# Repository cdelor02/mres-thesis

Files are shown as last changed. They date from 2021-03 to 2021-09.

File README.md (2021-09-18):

Thesis for Masters in Research in [Medical Robotics and Image Guided Intervention](https://www.imperial.ac.uk/study/pg/medicine/medical-robotics/) at [Imperial College London](https://www.imperial.ac.uk), 2020-2021.

- Remember to run the setup for EIDORS in MATLAB if it isn't already on the path

Packages and modules used:
- [EIDORS](http://eidors3d.sourceforge.net)
- [gmsh](https://gmsh.info)
- [mesh2matlab](https://github.com/Jimbles/meshio2matlab)
- [OpenCV](https://opencv.org)
- [NumPy](https://numpy.org)
- [Scikit-learn](https://scikit-learn.org/stable/)
- [Tensorflow](https://www.tensorflow.org)
- [Keras](https://keras.io)
- [ffmpeg](https://www.ffmpeg.org)

Resources:
- [Soft robotics toolkit](https://softroboticstoolkit.com/home)

Software used:
- [ParaView](https://www.paraview.org)
- [SolidWorks](https://www.solidworks.com)
- [AutoCAD Inventor (v2021)](https://www.autodesk.co.uk/products/inventor/overview)
- [MATLAB](https://www.mathworks.com/products/matlab.html)
- [LabVIEW](https://www.ni.com/en-gb/shop/labview.html)
- [Arduino](https://www.arduino.cc)

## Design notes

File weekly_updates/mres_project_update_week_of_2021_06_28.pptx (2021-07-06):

## EIT x Soft Robots: project update

Week of Monday 28/06/2021

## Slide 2

Things to do/I’m doing

- Do multiple iterations of actuator tests to gather more data
- Refine actuator design (new moulds, iterate on actuator until a satisfactory design)
- Work on OpenCV point tracking to get ground truth data
- Investigate ML solutions for control problem (possibly just with voltages, may need full EIT images)

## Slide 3

SDM actuator with cable setup

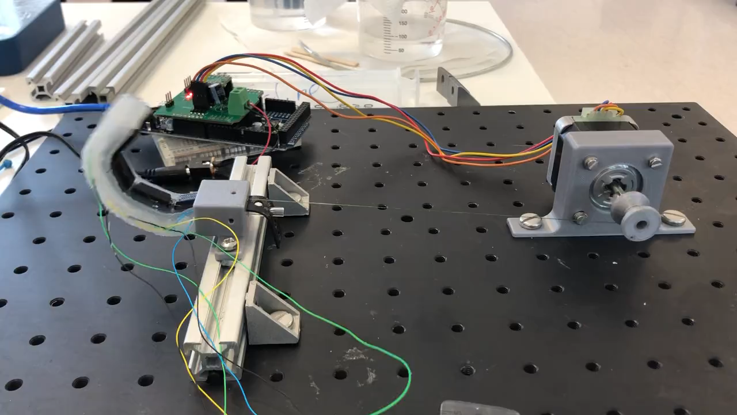
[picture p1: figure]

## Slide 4

EIT data of SDM actuator in stepper rig

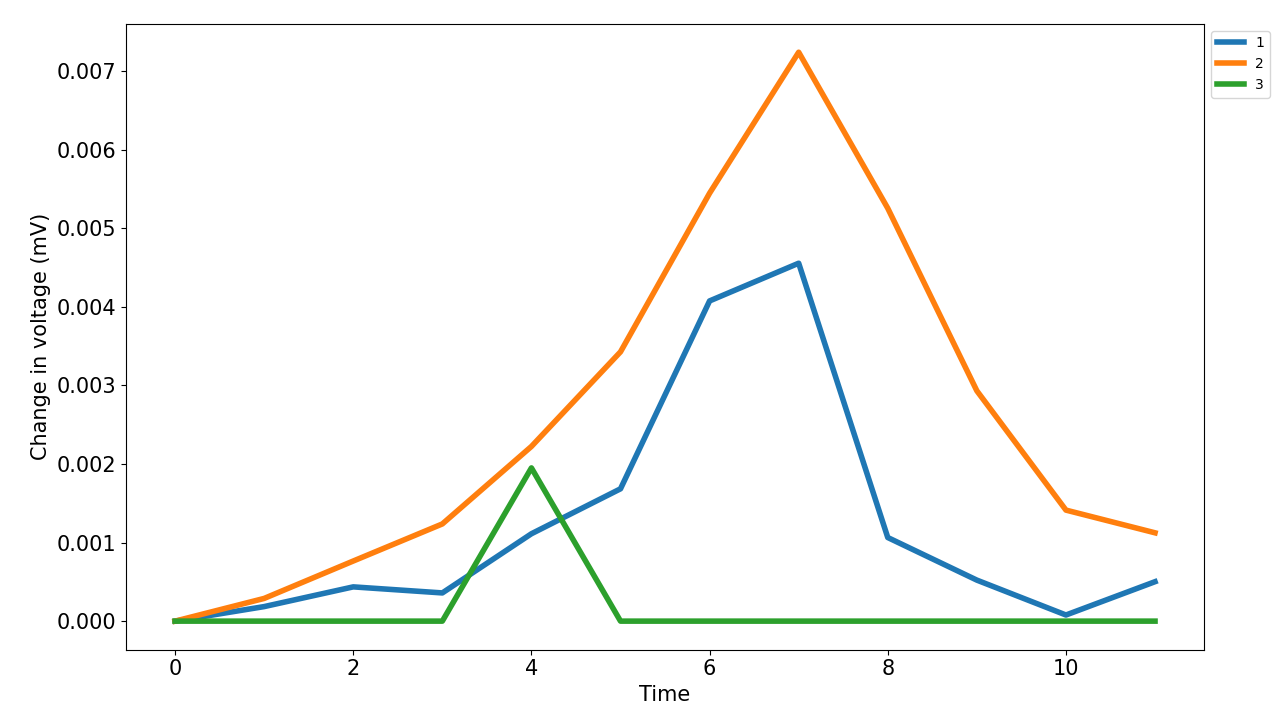
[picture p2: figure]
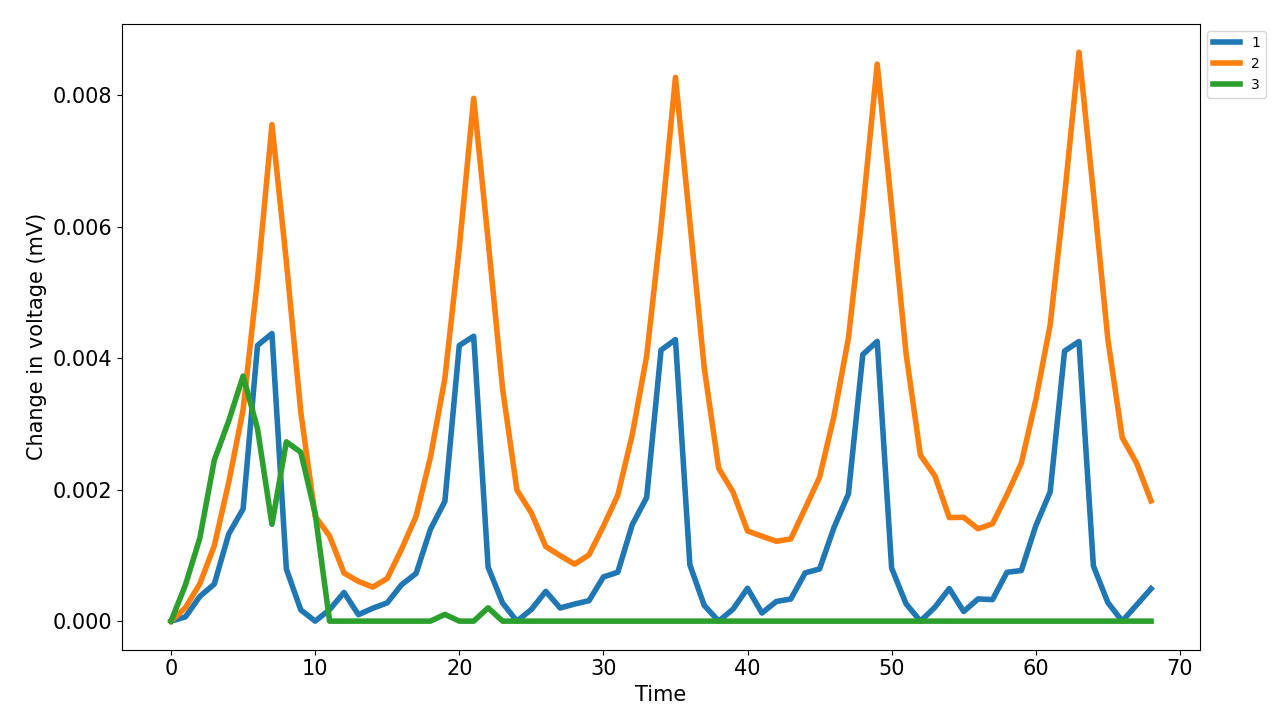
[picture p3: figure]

1 iteration

5 iterations

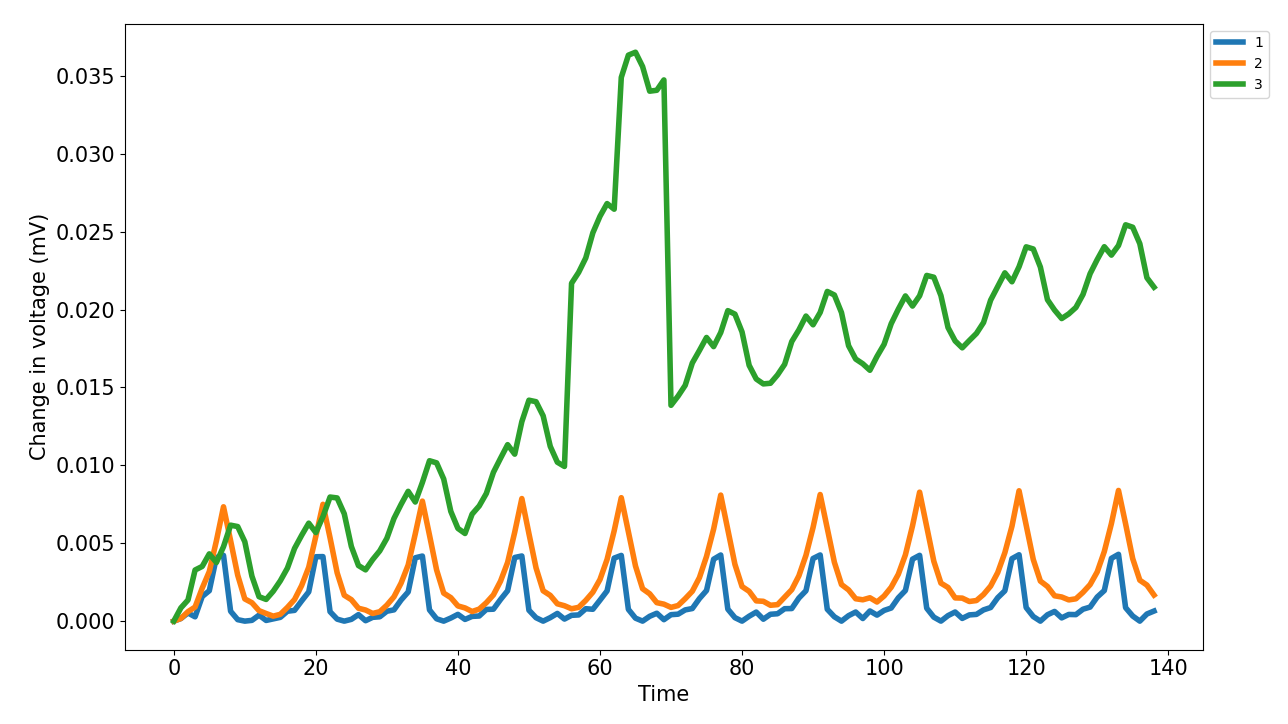
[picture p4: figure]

10 iterations

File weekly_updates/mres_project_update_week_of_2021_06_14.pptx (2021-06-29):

## EIT x Soft Robots: project update

Week of Monday 14/06/2021

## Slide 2

Project poster

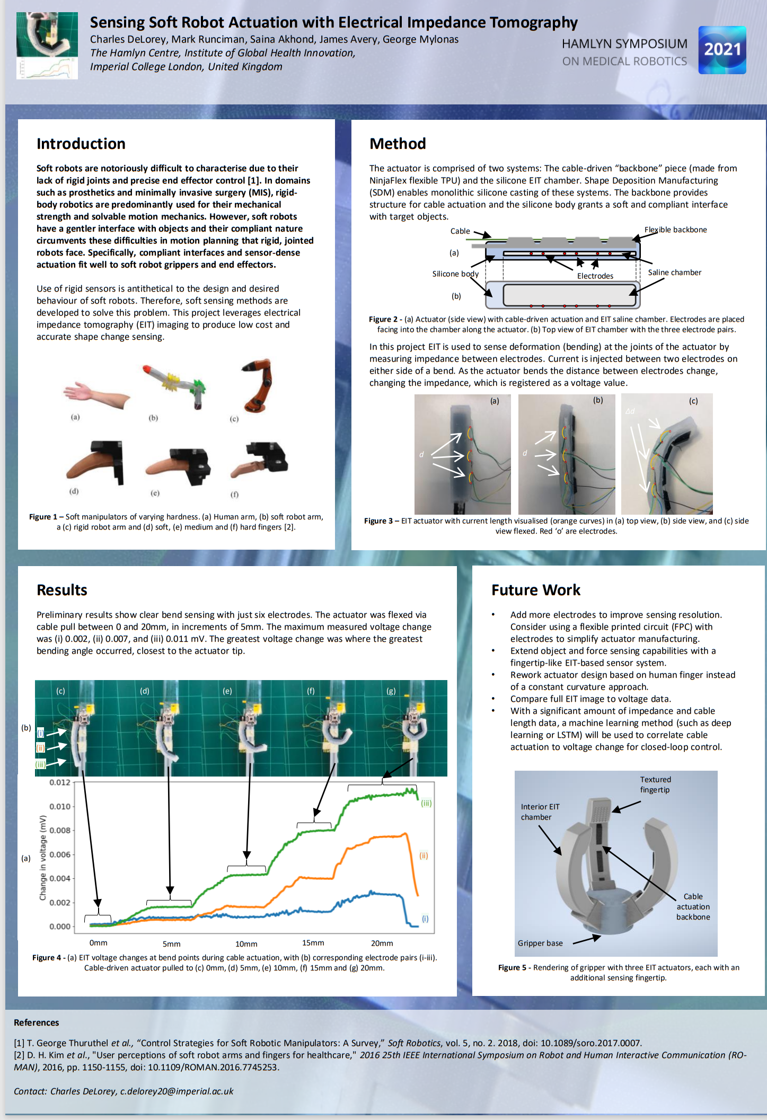
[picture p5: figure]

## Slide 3

TODO

- Add stepper motor to get set/predictable actuation
- Do multiple iterations of actuator tests to gather more data
- Investigate ML solutions for control problem (possibly just with voltages, may need full EIT images)
- Refine actuator design (new moulds, iterate on actuator until a satisfactory design)

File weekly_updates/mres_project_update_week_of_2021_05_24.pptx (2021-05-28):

## EIT x Soft Robots: project update

Week of Monday 24/05/2021

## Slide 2

Actuator with anterior EIT chamber

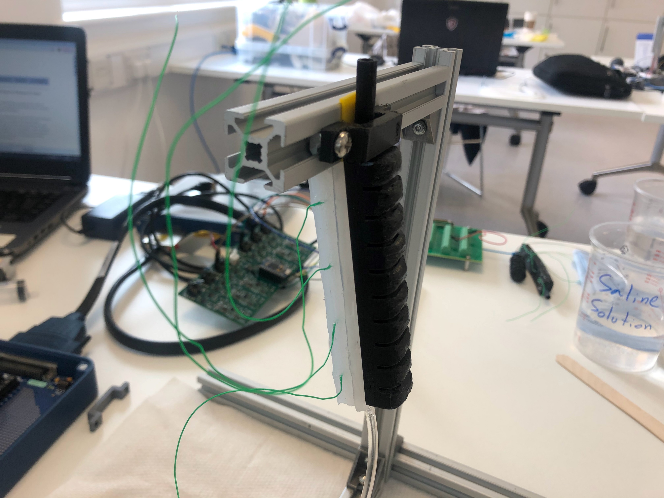
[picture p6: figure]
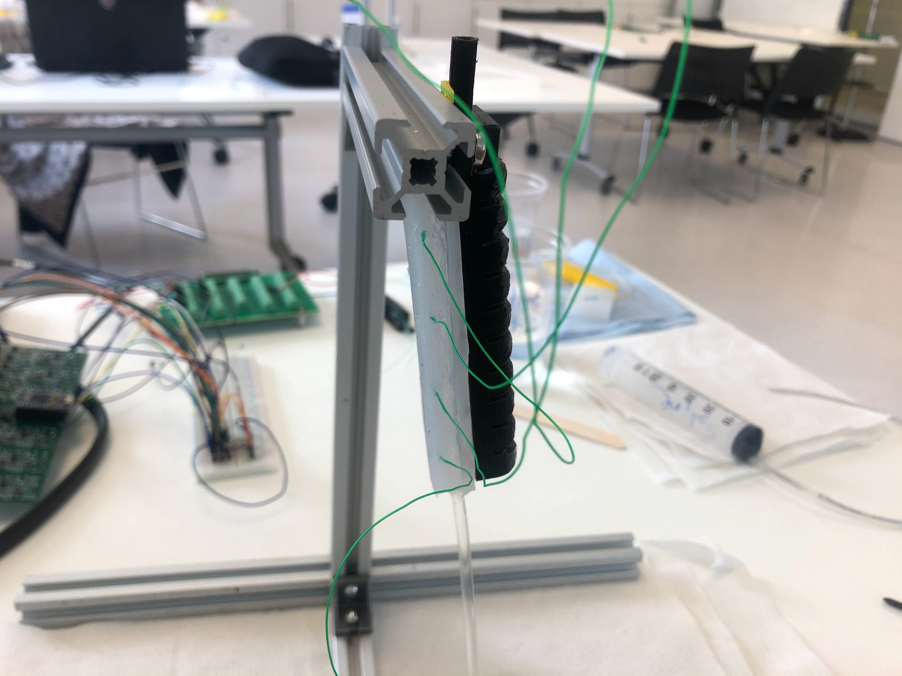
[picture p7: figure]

Silicone layer to affix EIT chamber to actuator surface

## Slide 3

Actuator with anterior EIT chamber

Noise?

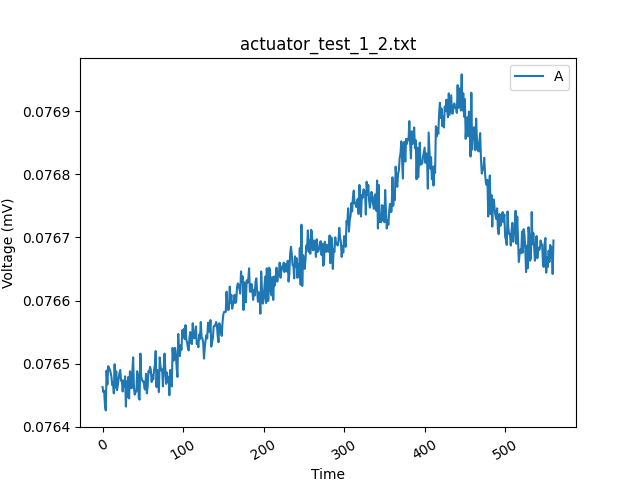
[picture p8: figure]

Voltage reading over a 60ml pneumatic actuation (10ml at a time, ~1-2s per 10ml)

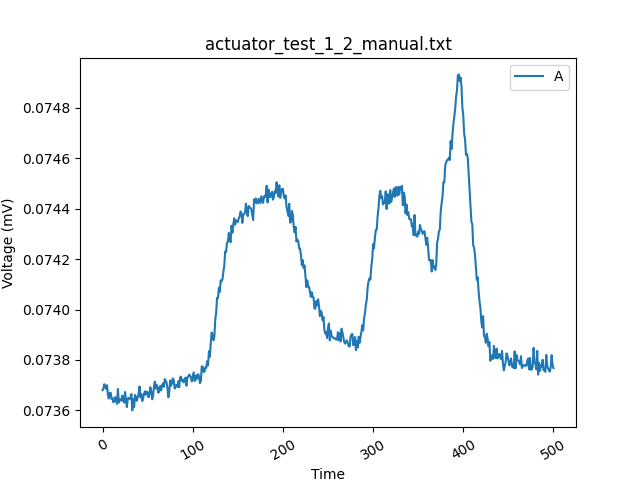
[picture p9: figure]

Actuated, but not enough change to see difference

Actuated to 22.5°

Actuated to 22.5°

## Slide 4

New idea: SDM actuator with EIT chamber

Noise?

Voltage reading over a 60ml pneumatic actuation (10ml at a time, ~1-2s per 10ml)

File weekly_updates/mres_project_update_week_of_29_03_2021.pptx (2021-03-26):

## EIT x Soft Robots: project update

Week of Monday 29/03/2021

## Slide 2

Work accomplished this past week:

- Refined EIDORS simulation
- Begin fabricating a simple actuator

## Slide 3

Pneunet mesh with electrode locations

6 electrodes
Lengths are in meters

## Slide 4

EIDORS simulations of simple 2-joint actuator

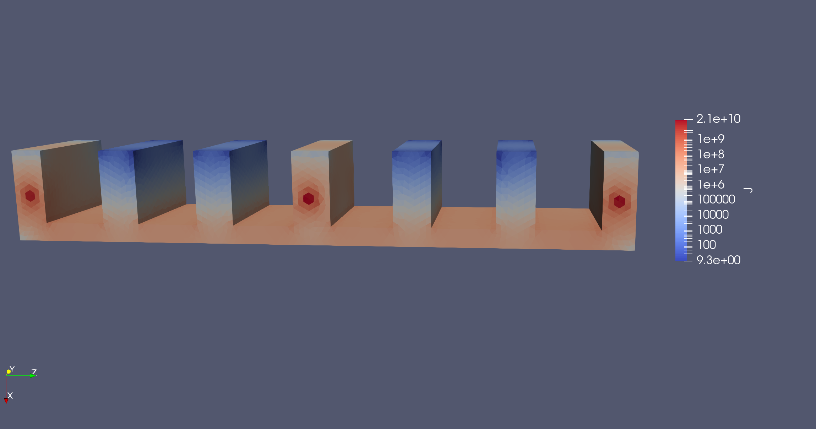
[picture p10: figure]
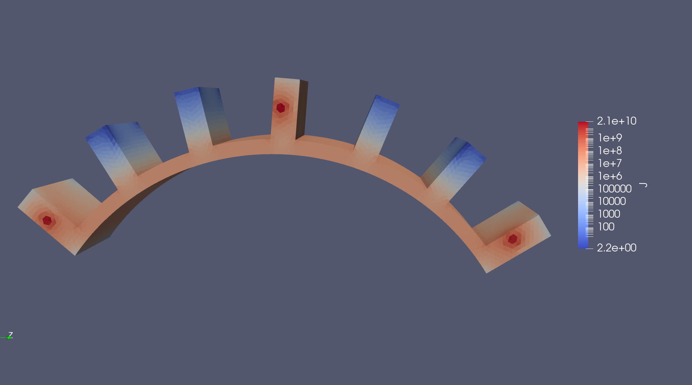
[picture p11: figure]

No bend

First bend

- Visualized with ParaView
- Log scale

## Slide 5

Voltages for each finger configuration:

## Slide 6

To do for this upcoming week:

- ~~Refine EIDORS simulation~~
- ~~Begin fabricating a simple actuator~~
- ~~Revise literature review~~

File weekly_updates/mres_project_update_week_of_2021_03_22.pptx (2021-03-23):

## EIT x Soft Robots: project update

Week of Monday 22/03/2021

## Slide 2

Work accomplished this past week:

- Completed online training courses
- Produced EIT images of simple finger model

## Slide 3

Finger mesh with electrode locations

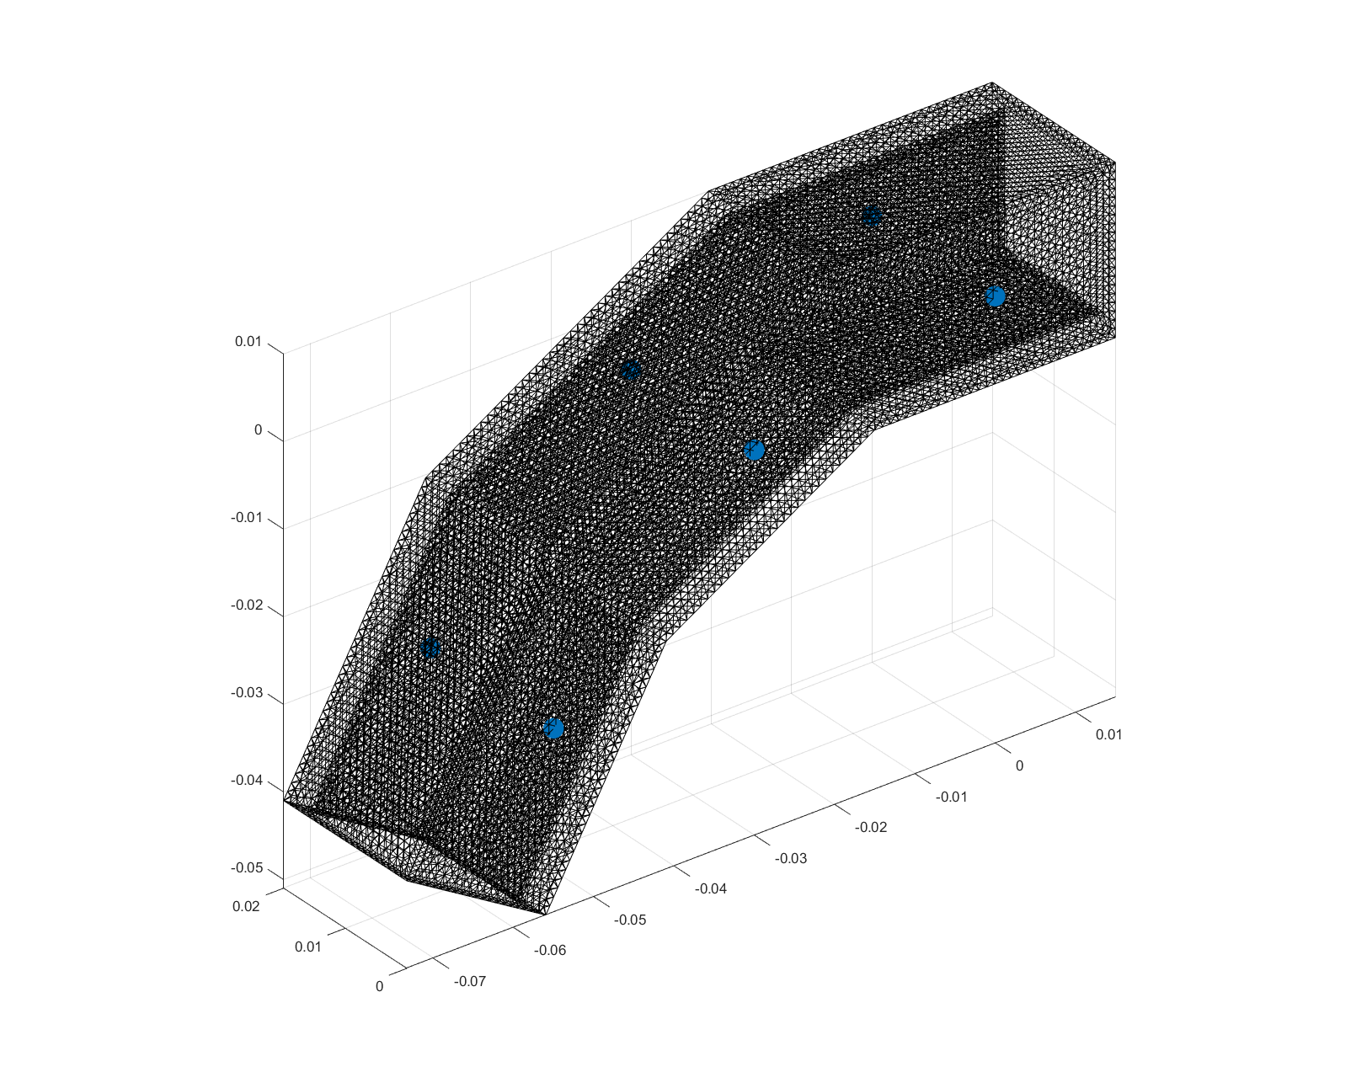
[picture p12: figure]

6 electrodes
Actuator wall is 2 mm thick
Lengths are in meters

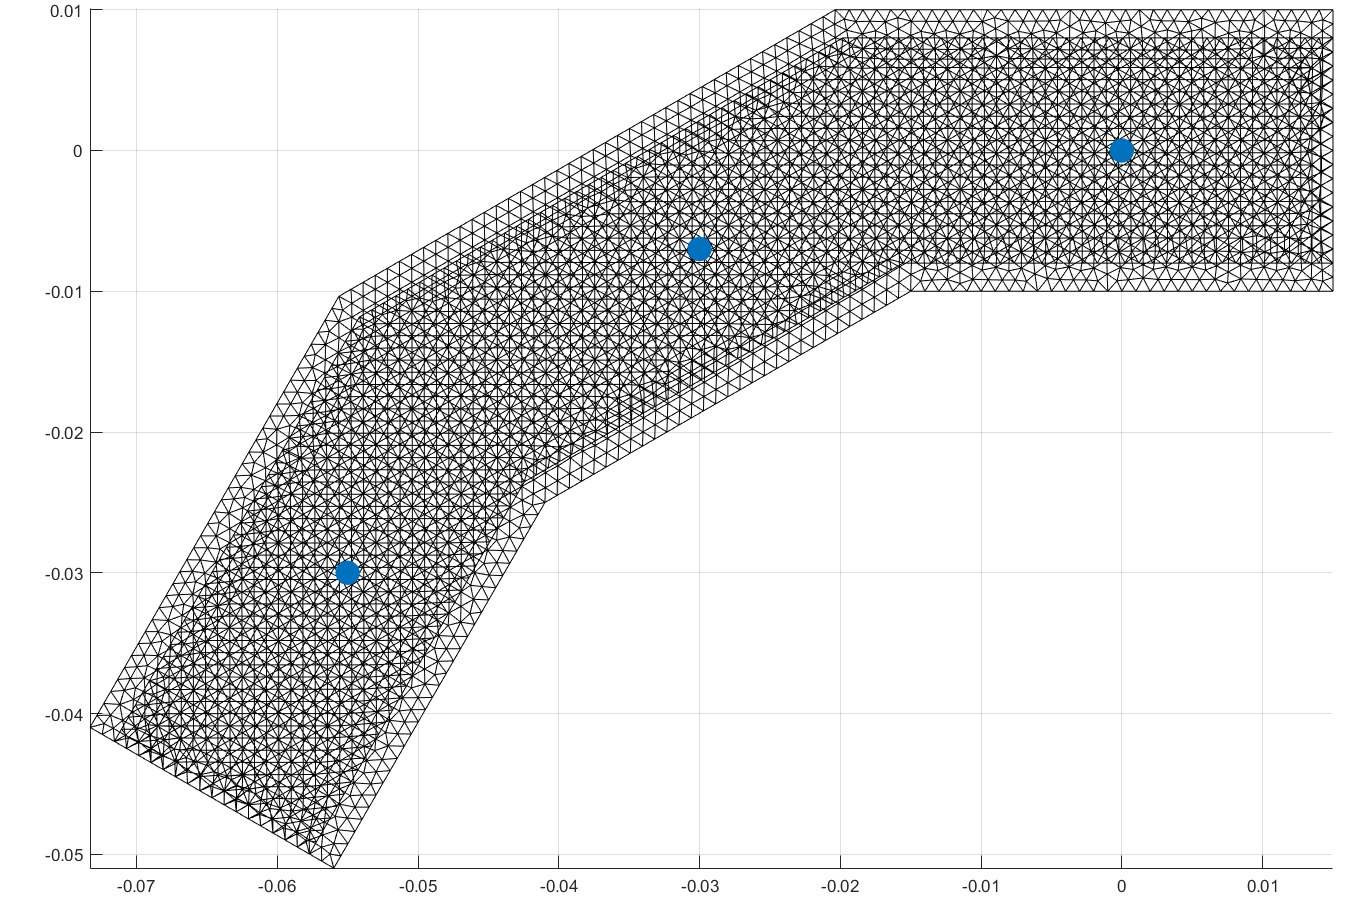
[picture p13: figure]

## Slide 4

EIDORS simulations of simple 2-joint actuator

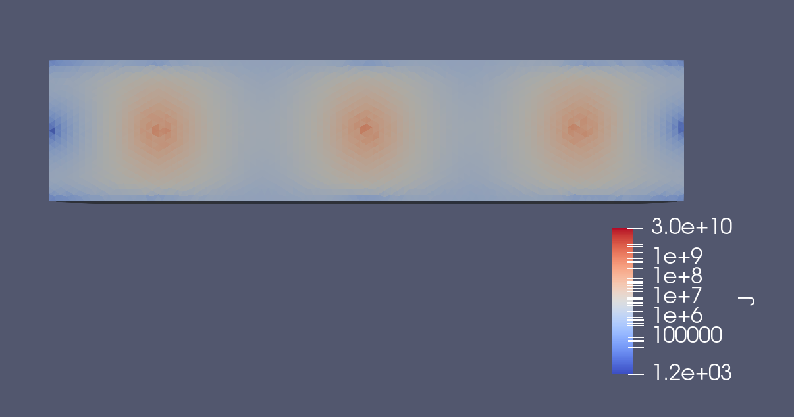
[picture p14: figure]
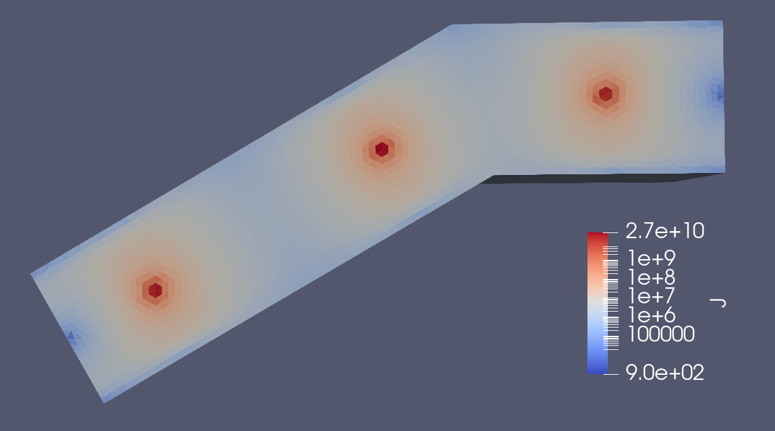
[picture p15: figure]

No bend

1 bend

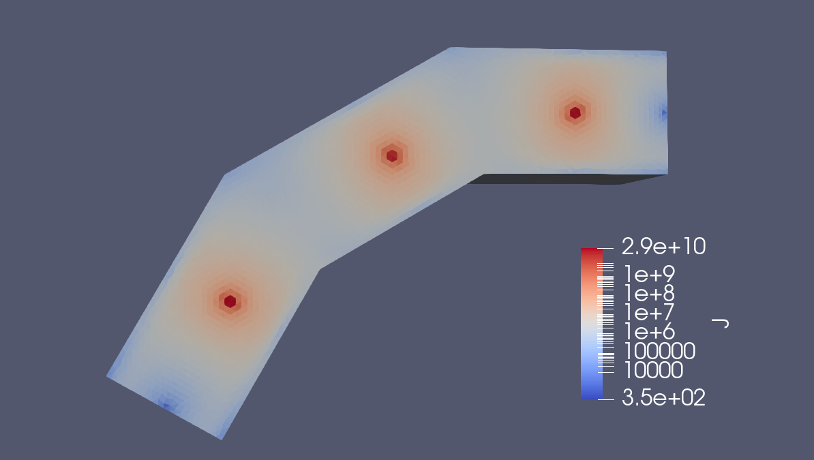
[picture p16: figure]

- Visualized with ParaView
- Log scale

2 bends

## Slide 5

Voltages for each finger configuration:

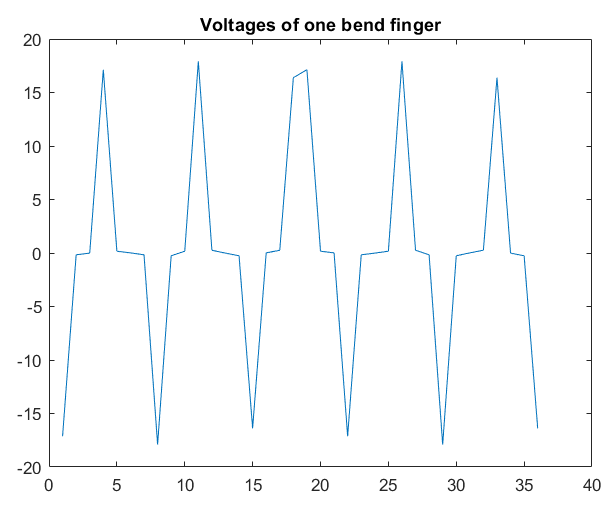
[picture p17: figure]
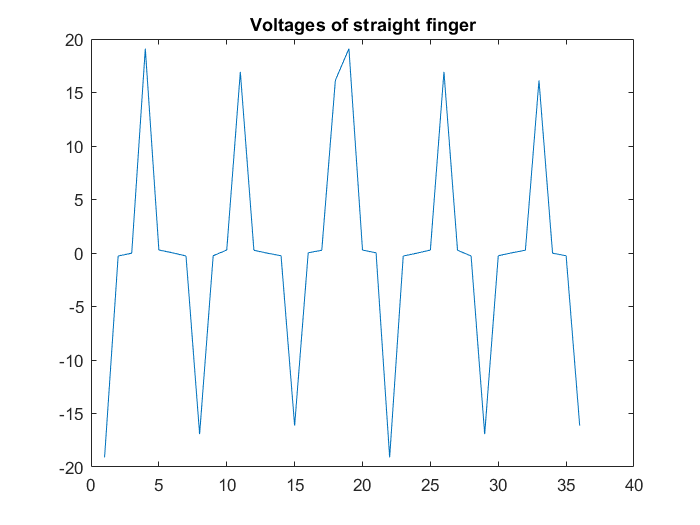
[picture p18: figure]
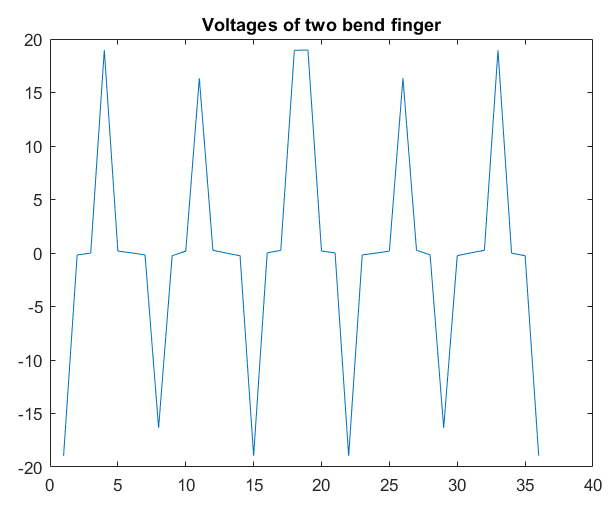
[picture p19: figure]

- Very slight changes

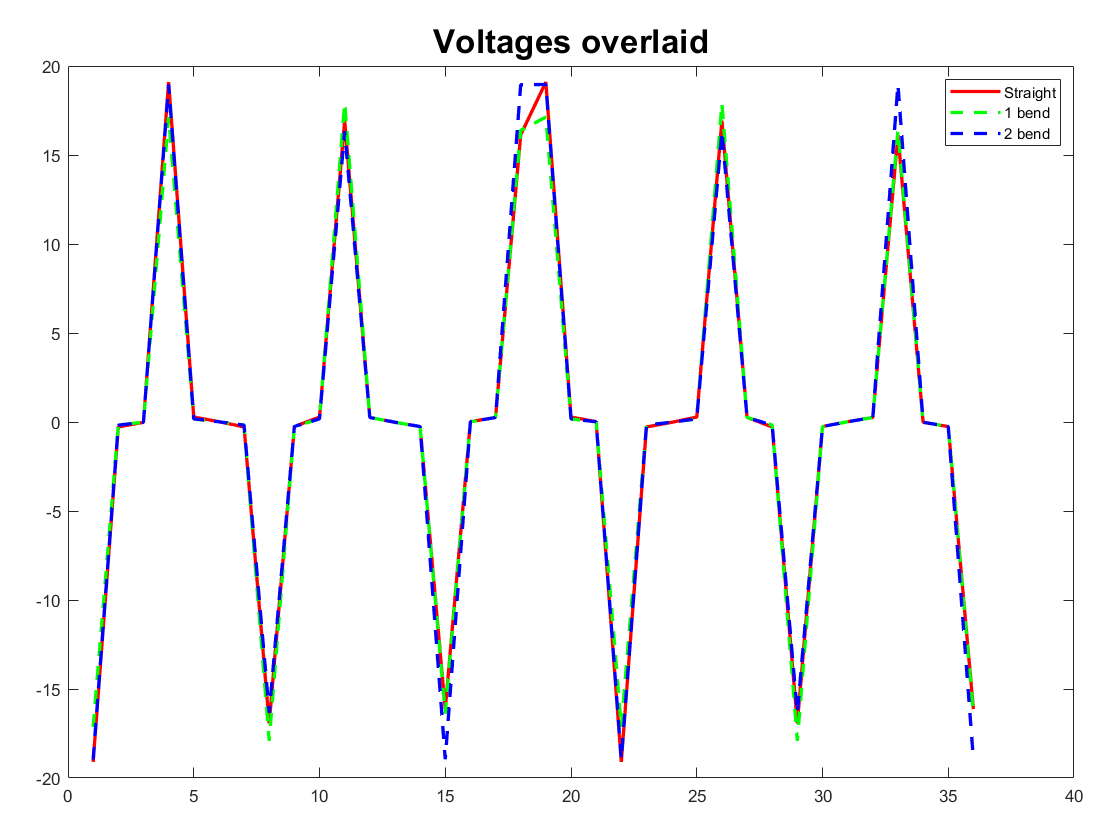
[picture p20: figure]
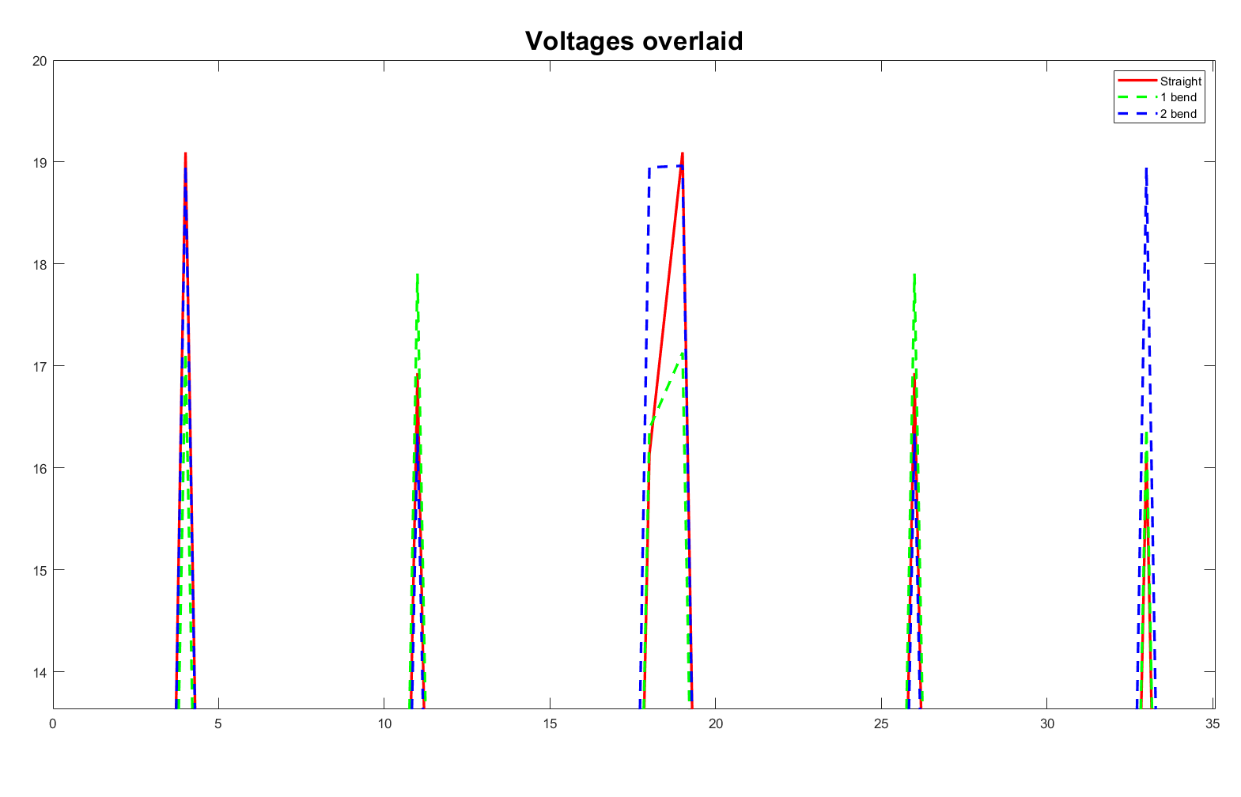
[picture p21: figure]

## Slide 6

To do for this upcoming week:

- Refine EIDORS simulation
- Begin fabricating a simple actuator
- Revise literature review

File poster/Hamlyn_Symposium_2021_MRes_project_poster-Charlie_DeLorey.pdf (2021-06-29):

# Introduction

Soft robots are notoriously difficult to characterise due to their lack of rigid joints and precise end effector control [1]. In domains such as prosthetics and minimally invasive surgery (MIS), rigidbody robotics are predominantly used for their mechanical strength and solvable motion mechanics. However, soft robots have a gentler interface with objects and their compliant nature circumvents these difficulties in motion planning that rigid, jointed robots face. Specifically, compliant interfaces and sensor-dense actuation fit well to soft robot grippers and end effectors.

Use of rigid sensors is antithetical to the design and desired behaviour of soft robots. Therefore, soft sensing methods are developed to solve this problem. This project leverages electrical impedance tomography (EIT) imaging to produce low cost and accurate shape change sensing.

# Method

The actuator is comprised of two systems: The cable-driven “backbone” piece (made from NinjaFlex flexible TPU) and the silicone EIT chamber. Shape Deposition Manufacturing (SDM) enables monolithic silicone casting of these systems. The backbone provides structure for cable actuation and the silicone body grants a soft and compliant interface with target objects.

# Future Work

- Add more electrodes to improve sensing resolution. Consider using a flexible printed circuit (FPC) with electrodes to simplify actuator manufacturing.
- Extend object and force sensing capabilities with a fingertip-like EIT-based sensor system.
- Rework actuator design based on human finger instead of a constant curvature approach.
- Compare full EIT image to voltage data.
- With a significant amount of impedance and cable length data, a machine learning method (such as deep learning or LSTM) will be used to correlate cable actuation to voltage change for closed-loop control.

# Results

Preliminary results show clear bend sensing with just six electrodes. The actuator was flexed via cable pull between 0 and 20mm, in increments of 5mm. The maximum measured voltage change was (i) 0.002, (ii) 0.007, and (iii) 0.011 mV. The greatest voltage change was where the greatest bending angle occurred, closest to the actuator tip.

# Sensing Soft Robot Actuation with Electrical Impedance Tomography

Charles DeLorey, Mark Runciman, Saina Akhond, James Avery, George Mylonas
The Hamlyn Centre, Institute of Global Health Innovation,
Imperial College London, United Kingdom

References

[1] T. George Thuruthel et al., “Control Strategies for Soft Robotic Manipulators: A Survey,” Soft Robotics, vol. 5, no. 2. 2018, doi: 10.1089/soro.2017.0007.
[2] D. H. Kim et al., "User perceptions of soft robot arms and fingers for healthcare," 2016 25th IEEE International Symposium on Robot and Human Interactive Communication (RO-MAN), 2016, pp. 1150-1155, doi: 10.1109/ROMAN.2016.7745253.

Contact: Charles DeLorey, c.delorey20@imperial.ac.uk

Figure 2 - (a) Actuator (side view) with cable-driven actuation and EIT saline chamber. Electrodes are placed facing into the chamber along the actuator. (b) Top view of EIT chamber with the three electrode pairs.

Figure 5 - Rendering of gripper with three EIT actuators, each with an additional sensing fingertip.

Figure 1 – Soft manipulators of varying hardness. (a) Human arm, (b) soft robot arm, a (c) rigid robot arm and (d) soft, (e) medium and (f) hard fingers [2].

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
Figure 3 – EIT actuator with current length visualised (orange curves) in (a) top view, (b) side view, and (c) side view flexed. Red ‘o’ are electrodes.

In this project EIT is used to sense deformation (bending) at the joints of the actuator by measuring impedance between electrodes. Current is injected between two electrodes on either side of a bend. As the actuator bends the distance between electrodes change, changing the impedance, which is registered as a voltage value.

Figure 4 - (a) EIT voltage changes at bend points during cable actuation, with (b) corresponding electrode pairs (i-iii). Cable-driven actuator pulled to (c) 0mm, (d) 5mm, (e) 10mm, (f) 15mm and (g) 20mm.

Cable | Flexible backbone
Silicone body | Saline chamber Electrodes

(a)

(b)

Textured
fingertip

Gripper base

Interior EIT
chamber

Cable
actuation
backbone

(a)

(b) | (c) | (d) | (e) | (f) (c) | (d) | (e) | (f) | (g)
(b) (i)

(ii)

(iii)

0mm | 5mm | 10mm | 15mm | 20mm

(iii)

(ii)

(i)

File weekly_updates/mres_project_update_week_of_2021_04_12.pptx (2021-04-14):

## EIT x Soft Robots: project update

Week of Monday 12/04/2021

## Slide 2

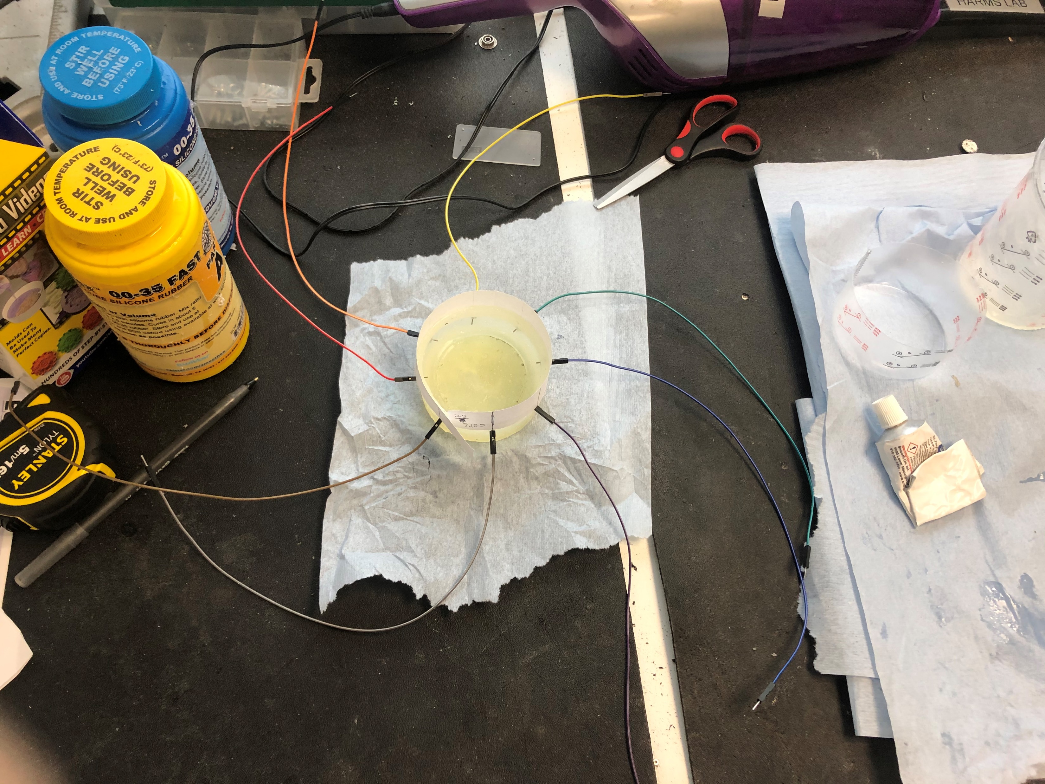
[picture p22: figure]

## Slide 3

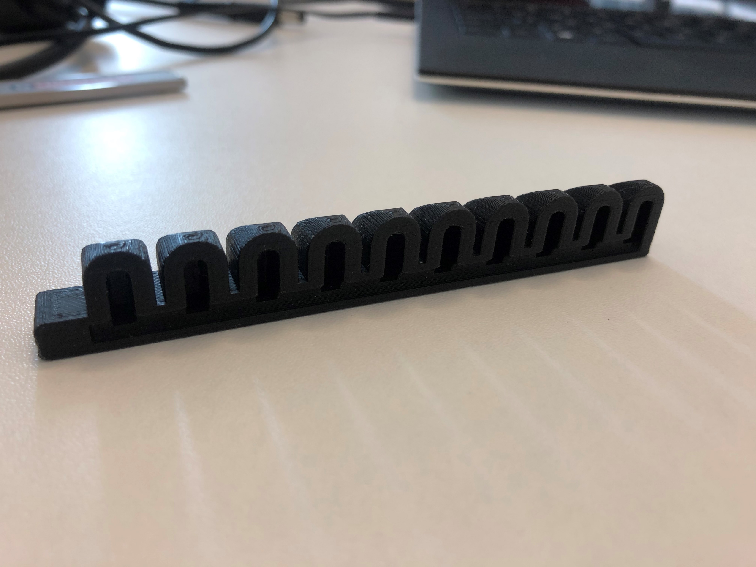
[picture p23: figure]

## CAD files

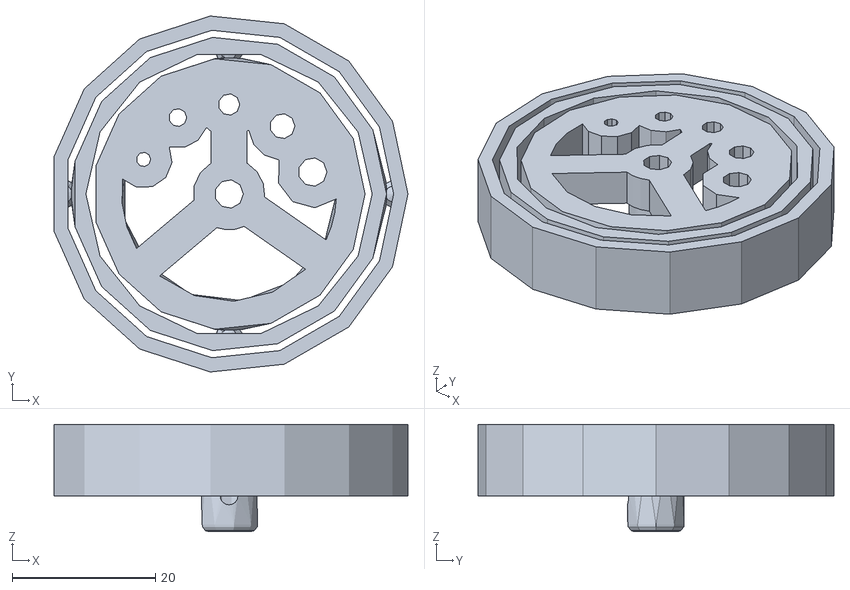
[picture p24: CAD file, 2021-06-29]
SDM_actuator/probe_gimbal/gimbal_assembly.stl
49.5 x 49.7 x 15.0

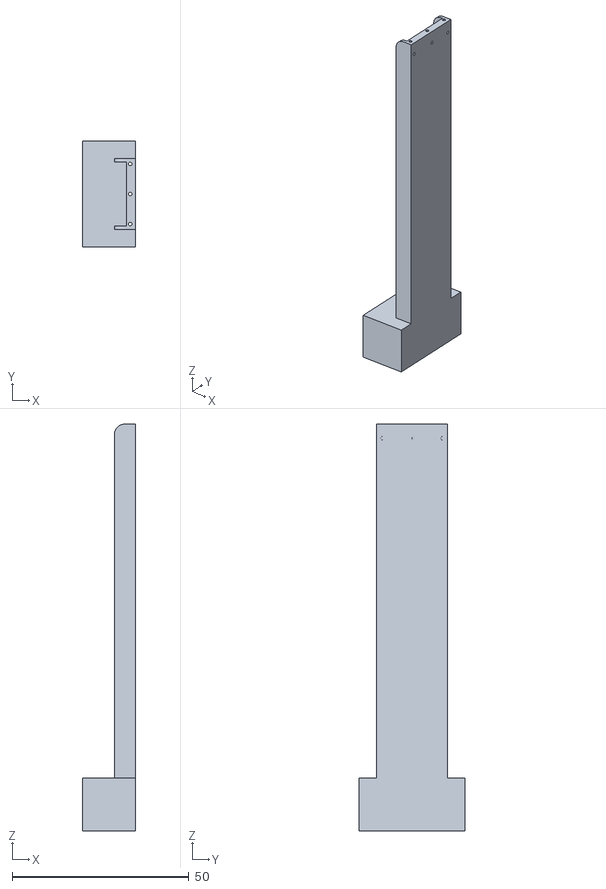
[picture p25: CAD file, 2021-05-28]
3d_printed_actuator/3D_print_actuator_cable_driven.stl
15.0 x 30.0 x 115.0

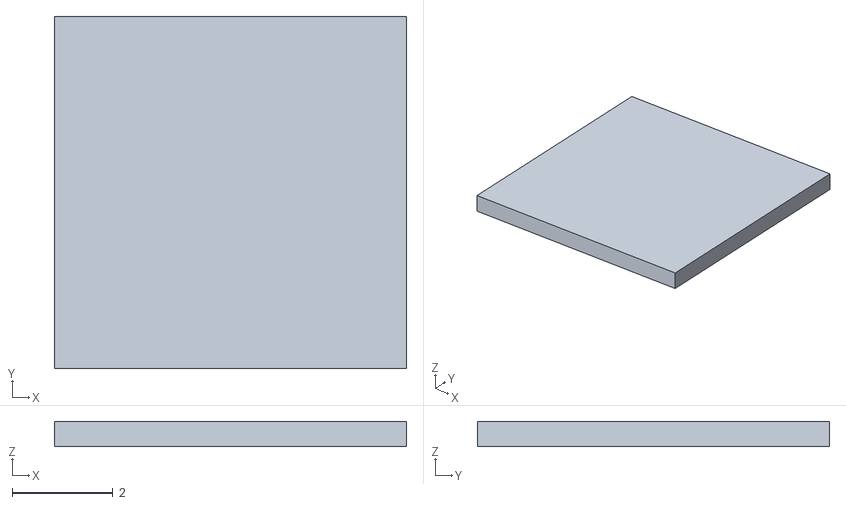
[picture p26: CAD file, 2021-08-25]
computer_vision/7mm_square.stl
7.00 x 7.00 x 0.5

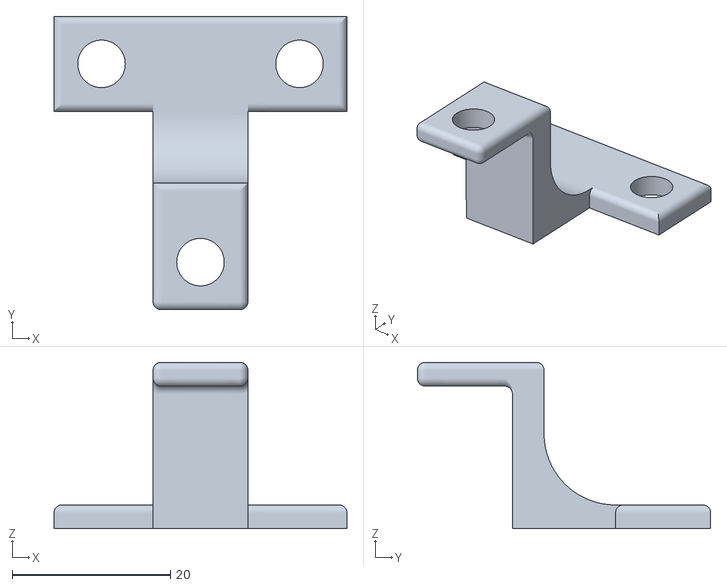
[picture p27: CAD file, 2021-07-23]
computer_vision/camera_3D_parts/new_camera_mount.stl
37.0 x 37.0 x 21.0

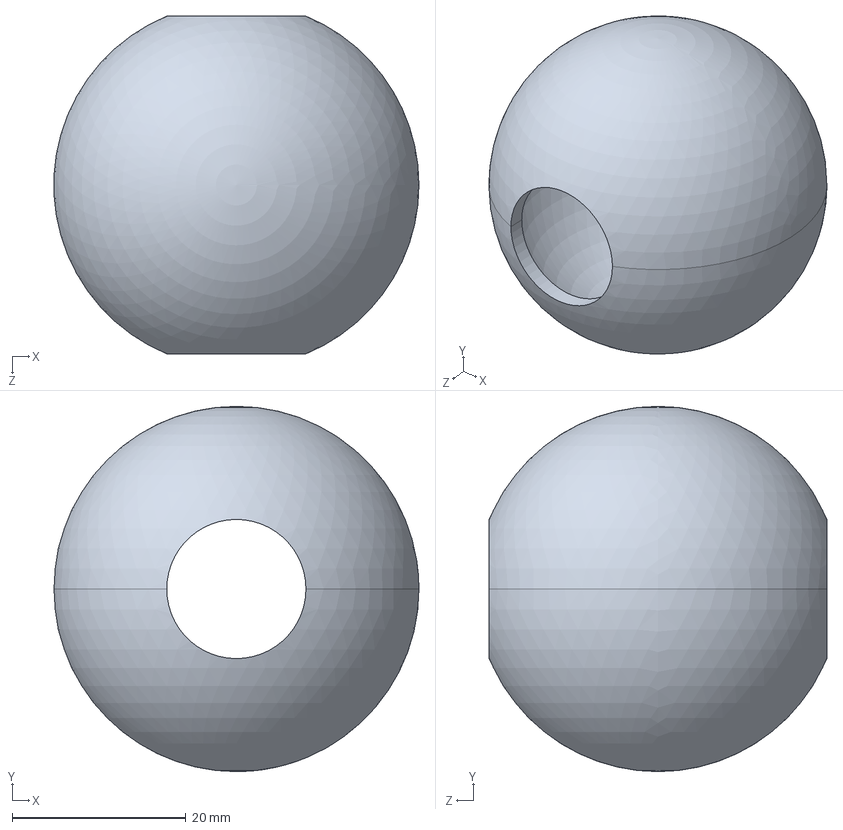
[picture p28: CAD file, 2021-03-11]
EIT_Software-master/step2eidorsexample/SensorChamber.STEP
42.0 x 42.0 x 38.8 mm

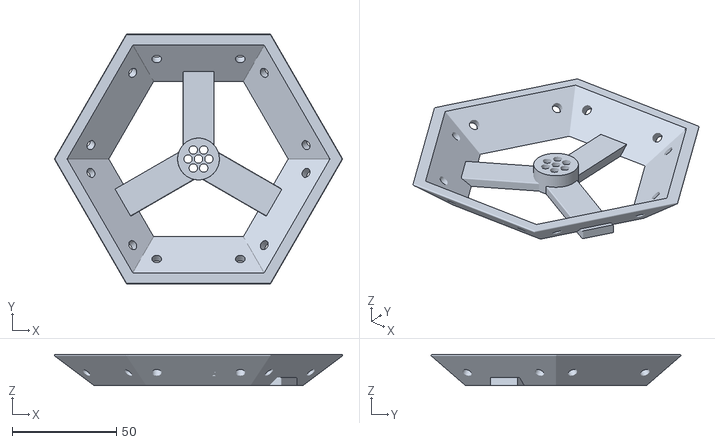
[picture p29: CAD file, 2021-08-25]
gripper_mounting.stl
137.9 x 119.6 x 15.0

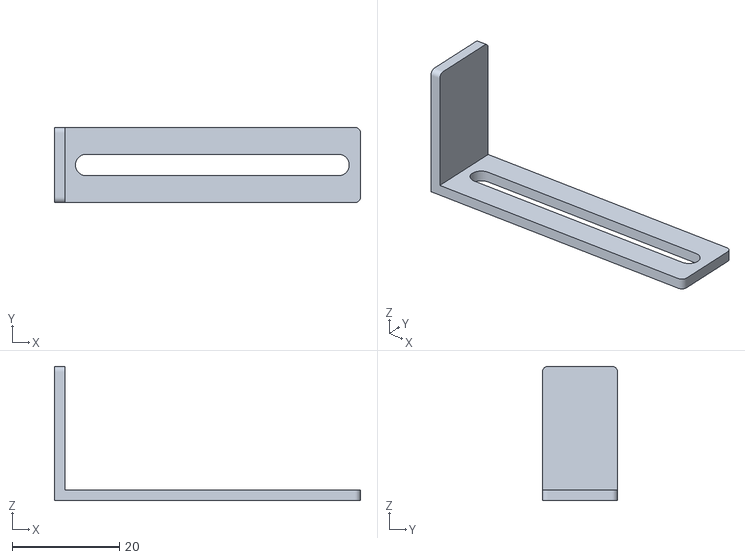
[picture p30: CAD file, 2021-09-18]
SDM_actuator/LONG-actuator_backbone_fixings_for_measurements.stl
57.0 x 14.0 x 25.0

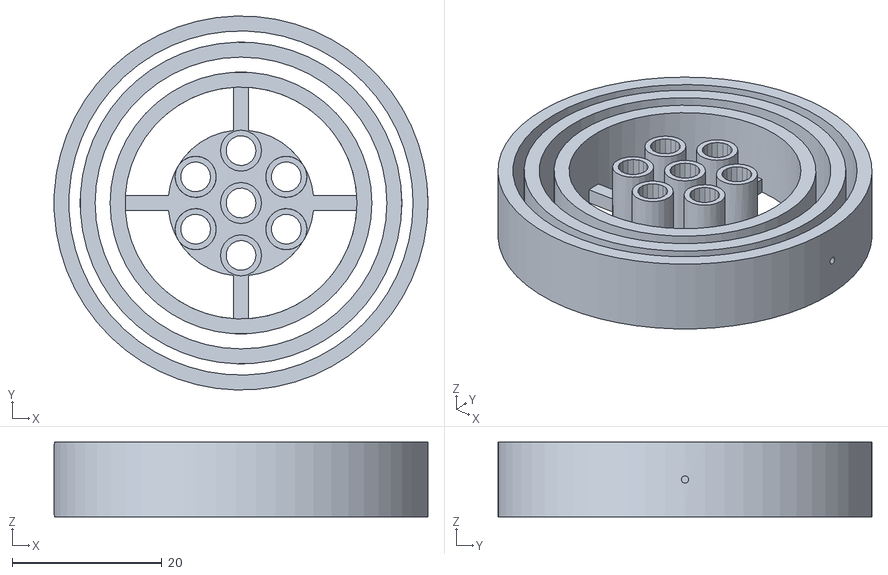
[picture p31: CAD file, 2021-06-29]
SDM_actuator/probe_gimbal/inner_only_improved_gimbal.stl
50.0 x 50.0 x 10.0

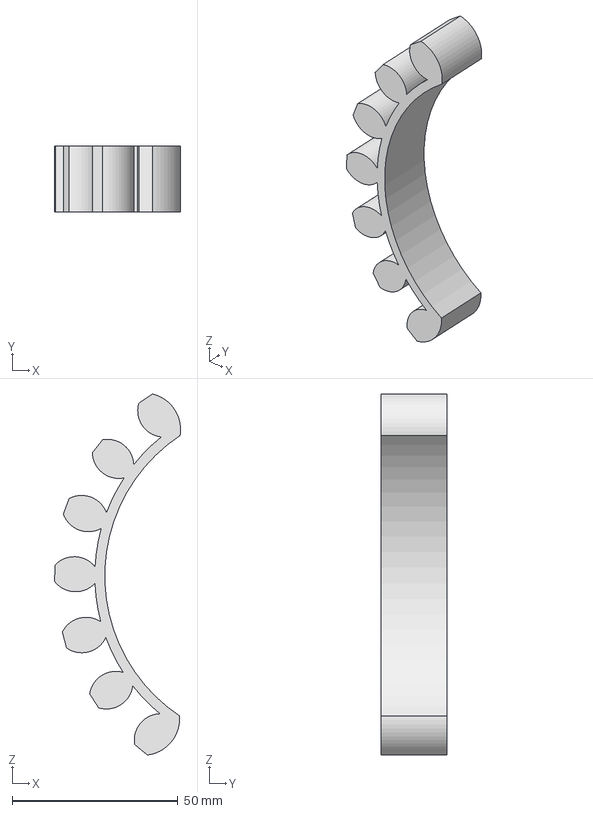
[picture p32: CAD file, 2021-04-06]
simulation/pneunet_approximate_test_first_bend_INFLATE.STEP
38.0 x 20.0 x 108.8 mm

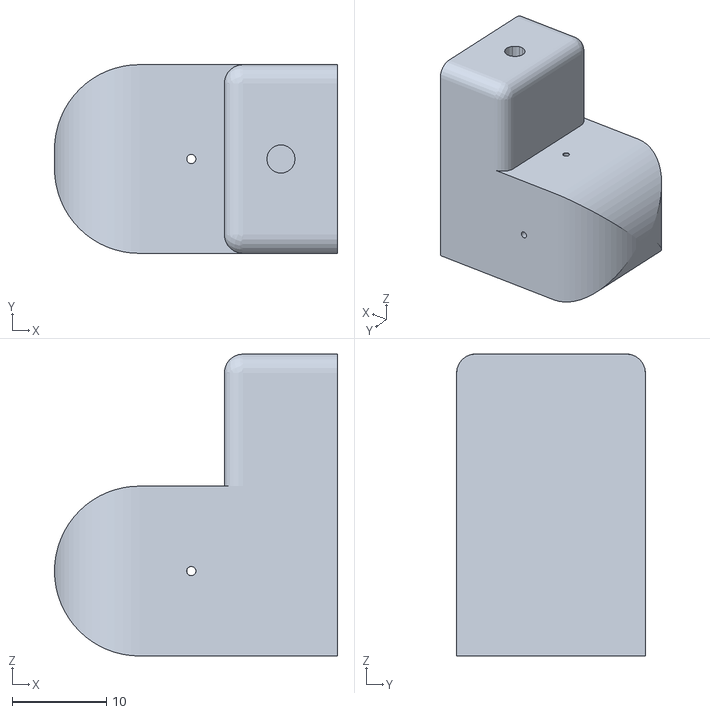
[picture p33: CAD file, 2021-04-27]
single_chamber_test/3D_print_single_chamber_electrode_holes.stl
30.0 x 20.0 x 32.0

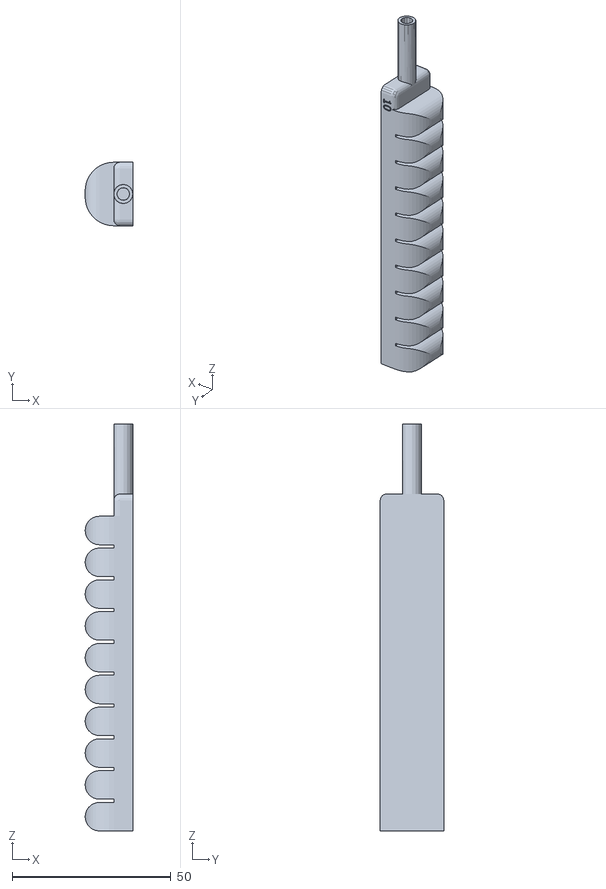
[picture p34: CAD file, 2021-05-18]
3d_printed_actuator/3D_print_actuator_no_electrode_holes.stl
15.0 x 20.0 x 128.0

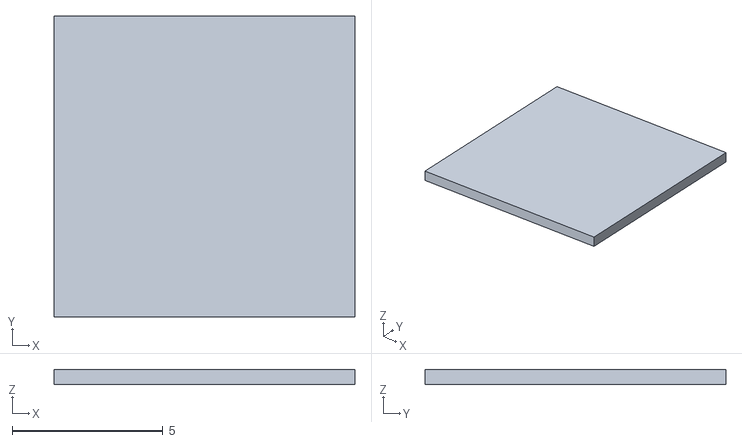
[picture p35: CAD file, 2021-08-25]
computer_vision/10mm_square.stl
10.0 x 10.0 x 0.5

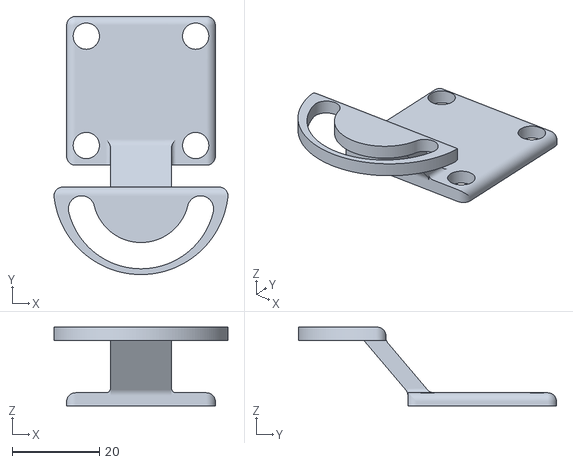
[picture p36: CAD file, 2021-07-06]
computer_vision/camera_3D_parts/camera_mount.stl
39.8 x 59.0 x 18.0

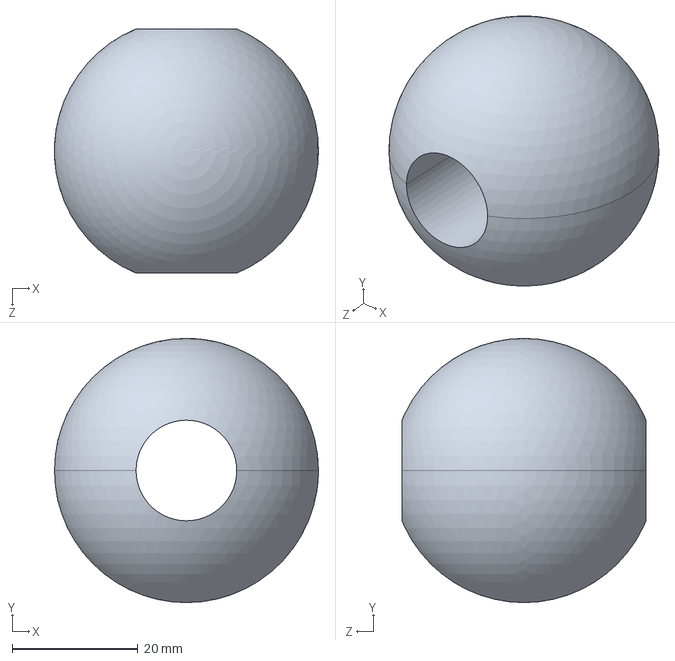
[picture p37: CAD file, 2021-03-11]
EIT_Software-master/step2eidorsexample/SensorChamberSingle.STEP
42.0 x 42.0 x 38.8 mm

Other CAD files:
SDM_actuator/actuator_backbone_fixings_for_measurements.stl
SDM_actuator/probe_gimbal/improved_gimbal_ringed_rings_just_inner.stl
simulation/pneunet_approximate_test_second_bend.STEP
single_chamber_test/3D_print_single_chamber.stl
3d_printed_actuator/3D_print_actuator.ipt
3d_printed_actuator/3D_print_actuator.stl
3d_printed_actuator/3D_print_actuator_anterior_electrodes.ipt
3d_printed_actuator/3D_print_actuator_anterior_electrodes.stl
3d_printed_actuator/3D_print_actuator_cable_driven.ipt
3d_printed_actuator/3D_print_actuator_circle_arches.stl
3d_printed_actuator/3D_print_actuator_cross-section.stl
3d_printed_actuator/3D_print_actuator_curved_arches.stl
3d_printed_actuator/3D_print_actuator_interior_arches.stl
3d_printed_actuator/3D_print_actuator_lengthwise_electrodes.ipt
3d_printed_actuator/3D_print_actuator_lengthwise_electrodes.stl
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

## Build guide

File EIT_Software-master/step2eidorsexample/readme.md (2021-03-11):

# Converting step to tetra mesh for EIDORS

Software used:

- Solidworks to make .step files
- [gmsh](https://gmsh.info/) to convert into tetraheadral FEM
- [Meshio](https://github.com/nschloe/meshio) to save as .vtu
- [meshio2matlab](https://github.com/Jimbles/meshio2matlab) to load .msh and .vtu into matlab
- [EIDORS](http://eidors3d.sourceforge.net/) for EIT calculations
- [Paraview](https://www.paraview.org/) to view .vtu files in 3D

## Simple single chamber

1. Run `MakeSensorMeshes.py` which converts `SensorChamber.STEP` to `SensorChamberSingle.STEP` and `SensorChamberSingle.VTU`
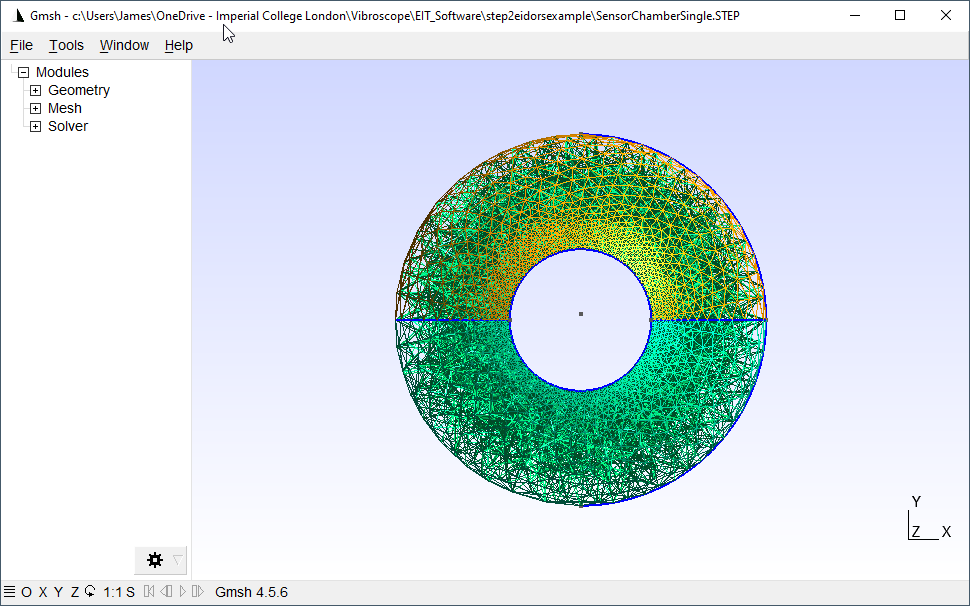
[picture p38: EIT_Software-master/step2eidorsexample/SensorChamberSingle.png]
Gmsh out


2. Run `Gmsh2Eidorsexample.m` which adds 8 electrodes in a ring in the centre and simulates a simple "adjacent" protocol. The current density is saved to a file `single_currentmag.vtu'` and the total sensitivity is saved to `single_J.vtu`.

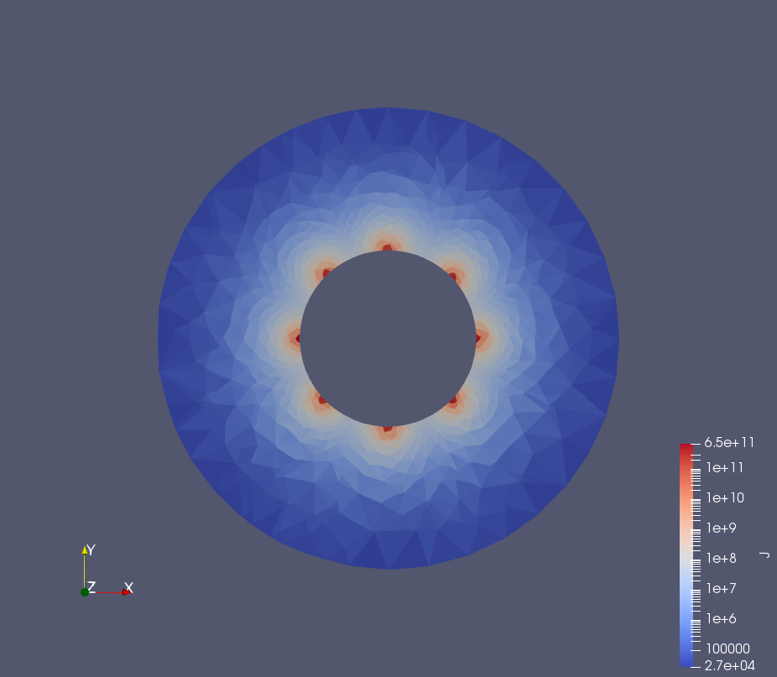
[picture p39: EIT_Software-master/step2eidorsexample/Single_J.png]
Single chamber J
3. view in paraview using the `.pvsm` 

## Thin walled chamber

As above using `MakeSensorMeshesThinWalled.py` and `Gmsh2EidorsexampleThinWalled.m`

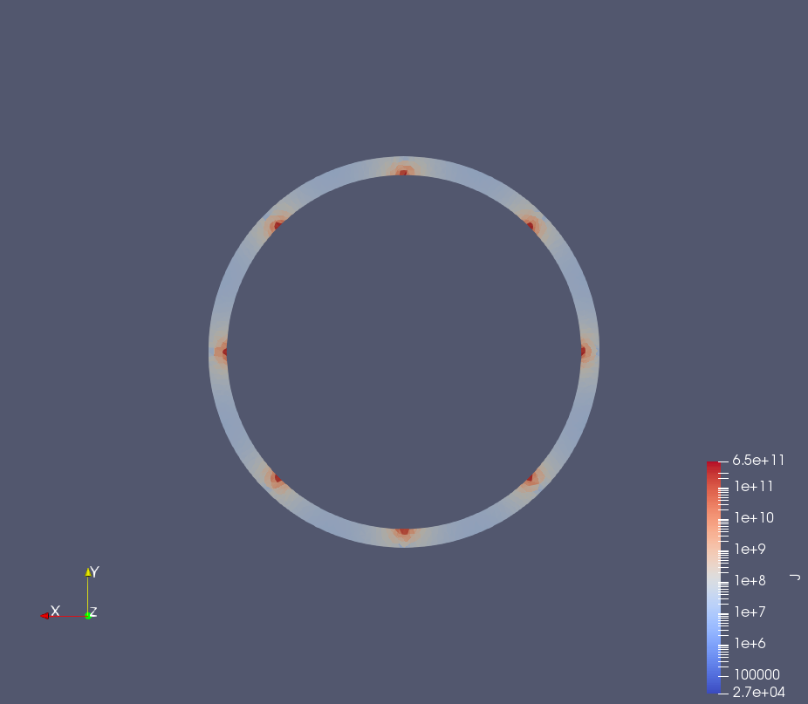
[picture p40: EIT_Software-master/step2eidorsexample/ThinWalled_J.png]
Thingwalled


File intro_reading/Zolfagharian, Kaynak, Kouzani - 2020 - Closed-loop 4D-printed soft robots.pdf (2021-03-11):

## Closed-loop 4D-printed soft robots

## Ali Zolfagharian ⁎, Akif Kaynak, Abbas Kouzani

School of Engineering, Deakin University, Geelong 3216, Australia

HIGHLIGHTS

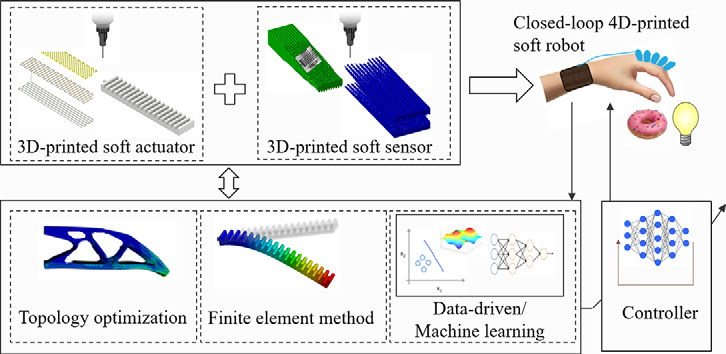
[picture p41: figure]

- Review of integrated 3D-printed soft sensors and actuators
- Discussions of closed loop 4D printing empowered by machine learning modelling
- Overview of applications of 4D-printed soft robots
- Analysis of control approaches in 3D-printed soft robots

GRAPHICAL ABSTRACT

article info | abstract
Article history: Received 4 July 2019 Received in revised form 18 November 2019 Accepted 6 December 2019 Available online 12 December 2019 | Soft robotics is a recent and rapidly growing field of research that encompasses emerging advances in functional materials, fabrication, modelling, and performance control with important applications in the manipulation of fragile objects. The incorporation of three-dimensional (3D) printing into the fabrication of soft robots facilitates the customisation of their functions by the strategic placement of functional materials into locations that may be inaccessible by conventional manufacturing methods. Most current 3D-printed soft robots, however, are fabri- cated without considering their autonomy. In four-dimensional (4D) printing, the functionality of a soft robot is introduced during the printing process. To control this functionality, specific functional materials are embed- ded in desired locations. Four-dimensional printing and machine learning techniques provide new possibilities for developing stand-alone closed-loop 4D-printed soft robots. This review paper presents the current ap- proaches employed to design and construct 4D-printed soft robots with customised geometrical, functional, and control properties. © 2019 The Author(s). Published by Elsevier Ltd. This is an open access article under the CC BY-NC-ND license

(http://creativecommons.org/licenses/by-nc-nd/4.0/).

Keywords:
Closed-loop
4D printing
Soft robot
Machine learning
Control

Contents

Materials and Design 188 (2020) 108411 (https://doi.org/10.1016/j.matdes.2019.108411)

⁎ Corresponding author.
E-mail address: a.zolfagharian@deakin.edu.au (A. Zolfagharian).

https://doi.org/10.1016/j.matdes.2019.108411
0264-1275/© 2019 The Author(s). Published by Elsevier Ltd. This is an open access article under the CC BY-NC-ND license (http://creativecommons.org/licenses/by-nc-nd/4.0/).

Contents lists available at ScienceDirect (http://www.sciencedirect.com/science/journal/)

# Materials and Design

journal homepage: www.elsevier.com/locate/matdes

1. Introduction

Three-dimensional (3D)-printed soft robots have considerably attracted the interest of research communities and industry [1–4]. The increasing scope of their applications demands autonomy in their operation so that they can independently function in dynamic environments. A closed-loop four-dimensional (4D)-printed soft robot should be capable of responding to environmental interactions and stimuli without the necessity of accepting any commands from external systems or users. Closed-loop 4D printing integrates 3D-printed sensors, 3D-printed actuators, and control policies not only to optimise the configuration of responsive materials but also to equip them with feedback information and accomplish the functional target over time while interacting with uncertain environments in real-time.
The complexities involved in the modelling and control of 3D-printed soft robots, however, have limited the utilisation of these robots in real-world applications [5]. Although most current soft robots have been 3D printed, modelled, and ultimately controlled, they would not qualify as autonomous. To yield the desired spatio-temporal transformation over time in response to environmental stimuli, four-dimensional printing [6–8] provides new directions and capabilities for the integration of stimului-responsive materials as both sensors and actuators during the manufacturing stage in a programmable and estimable approach. In this study, closed-loop 4D-printed soft robots are developed by integrating 3D-printed sensors, actuators, data-driven/machine learning (ML) model, and dynamic control to handle real-world uncertainties that have not been considered in previous 4D-printing research.
Closed-loop 4D-printed soft robots have potential applications in classification, grasping, and sorting tasks in the food and agricultural industries [9]. For example, these can be used as climbing or crawling agents for monitoring inaccessible environments, pipe inspections, search and rescue missions [10], and hydrogel-based drug delivery devices because of their water-soluble and ingestible properties [1]. Origami-like soft robots can provide variable stiffness with higher efficiency and dexterity required in specific tasks, which conventional robots cannot handle [11]. Closed-loop 4D-printed soft robots may be also used in autonomous surgeries, laparoscopy, and endoscopy [12,13]. To achieve robotic autonomy, sensory feedback control is essential. The addition of sensory feedback information to control a soft robot through the 3D printing of a combined sensor and actuator to provide feedback information is critical. This in itself, however, may not be adequate for the soft robot to make autonomous decisions on the next action to take in an uncertain environment. The high dexterity and flexibility of 4D-printed soft robots lead to extensive interactions with the environment, thus making the autonomous operation inefficient because of limited experimental training data. Finite element methods (FEMs) and dynamic control techniques are therefore necessary to realise closed-loop 4D-printed soft robots. To close the feedback loop and form the aforementioned soft robot, four key components are required

(Fig. 1): (1) 3D-printed soft sensors, (2) 3D-printed soft actuators,
(3) data-driven/ML model, and (4) controller.
Closed-loop 4D-printed soft robots capable of diverse manipulation tasks are an unexploited research domain. The majority of 4D-printed soft robots cannot be adequately described by linear models mainly because they involve many degrees of freedom, material nonlinearities, and time delays. It is therefore an exigent task to formulate a viable model for the robust control of such systems in real-world applications. Machine learning techniques that circumvent the complexities of advanced mathematical models can be employed to realise the feedback control of nonlinear dynamical systems [14–16].
Machine learning indeed contributes to closed-loop 4D printing in two aspects. First, the ML approach can be adopted to develop closed-loop 4D-printed soft robots during manufacturing, where the faster optimisation of 3D printing parameters in the fabrication of 3D-printed soft sensors and actuators are desirable. To achieve maximum printing fidelity, ML algorithms can be utilised to accelerate the optimisation of relevant material properties, such as extrudate viscosity and build orientation for 4D-printed soft robot components. Through the integration of physical models, the ML uses sparse datasets in a statistical learning framework to predict materials and 3D printing processing parameters to increase 3D printing speed and fidelity [17].
Second, the ML is used in conjunction with the FEM to predict a precise actuation signal for the nonlinear dynamics model of 4D-printed soft robots. Certain elements, such as targeted anisotropy, variable stiffness, and spatially heterogeneous mechanical strengths, can therefore be introduced during 3D printing to cope with environmental uncertainties.
The design of a closed-loop soft robot to achieve a target shape appropriate for a practical application is an inverse nonlinear problem that requires ML algorithms and FEM to handle the variable physical responses of incorporated materials [18]. Although analytical models and static controllers are more reliable and accurate for conventional rigid robots in a known environment, data-driven/ML approaches can be more suitable for closed-loop 4D-printed soft robots because of their high dimensionality, dexterity, material anisotropy and nonlinearity, and uncertain dynamics [5,19–22].
Different control strategies can be employed to enable the soft robot to adapt to a dynamic environment [18,23–25]. Open-loop controllers have been commonly used in high-speed trajectory-tracking tasks with minimum control effort [16,26]. The controller's gain, however, is limited by the stiffness requirements of the system [27]. Closed-loop controllers and embedded soft sensors are therefore essential to handle uncertainties originating from dynamic surroundings and variations in the material properties of soft robots while preserving stiffness requirements and robustness. The mechanisms and materials used in the construction of soft robots are similar; hence, the control can be inspired by a learning strategy that deals with high nonlinearity and agility [16,19,28].
2 | A. Zolfagharian et al. / Materials and Design 188 (2020) 108411

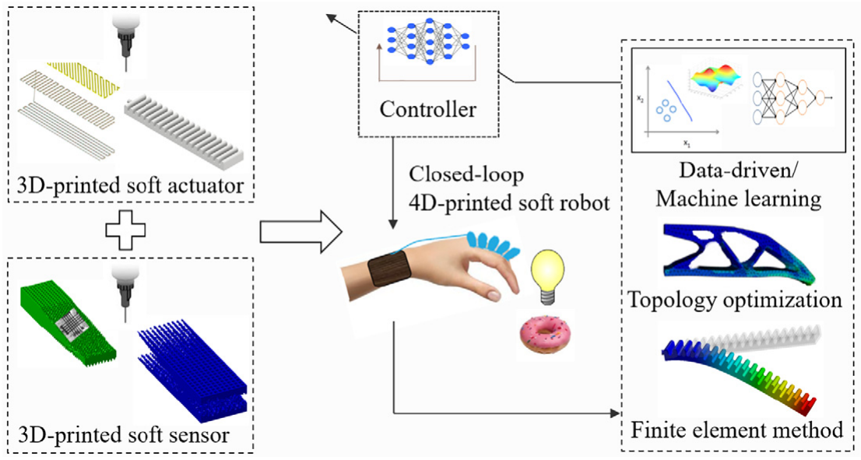
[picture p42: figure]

This review introduces the fabrication and integration of 3D-printed soft sensors and actuators by tailoring ML approaches for the modelling and control of 4D-printed soft robots. Other components, such as 3D-printed soft actuators, batteries, and flexible electronics as peripheral parts of closed-loop 4D-printed soft robots have already been reported in existing publications [4,29–33].
The rapid growth of 3D printing technology has enabled the capability of embedding multilayer electronic circuit boards within the structures of soft robots. Soft conductive materials that have both conductivity and stretchability could be used within insulated interface networks in developing flexible electronics parts of closed-loop 4D-printed soft robots [34]. The 3D printing of stretchable networks made from conductive fillers or ionic electrolytes has allowed the 3D printing of silicon-based electronic circuit components (resistors, capacitors, and antennas) to incorporate embedded systems inside 4D-printed soft robot systems [29]. Moreover, passive filters, including low and highpass filters with varying cut-off frequencies, have been developed by constructing twistable wires and circuit components, such as stretchable and flexible 3D-printed capacitors and resistors [35]. To process sensor outputs and control the actuator, integrated miniature microcontroller units (MCUs) are the other imperative parts of closed-loop 4D-printed soft robots. These MCUs are fabricated in sophisticated chip foundries because they cannot be fabricated by current 3D printers. Three-dimensional printing, however, enables the spatial embedding of MCUs in different layers and orientations with mechanical and electrical design flexibilities as parts of 4D-printed soft robots [35]. In order to closed-loop 4D-printed soft robots exhibit an autonomous behaviour, they require power sources with a high power density and flexible electrodes that could be built through the recent advancement in 3D-printed batteries [29–31,33]. The 3D printing of a stacked-array and self-supporting solid electrolyte [33] or lithium-ion [36] batteries in micrometre-scale using conformal ink makes the foregoing feasible. The rest of this paper is structured as follows. In Section 2, 3D-printed soft sensors are reviewed. In Section 3, the investigation of the integration of 3D-printed soft sensors and actuators is elaborated. In Section 4, the control strategies for closed-loop 4D-printed soft robots are discussed. Finally, in Section 5, the current limitations and future directions of this field of research are presented.
2. 3D-printed sensors

The first components that are required for closing the control loop of 4D-printed autonomous soft robots are 3D-printed embedded sensors. The current advancements in 3D printing technology and functional materials provide an opportunity for the development of 3D-printed soft sensors with customised geometry and functionality to be embedded in soft robots for specific applications. The typical conductive inks used for the fabrication of 3D-printed soft sensors are based on conductive polymers, nanofillers, and liquid metals [37–39]. In this section, the investigation of 3D-printed sensors based on various sensing principles for potential applications in 4D-printed soft robots is elaborated. Thus far, most 3D-printed sensors are developed based on resistive and/or capacitive principles with applications in tactile, mechanical loading, temperature, and humidity measurements.
Each of the several approaches used for the 3D printing of embedded sensors have pros and cons. The 3D-printed sensors in soft robotic applications can be characterised based on the material properties of printing ink and geometrical dimensions to produce a detectable response signal. One of the early techniques is a semi-3D printing approach where conductive parts are embedded into the 3D-printed substrate [40]. Despite its early success because of the abundance of highly conductive materials, this method is disputed because it is not recognised as a full 3D printing method for free-form deposition/extrusion of wiring conductors. As a result, the infusion method in which conductive and nonconductive materials are infused together as printing filaments or dissolved as printing inks is subsequently proposed [41]. Although this method enables the full 3D printing of sensors, difficulties are encountered in achieving the uniform dispersion of conductive particles and voids in the structure, thus leading to the formation of cracks in 3D-printed tracks. Through commercialisation combined with the progress in printable conductive materials, the availability of fused deposition modelling (FDM) and co-extrusion 3D printers has increased. As a result, multi-material 3D printing has become the most preferred printing method although it has low spatial conductivity (Fig. 2(a)) [42,43]. Different 3D printing technologies that are employed for developing sensors as well as their advantages and drawbacks are extensively discussed in earlier papers [2,44]. It has been reported that both geometry and material specifications perform a function in defining the characteristics of 3D-printed embedded sensors with various sensing principles and applications in soft robotics. Here, 3D-printed sensors with specific applications in 3D-printed soft robots (Table 1) are classified; a more detailed information on general sensors in 3D printing can be found in related review papers [2,44–46].

Fig. 1. Diagram of closed-loop 4D-printed soft robot.

A. Zolfagharian et al. / Materials and Design 188 (2020) 108411 | 3

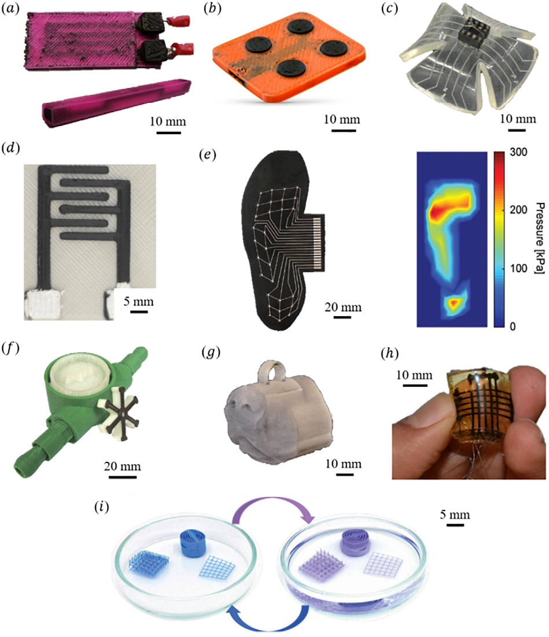
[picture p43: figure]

2.1. 3D-printed strain sensors

Strain sensors can be used in 3D-printed soft robots to measure mechanical deformation. Most 3D-printed strain gauge sensors can be developed based on the piezo-resistive property and geometry changes of printed constructs under mechanical deformations. Three-dimensional printing could be readily used for these sensors by strategically placing printed strands on appropriate locations based on the expected mechanical loadings. A planar series of stretchable strain sensors is successfully 3D-printed into an elastomeric material. This array of 3D-printed soft sensors exhibits a resistance variation in response to cyclic loadings, and the technique is shown to be promising for the 3D printing of planar and 3D geometries of strain gauge sensors in soft programmable structures [47]. Reference [48] reports the fabrication of a 3D-printed tactile piezo-resistive sensor by using FDM and thermoplastic polyurethane (TPU)-based filament (as the flexible non-conductive matrix) and carbon black (CB) (as the conductive filler). In another study, a polylactic acid (PLA)-based filament with a CB filler as a conductive agent is employed to 3D print a strain gauge sensor [49]. An acceptable gauge factor for using the aforementioned sensor as a 3D-printed strain gauge in soft robotic applications is revealed through a tensile test that is performed in combination with four-probe measurements. Carbon fibre-filled silicone rubber is also printed by extrusion 3D printing and tested for resistive sensing to different deformation modes, such as bending, extension, compression, and twisting. The results show that the resistivity hysteresis is reduced by cyclic folding, bending, and twisting loading and unloading [50].
Capacitive-based strain gauge sensors have also been 3D-printed to measure the extensional strain [51,52]. It is shown that the sensitivity of these sensors could be customised by monitoring the 3D printing parameters, such as nozzle size, ink flow rate, layer thickness, and printing speed [52]. Printing inks that contain nanoparticles, graphene, and nanotubes have recently been investigated to enhance the electrical conductivity while maintaining the conformity of 3D-printed sensors in soft robotic applications [53–55]. With the introduction of graphene into the 3D printing of soft sensors, a multi-dimensional flexible sensor with a porous nanostructure is developed. This sensor uses a highly conductive graphene aerogel with gesture manipulation applications [52]. Three-dimensional-printed fibre optic sensors that operate based on changes in the intensity of reflected light caused by the deformation of

Fig. 2. 3D-printed sensors with applications in 4D-printed soft robots. (a) 3D-printed integrated strain sensor (reproduced with permission from Copernicus Publications on behalf of AMA [42]); (b) 3D-printed sEMG electrodes (reproduced with permission from Copernicus Publications on behalf of AMA [42]); (c) 3D-printed piezoelectric sensor in jellyfish soft robot (reproduced with permission from SPIE [67]); (d) 3D-printed e-tongue sensor (reproduced with permission from Frontiers [110]); (e) 3D-printed pressure sensors (reproduced with permission from John Willey and Sons [71]); (f) 3D-printed fluid flow rate sensor (reproduced with permission from IOP Publishing [98]). (g) 3D-printed dog nose for gas detection (reproduced with permission from Nature Publishing Group [109]); (h) 3D-printed flexible tactile sensor (reproduced with permission from Springer [58]); (i) 3D-printed thermochromic and solvatochromic sensors (reproduced with permission from John Wiley and Sons [100]).

4 | A. Zolfagharian et al. / Materials and Design 188 (2020) 108411

the soft robotic arm have been reported. In terms of hysteresis, these sensors eliminate many of the deficiencies of conductive materials that are employed in resistive and capacitive 3D-printed sensors. These fibre optic sensors can be directly 3D-printed for soft robotic applications [56]. Moreover, an entirely 3D-printed mechanoluminescent device is developed from polydimethylsiloxane (PDMS) and metal ion-doped ZnS particles, which emit light upon the compression or stretching of the assembly. This 3D-printed soft sensor can be used as a directional strain sensor [57].

2.2. 3D-printed tactile sensors

Tactile sensors could be integrated into 4D-printed soft robots as artificial skin to sense the texture of materials in the surroundings. Most of the recent 3D-printed tactile sensors are developed by embedding conductive meshes in 3D-printed thermoplastic polymer substrates (Fig. 2 (h)) [58]. The 3D printing of capacitive-based tactile sensors is reported to be more problematic mainly because of the constraints in depositing conducting materials in the form of thin layers. There have been some successful studies, however, on the fabrication of capacitive touch sensors by embedding conductive wires in FDM-printed layers [59,60]. A fully encapsulated capacitive sensor is designed and fabricated by using polyphenyl sulphone as substrate and FDM-printed polycarbonate [61]. Carbon nanotube (CNT)-Ecoflex is also 3D-printed as highly stretchable capacitive sensors with sensing applications, such as tactile recognition [62]. The printed CNT-Ecoflex exhibits promising results that are not possible with traditional counterparts. This is attributed to the enhanced controllability and tenability of stretchable structures by 3D printing. A piezo-resistive tactile sensor is 3D-printed using a composite filament of TPU and polylactic acid–graphene (PLA–G). The repeatability of a sensing function within a broad range of bendinginduced strains is promising [63]. A graphite/PDMS sensor for small soft structures to measure small forces in the range 3.5–7.5 mN is also developed by 3D printing [64]. Stretchable tactile sensors are 3D-printed on a free-form surface using multi-materials [65]. These soft sensors that are capable of measuring various types of tactile forces are printed in series. In another study, hair-like structures with a strand size of 100 μm are 3D-printed on complex geometries for a tactile sensor in soft robotic applications, such as touch location and intensity sensing, to identify different gestures (Fig. 2(j)) [66].

Table 1
Overview of 3D-printed sensors in 4D-printed soft robot applications.
3D-printed sensors | Mechanisms | 3D
printers
Materials | Pros (+) and cons (−) | 4D-printed soft robots
Strain | Capacitive [52] Optical waveguide [56] Resistive [48]

Extrusion
Extrusion
FDM

Silicone
OrmoClear
TPU

+High elongation +Hysteresis free -Coaxial
+Low optical loss
-Fugitive ink
+Force and contact point
-Hysteresis

Grasping
Trajectory tracking
Tactile | Capacitive [66] Piezo-resistive [63]

FDM
SLA

TPU
Cilia

+High sensitivity
-Simple geometries
+High resolution
-Nonlinearity

Gesture differentiations
Holding different shapes
Pressure and stress | Capacitive [68] Optical FBG [78] Piezoelectric [67]

Extrusion
FDM
Inkjet

Ionic gel
ABS
Tango Black

+High sensitivity
-Environmental effects
+Linear response
-High Deviation
+Pressure and shear
–High-stress deviation

Safe manipulation

Displacement | Eddy current [84,85,123] Hall effect [82] Optical waveguide [79]

FDM
FDM
Inkjet

Copper/ABS
Magnetite/ABS
InkOrmo/InkEpo

+Non-contact
+High temperature range
-Low sensitivity
-Environmental effect
+Mass production
-Coupling loss

Path planning

Accelerometer | Capacitive [86] | Inkjet | Polyethylene terephthalate (PET)

+Biodegradability
-Post-assembly

Maneuvering

Magnetic field | Inductance [93] Ultrasonic [91] | Inkjet Inkjet | VisiJet/silver Plaster (zp150)
+Wireless
-Dissolving sacrificial
+Large size
-Limited range

Direction and orientation
Contraction in length and
force
Flow | Inductance [98] Vortex [96] | FDM FDM | Magnetite/polycaprolactone Polyurethane/graphene

+Linear response
-Delamination
+Multi-axis
-Post-assembly

Stiffness adaptation

Temperature and
humidity

Capacitive [102]
Solvato/Thermochromic
[100]

DLW
Extrusion

Nanocrystals
1D coordination polymer (CP1)

+High Spatial resolution
-Coupling loss
+Multi-stimuli
-limited cycles

Stiffness adaptation
Multi-stability
Chemical | Electrochemical [110] Optical waveguide [113]
FDM
SLA

Graphene/PLA
Accura®60

+High precision
-Post-treatment
+Disposable
-Low resolution

Detection/classification

Bio | Bioluminescent [115] Electrochemical [122] Vibratory [121]

FDM
SLA
DLP

Bio agents/PLA/ABS
PEGDA
Bisphenol A ethoxylate
diacrylate

+Smartphone based
-low robustness
+Bio-functionality
-millimetre scale
+Self-standing
+Single step fabrication

Detection/classification

A. Zolfagharian et al. / Materials and Design 188 (2020) 108411 | 5

2.3. 3D-printed pressure and stress sensors

Closed-loop 4D-printed soft robots require feedback information, including pressure and deformation, because of their interactions with the environment. To achieve this goal, several different sensor principles have been developed. In one approach, a gel piezoelectric sensor is 3D-printed and embedded into a jellyfish-like soft robot that utilises certain composite gel materials, including ion gel, ionic liquid, and shape-memory gel. The study demonstrates that ion gel could be used as a suitable material for pressure sensing because of its variable impedance properties at different payloads (Fig. 2(c)) [67]. A capacitive sensor that can measure the shear and normal stresses in an amputee's leg is also 3D-printed [68]. The test results demonstrate that this sensor has a highly linear performance, thus making it suitable for soft robotic applications. A capacitive force sensor is made of a combination of fibre encapsulation and 3D printing of thermoplastic elastomer as a dielectric spacer [69]. The sensor, however, exhibits a certain deficiency in terms of signal delay upon unloading. A similar methodology is utilised for developing a shear capacitive force sensor that provides sensing capabilities for autonomous space mission soft robotic applications [70]. Furthermore, an array of capacitive pressure sensors is fabricated using a CB-doped TPU that is designed in the shape of a foot. This 3D-printed sensor is tested to measure pressure in the absence and presence of loads on the foot. A plantar sensor array that could be integrated into 3D-printed soft wearable robots is also developed (Fig. 2(e)) [71]. Three-dimensional printing can be employed in the fabrication of piezoelectric sensors, but with certain problems. When crystal deformation is introduced during bonding, temperature-induced charges may cause pre-strain to a preceding layer made of a material with a different thermal expansion coefficient, thus leading to inaccurate electrical outputs [72].
Polyvinylidene fluoride (PVDF), which is both processible and piezo-resistive, is investigated as a 3D-printed sensor [73–75]. A simple method for the fabrication of a 3D-printed pressure sensor is demonstrated by utilising commercial PVDF powder and multi-walled carbon nanotubes (MWCNT) [76]. Furthermore, another study on 3D-printed capacitive sensors with a pressure sensing function in soft organs using the PVDF is conducted. The 3D-printed PVDF sensor is successfully used in a prosthetic ear to measure both pressure and temperature [77]. Fibre Bragg grating (FBG) is also used as a pressure sensor by embedding it in a 3D-printed acrylonitrile butadiene styrene substrate [78]. The mechanism is based on the wavelength variations of FBG in response to pressure changes.
2.4. 3D-printed displacement sensors

Three-dimensional-printed displacement sensors are either fibre optic or magnetic field-based. The 3D-printed fibre optic sensor measures the displacement of a moving object based on changes in the intensity of reflected light beams. In these sensors, an inert fibre is usually inserted into the 3D-printed structure [79]. As one of the choices for displacement and vibration measurements in 3D-printed soft robots, fibre optic displacement sensors are lightweight, transparent, and inexpensive [80]. The other applications for these types of sensors include tactile sensors and accelerometers [81]. Three-dimensional-printed magnetic displacement sensors have also been developed to detect the motion of a magnet upon flexure as inspired by the Hall effect principle [82,83]. The 3D-printed displacement sensor based on the Eddycurrent principle has recently attracted interest mainly because of being a non-contact method and having the potential of measuring a wide range of temperatures in harsh uncertain environments [84,85].

2.5. 3D-printed accelerometers

The 3D printing of accelerometers with high conformity and sensitivity is crucial in the implementation of 4D-printed soft robots.

Knowing the acceleration of different segments of soft robots will contribute to the predictability of their dynamics and control when interacting in uncertain environments. In one of the earliest studies on the development of 3D-printed accelerometers, a capacitive accelerometer is fabricated and tested in a suspended structure using a sacrificial printing material and silver paste [86]. An accelerometer is subsequently fabricated by 3D printing and wet metallisation based on the capacitive differential of perpendicular axis accelerations [87]. The highperformance output of this 3D-printed accelerometer makes it an excellent choice for application in 4D-printed soft robots.

2.6. 3D-printed magnetic field sensors

Embedded miniature magnets can be used for the contact-free detection of soft body deformation in 4D-printed soft robots. The hysteresis observed in the stress–strain curves of 3D-printed conductive composite strain sensors is avoided. Custom shape and size magnetic curvature sensors could provide soft robots with proprioceptive feedback for sensing motion and external forces [88,89]. Ferromagnetic photopolymers have been used as appropriate materials for the 3D printing of magnetic field sensors by stereolithography (SLA) [90]. Moreover, the aerosol jet technique is used for the 3D printing of coil winding by nanosilver and copper inks [38]. Frequency-selective electromagnetic soft structures have also been 3D-printed for the electromagnetic control of ultrasonic wave propagation [91].
The use of inductive sensors has attracted interest because of their high reliability function under extreme environmental conditions, such as high temperature and pressure, and underwater operations. These sensors also have other technological features (e.g., higher switching rate) and they offer more flexibility in design with access to a wider range of materials compared with resistive and capacitive 3D-printed sensors [92]. The detection performance of 3D-printed inductance sensors can be characterised based on the geometric parameters and number of turns of a spiral pipe regardless of conductivity changes in the liquid metal [93]. The 3D-printed inductance sensor could incorporate magnetic and ferrofluidic materials into 3D soft robots at room temperature to measure axial, lateral, bending, and dilatational strains [94,95].
2.7. 3D-printed flow sensors

Three-dimensional-printed flow sensors contribute to the development of 4D-printed soft robots, especially pneumatic soft actuators and robots that work in aqueous environments. An entirely 3D-printed whisker sensor is fabricated using TPU and graphene for underwater soft robotic applications to measure vortices [96]. A 3D-printed micro-hair structure is developed for flow sensing [97] and exhibits a reasonable performance in low-velocity air sensing. A flow sensor is also fabricated by a magnetite nanoparticle-loaded thermoplastic composite for measuring water flow rates (Fig. 2(f)) [98]. A 3D-printed microdroplet liquid detector that could be used in self-driven microfluidic applications is developed by employing polyethylene diacrylate and multi-walled carbon nanotube (MWCNT) [99].

2.8. 3D-printed temperature and humidity sensors

Three-dimensional-printed temperature and humidity sensors are essential components for enhancing the environmental awareness of soft robots under various conditions. Functional polymers are the most widely used materials in the 3D printing of soft robots. The physical behaviours of these polymers are highly dependent on the temperature and humidity of the surrounding environment. Using 3D printing, the temperature and humidity data can be acquired in spatial layers of the soft structure using embedded and integrated sensors. A 3D-printed composite copper–thymine sensor with a high level of sensitivity is developed for measuring environmental temperature and

6 | A. Zolfagharian et al. / Materials and Design 188 (2020) 108411

humidity in organic solvents. The sensor mechanism is based on changes in the structure and colour with water loss and temperature variations (Fig. 2(i)) [100]. Conductive inks, including nanosilver particles and graphene [101], have been broadly used via direct laser writing (DLW) for implementing 3D-printed capacitive-based temperature and humidity sensors [102]. A 3D-printed wireless humidity sensor is also developed to detect moisture levels in soil. The mechanism of this sensor is based on resonant frequency shifts in response to the soil moisture level [103]. A PLA resistive-based temperature sensor that could be used in soft robots in food industries is also 3D-printed [104].

2.9. 3D-printed chemical sensors

Three-dimensional-printed chemical sensors can be used in diverse 4D-printed soft robot applications, such as microfluidics and chemical leak detection [105,106]. In soft robots associated with microfluidics working in electrolyte and polyelectrolyte mediums, 3D-printed electrochemical sensors performs a significant function [107]. These sensors are developed based on the double-layer formations on electrodes and subsequent disturbance of space charges with fluid movement. Another advantage of 3D printing in the fabrication of these sensors is its specific calibration customisation based on electrolyte ions and concentrations. There have been some promising reports on 3D-printed graphene-based PLA electrodes using an FDM printer for electrochemical sensing purposes [108]. A 3D-printed artificial dog nose, which could be embedded in an autonomous surveillance soft robot, is developed for gas detection purposes (Fig. 2(g)) [109]. An e-tongue is developed using an FDM 3D printer and transparent graphene-based PLA filaments to detect different materials, such as N, P, K, S, Mg, and Ca (Fig. 2(d)) [110]. A biological tissue-compatible pH sensor made of hydrogel has also been 3D-printed. A 3D-printed soft sensor made from pHsensitive poly(3,4-ethylene dioxythiophene) and hydrophilic polyurethane provides soft robotic applications in wet environments with extreme cyclic deformations, including twisting and bending [111]. A wireless sensor made of a mixture of silver nanowires and cellulose nanofibres is 3D-printed for selectively detecting quantitative ion concentrations [112]. Furthermore, optical fibres are integrated into a microfluidic particle counter by 3D printing. The size of particles is identified based on the light intensity variations through the fibre [113].

2.10. 3D-printed biosensors

Three-dimensional-printed biosensors can perform a significant function in the realisation of miniaturised 4D-printed soft robots to detect and measure biological changes in bio-related applications [1,114]. There have been several successful studies of 3D-printed hydrogel sensors with proven biocompatibility to measure enzymes, toxicity, and drug release as well as to detect cancer [115–118]. Non-invasive 3D-printed electroencephalography (EEG) sensors have been developed to record brain activity and could soon be used in 4D-printed surgical

Table 2
Overview of materials used in 3D-printed actuators with applications in 4D-printed soft robots.
Materials | Stimuli | Pros (+) and cons (−) | References
PDMS/silicones | Pneumatic Fluidic | +Light weight and Inflatable +Biocompatible +High force transmission -Needs external pump/compressor -Difficult controlling of force | [140,154]
TPUs | Pneumatics | +Light weight and Inflatable +Biocompatible -Needs external compressor -Difficult controlling of force
[155,156]
SMPs | Electrical Heat Magnetic Chemical-Reaction Light

+Biodegradable
+Low cost
-Slow response
-Low-medium power density
-Too sensitive to thermal noise

[157–164]

Hydrogels | Moisture Heat pH Magnetic Electrical

+Low operating voltage
+Biocompatible
+Biodegradable
-Slow response
-Low mechanical strength

[1,107,165,166]

Paper/celluloses | Moisture Electrical | +Biodegradable -Slow response

[167,168]

IPMCs | Electrical | +Fast response +High strain +Low operating voltage +Lightweight -Medium power density -Requires electrolyte layer

[129,169]

Dielectric elastomers | Electrical | +High elastic energy density +High longevity -High operating voltage -Low power density -Requires pre-strain in fabrication

[170][171]

Piezoelectrics | Electrical | +Fast response +High longevity -High operating voltage -Not biocompatible -Low strain -Low power density -Large hysteresis

[172,173]

Magnetics | Magnetic | +Remotely control +low energy loss/friction -Brittle and hard to print -Locking mechanism required

[174–176]

A. Zolfagharian et al. / Materials and Design 188 (2020) 108411 | 7

soft robots [58]. Three-dimensional printing can contribute to the development of easy to fabricate and inexpensive dry and waterproofed electrodes that are suitable for EEG sensors [119]. The use of a 3D-printed glucose sensor that could be attached to miniaturised soft robots for biomedical applications in diabetes has been recently demonstrated [120]. A mass-sensitive biosensor based on the vibratory measurement of a microcantilever is developed in one-step 3D printing. A mixture of a photocurable resin and acrylic acid is prepared to 3D print a functionality tunable sensor in a standard immunoassay protocol [121]. A flexible 3D-printed sensor with a surface electromyography capability for soft robot and medical applications is also developed by the FDM of dielectric and conductive TPU (Fig. 2(b)) [43]. Compared with regular AgCl electrodes, the signals of 3D-printed sensors, especially in the lower frequencies, exhibit a significant sensitivity to muscle activity [122].

3. Integrated 3D-printed soft sensors and actuators

The integration of 3D-printed soft sensors and actuators is a key feature in developing 4D-printed soft robots. Further details regarding different 3D printing methods and materials for developing 3D-printed soft actuators and soft robots can be found in previous articles (Table 2)[44,45]. Three-dimensional-printed soft sensors for measuring strain, stress/pressure, touch, and displacement are embedded into soft robot bodies to send sensory feedbacks without compromising the conformity and flexibility of the system when the robots interact with the surrounding environment. Thus far, in the literature, reports of integrated 3D-printed sensors and actuators that create a significant scope and potential for future development and innovative research are limited. The further contemplation of possibilities invokes concepts of 4D-printed soft structures.

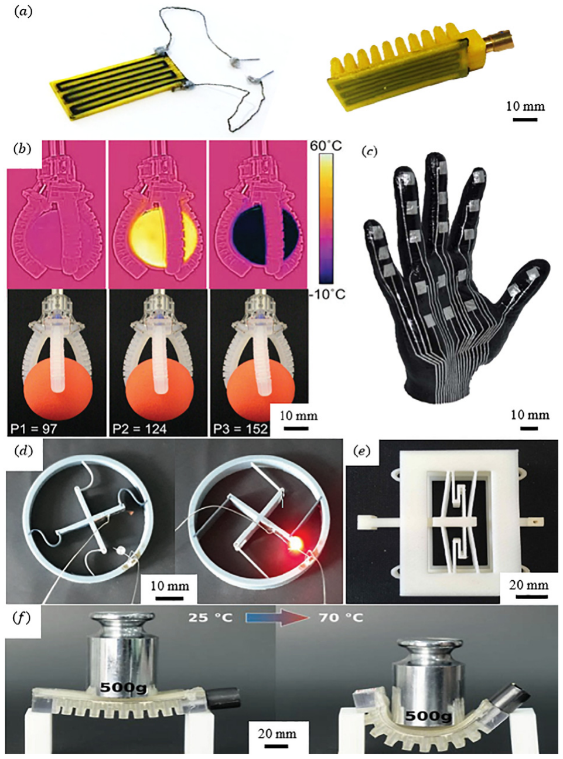
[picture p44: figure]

Fig. 3. Integrated 3D-printed soft sensors and actuators: (a) 3D-printed embedded sensor in pneumatic soft actuator (reproduced with permission from SPIE [126]); (b) 3D-printed soft gripper with printed embedded sensors (reproduced with permission from John Wiley and Sons [9]); (c) 3D-printed tactile sensor on 3D-printed prosthetic hand (reproduced with permission from the American Chemical Society [34]); (d) 4D-printed multistable thermal actuator (reproduced with permission from JohnWiley and Sons [150]); (e) Bistable 3D-printed soft actuator (reproduced with permission from MDPI [148]); (f) 3D-printed variable stiffness soft actuator with an integrated joule heating circuit (reproduced with permission from John Wiley and Sons [151]).

8 | A. Zolfagharian et al. / Materials and Design 188 (2020) 108411

One of the earliest practices in the integration of 3D-printed sensors and actuators in a soft robot is achieved by the 3D printing of a synthetic sensory-motor onto a soft fluidic elastomeric actuator (Fig. 3(b)) [9]. Pneumatic actuation is the response to tactile sensing and kinaesthetic feedback measured by the 3D-printed sensor made of silicone and conductive hydrogel inks. This mechanism can simultaneously measure the external load on the surface of the soft robot and the internal pressure of the soft actuator in 3D-printed prosthetic soft robots [124]. There have been some previous investigations on embedding 3D-printed soft sensors in separately 3D-printed soft robots and actuators for acquiring feedback information. The bending angle of common 3D-printed pneumatic actuators has been predicted and controlled by using sensory feedback data provided by resistive-based flexible sensors [125]. A data-driven regression-based approach is developed to model and control the soft actuator's complex behaviour. The result of this study demonstrates the application of ML in calculating the bending angle of 3D-printed soft robots under different operating conditions by simply using the embedded soft sensor and without any prior knowledge of the soft robot's material properties or geometric configuration (Fig. 3 (a)) [126,127]. An ionic polymer–metal composite (IPMC) sensor, which could be embedded into 3D-printed pneumatic soft actuators, is also a feasible choice [128]. The IPMCs are soft transducers that can be fabricated through 3D printing [129,130] and utilised as either sensors or actuators. A 3D-printed soft robot that has sensing and actuation capabilities is fabricated using a commercial silicone-based elastomer. An IPMC is used as a sensor embedded within the strain-limiting layer, which is a thick layer of material on the pneumatic actuator; the sensor embedded layer resists deformation leading to anisotropic bending. The developed soft robot is suggested for underwater vehicles and requires laminated coating for a long-standing dry application For [131].
More recently, there have been a few reports on the integration of entirely 3D-printed soft sensors and actuators. A sensory paper robot is 3D-printed by a commercial FDM PLA–graphene composite filament as a resistive heating element and actuator. An electric potential is used to locate a finger that moves on the surface of the 3D-printed paper actuator [132]. A double-network thermo-responsive hydrogel is employed to 3D-print a multifunctional artificial skin. The use of 3D printing enables the magnification of the capacitive sensory response via the customisation of the fibre diameter that allows the system to measure body temperature and motion. The strategies employed in the study yield an example of a thermo-responsive, highly sensitive, and mechanically compliant ionic skin that could contribute to the development of closed-loop 4D-printed soft robotic ionic devices based on hydrogels [133].
A smart stent combined with a wireless pressure sensor by using biocompatible and biodegradable polycaprolactone (PCL) and poly (Dlactide) (PDLA) is 3D-printed. Coating the stent with a drug enables real-time blood pressure measurements in the vessel via resonance frequency changes [134].
A proximity measurement skin is 3D-printed using eutectic gallium −indium (EGaIn) liquid metal alloy on a 3D-printed prosthetic hand surface. The hydro-printed circuit over the hand shell utilises electromyography (EMG) and tactile inputs from reciprocal human−machine interactions to control the hand [34](Fig. 3(c)). An autonomous soft inflatable robotic module with embedded microfluidic sensor channels is developed using 3D-printing [135]. When filled with a liquid conductor, the channels function as tactile sensors to determine the locations and measure the magnitudes of external forces. The soft robots situated within the elastomeric skin actively inflates and deflates in response to measured forces.
To improve the autonomous task handling of the robot, deep learning is proposed for accurately localising the contacts [136]. More than one sensor could be 3D-printed to provide more sensory feedback information to 3D-printed soft robots. In another study, a piezo-resistive composite of carbon black-filled thermoplastic polyurethane is 3D-printed by FDM as a pressure and position sensor. The integrated sensors exhibit adequate flexibility to provide the inherent compliance of a 3D-printed pneumatic soft actuator. One advantage gained from this work is the co-printing of all soft sensors and actuators in a single process. The 3D printing of all pressure and position sensors and soft robotic closed-loop control enables the grasping of delicate objects [137]. There have been other recent approaches to endow 3D-printed soft actuators and robots with sensing capabilities using 4D printing instead of integrating sensors [6,138–140]. This paradigm has offered an efficient 3D printing of soft robots with stimuli-responsive materials, such as shape memory polymers, liquid crystalline elastomers, ionic polymers, gels, and hydrogels [1,4,107,141,142]. To utilise such 4D-printed soft robots in practical applications, they are designed in bistable and multi-stable mechanisms that are driven based on passive sensing [143–147]. For example, the transition of a gripper from an open to a closed stable state occurs by applying a minimum excitation force to the system in the right direction (Fig. 3(f)) [125,148]. The strain energy in such soft bistable mechanisms is released upon the contact with the excitation force. The total sensing and actuation time of the sensorless mechanism for grasping an unknown object is reported to be reasonably acceptable compared to sensory feedback. The sensitivity and snap-through energy of the soft gripper could be tuned by controlling the bistable properties for sensor-less dynamic grasping [125]. A shape-reconfigurable structure is also developed by the 3D printing of a bistable mechanism with shape memory strips. This 3D-printed soft mechanism exhibits expansion and contraction in response to surrounding temperature changes. Assembling these mechanisms in series and parallel configurations results in multi-state structures with variable triggers [149]. Rotational multi-stable structures are also 4D-printed by integrating multi-shape memory polymers (SMPs) with a thermal actuation control on the bending angle. By tuning the geometry of SMP beams within the structure, the mechanism could exhibit controlled actuation in response to thermal stimulus without complicated sensor and control systems (Fig. 3(d)) [150].
Another approach that recently attracted attention for sensor-less 4D-printed soft robots is the capacity to be stiffness-tunable, also known as variable stiffness soft actuators via hybrid multi-material 3D printing. Soft robots that are printed by heterogeneous SMPs allow for passive sensing, which adjusts the stiffness of the body in terms of different environmental changes, e.g., temperature. There are several methods that are employed to autonomously adjust material stiffness, including glass transition monitoring, which can be termed as thermal stiffness control, viscosity-based electrical and magnetic field controls, jamming-based pneumatic and fluidic controls, and acoustic-based acoustic field control (Fig. 3(e)) [151–153].
4. Control of 4D-printed soft robots

Closed-loop 4D-printed soft robots can be realised with the integration of 3D-printed sensors and actuators as well as a controller that can be either embedded into the structure or externally employed. The controller incorporates offline learnt control policies based on a data-driven/ML model of a soft robot. It accomplishes the task of the robot through feedback information supplied by 3D-printed soft sensors through interactions with uncertain environments.
Despite substantial progress in the development of 4D-printed soft robots in terms of material aspects, the accurate control of these robots in different scenarios remains a problematic task because conventional static control methods are not viable solutions. Soft robots are typically characterised by non-linear dynamics because of viscoelastic properties, high number of degrees of freedom, and time-varying physical and chemical properties of actuation bodies, and heterogeneous stiffness of materials and their surroundings, thus making their modelling and control difficult [177]. These have motivated researchers to consider data-driven modelling and control, which can be adopted to realise 4D-printed autonomous soft robots [178,179].
A. Zolfagharian et al. / Materials and Design 188 (2020) 108411 | 9

The control methods employed for soft robots thus far can be divided into two major categories: static and dynamic controllers [19]. Static controllers are mainly designed based on constant curvature model [180], beam theory [181], and Cosserat rod theory [182] methods. The progress of these controllers in real-world applications of soft robots, however, is limited because of their high computational cost, and steady-state assumptions [183]. Hybrid compliance/force controllers without force sensors are also developed under the static controller category to handle the coupling effects between the kinematic and static force models of soft robots [184,185]. There have been some unresolved inaccuracies and model deviations that originate from friction, hysteresis, and nonlinear material properties of soft robots. The results do not show significant improvement even with the incorporation of model-free intelligent static controllers, such as Elman neural network [186] and fuzzy logic [187], because of the lack of dynamic coupling effects of soft robots in such controllers. Dynamic controllers, on the other hand, are developed to deal with the multi-dimensional and nonlinear dynamics of soft robots in unstructured and uncertain environments [19]. These controllers require an accurate formulation of the dynamics of soft robots as well as proprioceptive feedback information. In early studies on the implementation of dynamic controllers in soft robots, a conventional hybrid proportional derivative (PD)-computed torque controller [188,189] is developed. Its robustness is low because of model uncertainties compared to later developed sliding mode
[190] and model predictive controllers (MPCs) [23]. Sliding mode controllers, however, are mainly implemented for the bending control of soft robots based on the Euler–Lagrangian lumped dynamic parameters only on a planar actuation [24,191,192]. The MPCs are also reported to be incapable of running at a high control cycle in complex dynamic models [23,26]. Directly learning the closed-loop control policies from real-world platforms is also suggested to solve model uncertainties; however, the approach is time-intensive and highly probable to be trapped in the local optima [5,27]. Simply put, this method is unable to fully account for fast morphological changes in soft robot dynamics [193].
Data-driven/ML model-based control strategies can be effective in terms of time and energy-efficient trajectory tracking of soft robots. A dynamic closed-loop control strategy, however, is more preferable for enabling the accurate and robust response of 4D-printed soft robots to changing environments or external disturbances. Moreover, the integration of 3D-printed sensors into soft robots requires the implementation of a feedback mechanism. The combination of a data-driven/ML model and a dynamic policy learning controller is therefore necessary to exploit the previous knowledge of the system and track the desired trajectory, respectively (Fig. 4)[19,194].
A typical problem with data-driven/ML algorithms, however, is that they are highly domain-specific, that is, with small changes in the domain, the learnt model could become ineffective [193]. To gain control of such systems, large data are necessary for training the control algorithm. Acquiring training samples from real-world soft robots can be difficult, especially for soft robots with multi-dimensional control states and time-variable properties, and exposed to uncertain environmental disturbances [22,195]. To minimise the repetitious exploratory actions for constructing a data-driven/ML model, the FEM can be used in the offline loop of the control learning algorithms to explore various possible scenarios [196,197], such as variable material properties and environments. It should be noted that the reliability of simulations based on FEM results in the learning control of 4D-printed soft robots could be enhanced by the integration of 3D-printed embedded sensors and proprioceptive feedback information [22,195,198,199]. Additive manufacturing-based topology optimisation (TO) is another tool that is undergoing developments and can be employed to assist in the efficient modelling of 4D-printed soft robots in combination with the FEM [200]. Studies on the multi-material TO of 3D-printed soft grippers

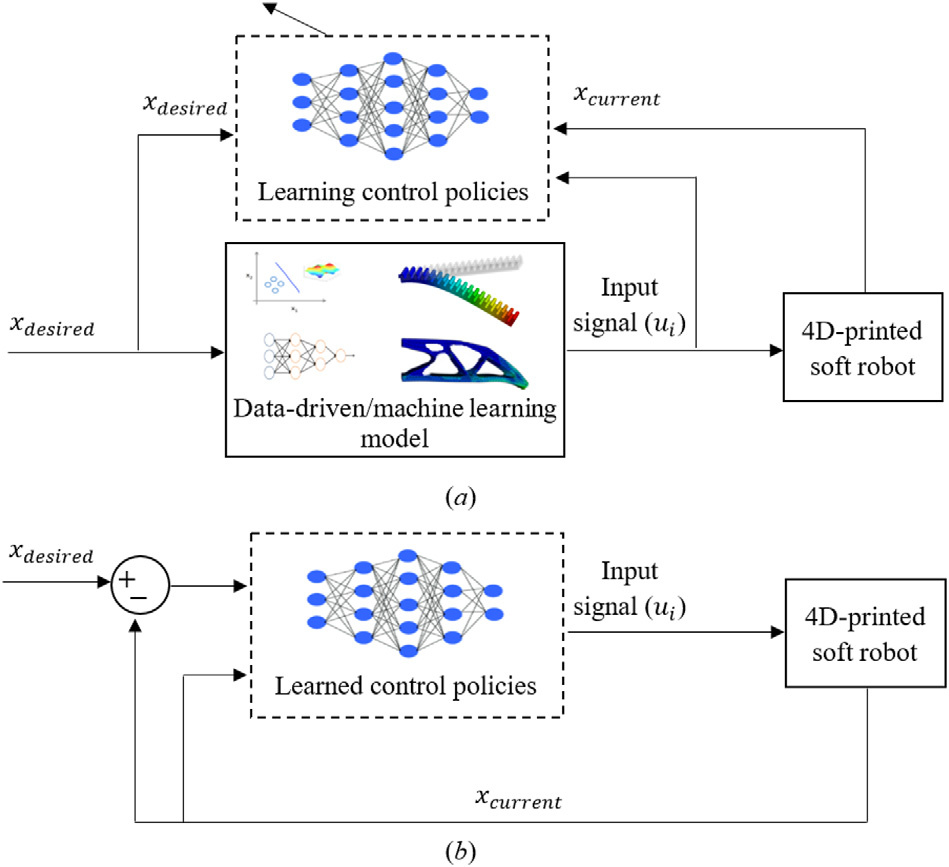
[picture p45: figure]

Fig. 4. Closed-loop control diagrams in 4D-printed soft robots: (a) training of closed-loop control policies based on data-driven/ML model; (b) decision-making and calculation of online commands based on learnt control policy.

10 | A. Zolfagharian et al. / Materials and Design 188 (2020) 108411

have demonstrated performance improvements in terms of maximum bending deflection [201–203]. Topology optimisation can be used for modifying the performance of 4D-printed soft robots in two aspects. The TO can be employed to aid in 3D printing aspects, such as material anisotropy [204], self-support design [205,206], and porous infill design [207]. It can also aid in determining the appropriate configuration of sensors and actuators for optimal sensing and control perspectives [208]. The use of TO method in conjunction with the extended FEM that is employed in 4D-printed soft structures to target the preferred displacement upon stimulus change has shown promising results [209,210][211].
Reinforcement learning is a self-learning control algorithm based on existing data. The algorithm is also capable predicting new possible data by adapting the earlier patterns through various layers of neural network algorithms [213,214]. To achieve closed-loop 4D-printed soft robots, a reinforcement learning control algorithm can be employed to extract the desired information of environment properties from embedded printed sensors and optimise the control algorithm through the interaction with environment [215–219]. Reinforcement learning control in 4D-printed soft robots can be implemented as a model-based learning controller [220,221] in which supervised learning algorithms are used to calculate optimal feedback command based on minimising a cost function [222,223]. On the other hand, there is a model-free approach that does not require learning a model to predict the optimal actions [224]. The control rules of soft robots can also be optimized through model-free approaches, such as Q learning, where a predefined model is not required [5,195,225–227]. Although the latter method has the advantage of predicting the behaviour of soft robots in different environmental scenarios without requiring modelling, the former method can be implemented with the aid of experimental data and FEM. A model-based closed-loop controller for a 4D-printed soft robot can be implemented in three steps:

1- Forward dynamics can be obtained through data-driven/ML methods, recurrent neural network, or convolutional neural network [228].
2- The learnt forward dynamics model is utilised in conjunction with optimisation algorithms to generate the trajectories of soft robots [27,229]. To ensure a satisfactory exploration of the soft robot's end-effector in state space, multiple trajectories can be formulated to achieve the same task. The trajectories provide required samples for attaining optimal control policy and action to drive the soft robot's body to the desired state. The real environment or simulation models aids in the exploration of multiple solutions to the trajectory optimisation problem. This results in the generation of sufficient samples for the unbiased training of the controller.
3- Having obtained all new trajectories, optimal dynamic closed-loop control policies can be directly learnt by the states of the robot through a supervised learning model without an exhaustive search in the state space [27].

The suggested approach for closed-loop 4D-printed soft robots has been found to require approximately 2 h of real-world data to develop a data-driven model-based closed-loop controller [27]. Recently, there have been relatively few studies that utilise variously supervised and unsupervised ML methods to improve the learning procedure of reinforcement learning algorithms and optimally control soft robots to adapt to uncertain environments [230–238]. Further exploration, however, is necessary to implement both methods in diverse environments and determine the most appropriate approach with the least computational burden for closed-loop 4D-printed soft robots.

5. Discussions and future perspectives

The rapid advancements in control learning algorithms and the accessibility of 3D-printed sensors and actuators have provided a platform to develop customised soft structures with high self-driven capabilities in terms of managing delicate tasks in fragile environments. The possibilities and processes to realise closed-loop 4D-printed soft robots, including integrated 3D-printed soft sensors and actuators controlled by feedback control algorithms, are discussed in this paper. It is observed that 3D-printed sensors have evolved to an extent that they could be printed in spatial layers of soft robots for measuring a variety of physical and chemical proprioceptive feedback information. Different types of 3D-printed sensors and their specific applications to closed-loop 4D-printed soft robots are categorised and introduced.
The integration of 3D-printed sensors and actuators reveal that unlike their metallic counterparts, most of the current 3D-printed soft materials that utilise embedded sensors are susceptible to viscoelasticity as well as hysteresis and consequently exhibit nonlinear characteristics. Through the incorporation of ML techniques in the control loop, however, the foregoing deficiencies can be compensated.
To evaluate the novelty and possibility of developing closed-loop 4D-printed soft robots, some recent studies on soft robots that include at least two of the four mainly required components are presented herein, as listed in Table 3. Interestingly, there has not been a closed-loop 4D-printed soft robot that contains all of the four components thus far. There have been some initial studies, however, that incorporate the ML into the closed-loop control strategy of these soft robots without considering the FEM and TO in the design stage [126,127]. There are also certain works related to the application of data-driven/ML closed-loop control of 3D-printed soft actuators that do not consider 3D-printed sensor and FEM analysis [125]. Furthermore, a considerable cohort of sensorless 4D-printed soft robots designed and developed as bistable or multi-stable mechanisms that could benefit from closed-loop controller algorithms for autonomous tasks are identified. Although the FEM and TO have been reported in a few cases [125,148,151–153], these have not been applied to closed-loop 4D-printed soft robots for autonomous operation in a broader dynamic environment. Some investigations related to the integration of 3D-printed sensors and actuators to achieve the closed-loop control of 3D-printed soft robots have been performed [9,34,67,128,132–134]. The use of FEM and closed-loop control, however, has not been considered in any of these studies. A large group of current 3D-printed fluidic and pneumatic soft robots is

Table 3
4D-printed soft robots and compositions.
Type | 3D-printed sensor

3D-printed
actuator

Closed-loop
control

FEM
&
TO

Refs.

Closed-loop 4D-printed
soft robots
✓ | ✓ | ✓ | [126]
✓ | ✓ | ✓ | [127]
4D-printed soft robots | ✓ | ✓ | ✓ | [148]
| ✓ | ✓ | ✓ | [125]
| ✓ | ✓ | ✓ | [151]
| ✓ | ✓ | ✓ | [152]
| ✓ | ✓ | ✓ | [153]
| ✓ | ✓ | ✓ | [150]
Data-driven/machine
learning control of
3D-printed soft
actuators
✓ | ✓ | [125]

Integrated 3D-printed
soft sensors and
actuators
✓ | ✓ | [34]
✓ | ✓ | [128]
✓ | ✓ | [9]
✓ | ✓ | [133]
✓ | ✓ | [134]
✓ | ✓ | [67]
✓ | ✓ | [132]
FEM and topology
optimized 3D-printed
soft actuators
✓ | ✓ | [239]
✓ | ✓ | [155]
✓ | ✓ | [240]
✓ | ✓ | [241]
✓ | ✓ | [156]
✓ | ✓ | [212]
✓ | ✓ | [208]
A. Zolfagharian et al. / Materials and Design 188 (2020) 108411 | 11

analysed and developed using FEM and TO tools (Fig. 5) [155,156,212,239–241]. These robots, however, still lack 3D-printed sensors for developing accurate and closed-loop control to deal with a variety of tasks in unstructured environments.
Generative design capabilities, including the most advanced simulation options, such as stress, heat, vibrations, and computational fluid dynamics which have recently been included in FEM platforms, have made the collection process of training data based on diverse environmental interactions in simulation more prevalent [242]. Several advanced methods have been reported to create a virtual environment in simulations to reflect variable environmental factors [243,244]. More software contributions to the simulation and control of soft robots with various sizes, shapes, and materials should be made to accelerate the real-world application of 4D-printed soft robots [245–247].
Imitating the biomimetic motions of bio-inspired soft actuators can be further investigated, and the incorporation of ML and imitation learning [248] techniques to develop the autonomous control policies of 4D-printed soft robots with less computational and experimental expense can be explored. The development of 4D-printed amphibian soft robots that can work autonomously in different mediums is an interesting future area of research. Such mechanisms require specific materials for the 3D printing of sensors and actuators that can function in diverse mediums, such as liquid and air. Moreover, such 4D-printed amphibian soft robots could be modelled with multiple operating conditions and data-driven/ML models with optimal controllers that can be switched based on different operating scenarios, including temperature or stiffness in different mediums [193]. The 4D-printed paper-based soft robots that include sensing and actuation components [132] is another area that can employ closed-loop control and FEM for more autonomous behaviour.
The incorporation of 3D-printed variable stiffness and multi-stable mechanisms to constrain the soft robot's motion can be further investigated to develop sensorless closed-loop 4D-printed soft robots [249]. Although the use of the reinforcement learning algorithm can overcome difficulties in the closed-loop control of 4D-printed robots in uncertain environments, problems related to practical applications in the high-frequency control bandwidth remain. The incorporation of the intrinsic controller of 4D-printed soft robots using the morphological properties of voxels acting as zero-lag feedback controller during printing can broaden the control bandwidth for faster and more robust manipulations. The integration of 3D-printed sensors and actuators can add further flexibility to the application of sparse sensing and uncertainty quantification by optimising the locations of sensors and actuators that significantly impact controller performance. The incorporation of the morphological computation of materials into the controller account with the optimal placement of sensors and actuators is crucial to closed-loop 4D printing.
The miniaturisation of closed-loop 4D-printed soft robots is highly preferred. Scaling down soft robots from centimetre to millimetre with micrometre-sized features and functionalities for practical applications in the manipulation of microscale delicate objects (e.g., cells) in confined and sensitive areas is in high demand. The fabrication process of closed-loop 4D-printed soft robots is scalable in all the key components of soft robots, such as sensors, actuators, flexible electronics, and controllers. In scaling down these soft robots, however, the strategy relies more on the morphological aspects of stimuli-responsive soft materials to incorporate sensing and actuation in material units rather than conventional components [123,166,250]. In this sense, the miniaturisation of printed sensors and actuators is merely constrained by the resolution of 3D printers and 3D printing techniques (including inkjet, extrusion, or digital light processing (DLP) printers) and solidification ((through melt-processing, solvent-processing, or photopolymerisation). It remains problematic, however, to fabricate soft robots at a millimetre-scale because of the difficulty in making microscale voids and channels [251].
6. Conclusion

In recent years, soft sensors and actuators have increasingly impacted soft robotics and human–machine interfaces. Equipped with the incorporation of machine learning, now is indeed the appropriate time for planning the strategic integration of the foregoing technologies through 3D printing to realise closed-loop 4D-printed soft robots. This review article explores the development of closed-loop 4D-printed soft robots considering the advancements in the 3D printing of soft sensors and actuators and the incorporation of a data-driven/machine learning model and closed-loop controller. Four key components are accordingly selected to define closed-loop 4D-printed soft robots: 3D-

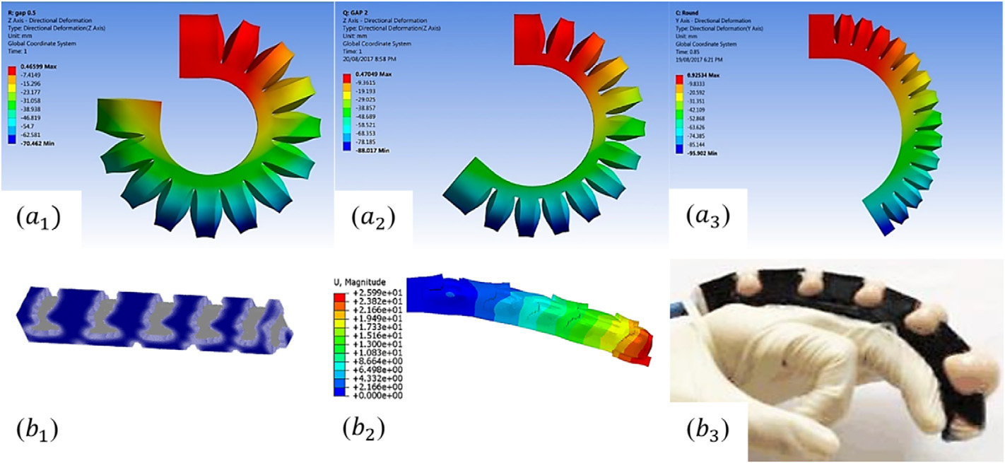
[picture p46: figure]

Fig. 5. FEM and TO applications in data-driven modelling of 4D-printed soft robots. (a1) − (a3) Different modelling results of soft robotic arm with different geometrical parameter changes (reproduced from [156] with permission from MDPI); (b1) − (b3) Topology optimisation of multi-material 3D-printed soft robot (reproduced from [212] National University of Singapore Libraries).

12 | A. Zolfagharian et al. / Materials and Design 188 (2020) 108411

printed sensors, 3D-printed actuators, data-driven models, and dynamic feedback controllers. Different types of 3D-printed sensors and their integration with 3D-printed soft actuators are presented. Various techniques for the modelling and control of 4D-printed soft robots are also reviewed. Moreover, simulation and FEM are suggested to aid in training models. Despite existing problems, 4D-printed soft robots are achievable through the integration of 3D-printed soft sensors and actuators with machine learning algorithms and FEM. Integrated 3D-printed actuators and sensors are feasible but limited by the nature of materials utilised. The future of enhancing closed-loop 4D-printed soft robots accordingly relies on integration of suitable materials, machine learning approaches and control algorithms.

Declaration of competing interest

The authors declare that they have no known competing financial interests or personal relationships that could have appeared to influence the work reported in this paper.

References

[1] A. Zolfagharian, et al., 3D printed hydrogel soft actuators, Region 10 Conference (TENCON), 2016 IEEE, IEEE, 2016. (http://refhub.elsevier.com/S0264-1275(19)30849-4/rf0005)
[2] J.Z. Gul, et al., 3D printing for soft robotics–a review, J Science Technology of advanced MaTerialS 19 (1) (2018) 243–262. (http://refhub.elsevier.com/S0264-1275(19)30849-4/rf0010)
[3] A. Miriyev, K. Stack, H. Lipson, Soft material for soft actuators, J Nature communications 8 (1) (2017) 596. (http://refhub.elsevier.com/S0264-1275(19)30849-4/rf0015)
[4] A. Zolfagharian, et al., Evolution of 3D printed soft actuators, J Sensors Actuators A: Physical 250 (2016) 258–272. (http://refhub.elsevier.com/S0264-1275(19)30849-4/rf0020)
[5] S. Bhagat, et al., Deep reinforcement learning for soft, flexible robots: brief review with impending challenges, J Robotics 8 (1) (2019) 4. (http://refhub.elsevier.com/S0264-1275(19)30849-4/rf0025)
[6] S. Tibbits, 4D printing: multi-material shape change, J Architectural Design 84 (1) (2014) 116–121. (http://refhub.elsevier.com/S0264-1275(19)30849-4/rf0030)
[7] F. Momeni, et al., Plant leaf-mimetic smart wind turbine blades by 4D printing, Renew. Energy 130 (2019) 329–351. (http://refhub.elsevier.com/S0264-1275(19)30849-4/rf0035)
[8] F. Momeni, X. Liu, J. Ni, A review of 4D printing, J Materials design 122 (2017) 42–79. (http://refhub.elsevier.com/S0264-1275(19)30849-4/rf0040)
[9] R.L. Truby, et al., Soft somatosensitive actuators via embedded 3D printing, J Advanced Materials 30 (15) (2018) 1706383. (http://refhub.elsevier.com/S0264-1275(19)30849-4/rf0045)
[10] J. Bishop-Moser, S. Kota, Design and modeling of generalized fiber-reinforced pneumatic soft actuators, J IEEE Transactions on Robotics 31 (3) (2015) 536–545. (http://refhub.elsevier.com/S0264-1275(19)30849-4/rf0050)
[11] H. Banerjee, N. Pusalkar, H. Ren, Single-motor controlled tendon-driven peristaltic soft origami robot, J Journal of Mechanisms Robotics 10 (6) (2018) 064501. (http://refhub.elsevier.com/S0264-1275(19)30849-4/rf0055)
[12] M. Cianchetti, et al., Soft robotics technologies to address shortcomings in today's minimally invasive surgery: the STIFF-FLOP approach, J Soft robotics 1 (2) (2014) 122–131. (http://refhub.elsevier.com/S0264-1275(19)30849-4/rf0060)
[13] O. Atalay, et al., A highly sensitive capacitive-based soft pressure sensor based on a conductive fabric and a microporous dielectric layer, J Advanced Materials Technologies 3 (1) (2018) 1700237. (http://refhub.elsevier.com/S0264-1275(19)30849-4/rf0065)
[14] M.T. Gillespie, et al., Learning nonlinear dynamic models of soft robots for model predictive control with neural networks, 2018 IEEE International Conference on Soft Robotics (RoboSoft), IEEE, 2018. (http://refhub.elsevier.com/S0264-1275(19)30849-4/rf0070)
[15] C.M. Hamel, et al., Machine-learning based design of active composite structures for 4D printing, J Smart Materials Structures 28 (6) (2019) 065005. (http://refhub.elsevier.com/S0264-1275(19)30849-4/rf0075)
[16] T.G. Thuruthel, et al., Stable open loop control of soft robotic manipulators, J IEEE Robotics Automation Letters 3 (2) (2018) 1292–1298. (http://refhub.elsevier.com/S0264-1275(19)30849-4/rf0080)
[17] A. Menon, et al., Optimization of silicone 3D printing with hierarchical machine learning, J 3D Printing Additive Manufacturing 6 (4) (2019), 0088. (http://refhub.elsevier.com/S0264-1275(19)30849-4/rf0085)
[18] A.D. Marchese, R. Tedrake, D. Rus, Dynamics and trajectory optimization for a soft spatial fluidic elastomer manipulator, J The International Journal of Robotics Research 35 (8) (2016) 1000–1019. (http://refhub.elsevier.com/S0264-1275(19)30849-4/rf0090)
[19] T. George Thuruthel, et al., Control strategies for soft robotic manipulators: a survey, J Soft Robotics 5 (2) (2018) 149–163. (http://refhub.elsevier.com/S0264-1275(19)30849-4/rf0095)
[20] S. Levine, et al., End-to-end training of deep visuomotor policies, J The Journal of Machine Learning Research 17 (1) (2016) 1334–1373. (http://refhub.elsevier.com/S0264-1275(19)30849-4/rf0100)
[21] E. Kolve, et al., AI2-THOR: An Interactive 3d Environment for Visual AI, J arXiv preprint arXiv:.05474 2017. (http://refhub.elsevier.com/S0264-1275(19)30849-4/rf0105)
[22] L. Tai, G. Paolo, M. Liu, Virtual-to-real deep reinforcement learning: continuous control of mobile robots for mapless navigation. In intelligent robots and systems (IROS), IEEE/RSJ International Conference On. 2017. IEEE, 2017. (http://refhub.elsevier.com/S0264-1275(19)30849-4/rf0110)
[23] C.M. Best, et al., A new soft robot control method: using model predictive control for a pneumatically actuated humanoid, J IEEE Robotics Automation Magazine 23
(3) (2016) 75–84. (http://refhub.elsevier.com/S0264-1275(19)30849-4/rf0115)
[24] A. Zolfagharian, et al., Bending control of a 3D printed polyelectrolyte soft actuator with uncertain model, J Sensors Actuators A: Physical 288 (2019) 134–143, https://doi.org/10.1016/j.sna.2019.01.027.
[25] A. Zolfagharian, et al., Control-oriented modelling of a 3D-printed soft actuator, J. Mater. 12 (1) (2019) 71. (http://refhub.elsevier.com/S0264-1275(19)30849-4/rf0125)
[26] T.G. Thuruthel, et al., Learning dynamic models for open loop predictive control of soft robotic manipulators, J Bioinspiration biomimetics 12 (6) (2017) 066003. (http://refhub.elsevier.com/S0264-1275(19)30849-4/rf0130)
[27] T.G. Thuruthel, et al., Model-based reinforcement learning for closed-loop dynamic control of soft robotic manipulators, J IEEE Transactions on Robotics 35 (1) (2018) 124–134. (http://refhub.elsevier.com/S0264-1275(19)30849-4/rf0135)
[28] C. Della Santina, et al., Controlling soft robots: balancing feedback and feedforward elements, J IEEE Robotics Automation Magazine 24 (3) (2017) 75–83. (http://refhub.elsevier.com/S0264-1275(19)30849-4/rf0140)
[29] A.H. Espera, et al., 3D-printing and advanced manufacturing for electronics, J Progress in Additive Manufacturing (2019) 1–23. (http://refhub.elsevier.com/S0264-1275(19)30849-4/rf0145)
[30] H. Yang, W.R. Leow, X. Chen, 3D printing of flexible electronic devices, J Small Methods 2 (1) (2018) 1700259. (http://refhub.elsevier.com/S0264-1275(19)30849-4/rf0150)
[31] X. Gao, et al., Toward a remarkable Li-S battery via 3D printing, J Nano energy 56 (2019) 595–603. (http://refhub.elsevier.com/S0264-1275(19)30849-4/rf0155)
[32] D.W. McOwen, et al., 3D-printing electrolytes for solid-state batteries, J Advanced Materials Technologies 30 (18) (2018) 1707132. (http://refhub.elsevier.com/S0264-1275(19)30849-4/rf0160)
[33] D.W. McOwen, et al., 3D-printing electrolytes for solid-state batteries, J Advanced Materials 30 (18) (2018) 1707132. (http://refhub.elsevier.com/S0264-1275(19)30849-4/rf0165)
[34] P.A. Lopes, et al., Hydroprinted electronics: ultrathin stretchable Ag–In–Ga E-skin for bioelectronics and human–machine interaction, J ACS Applied Materials Interfaces 10 (45) (2018) 38760–38768. (http://refhub.elsevier.com/S0264-1275(19)30849-4/rf0170)
[35] H. Ota, et al., Application of 3D printing for smart objects with embedded electronic sensors and systems, J Advanced Materials Technologies 1 (1) (2016) 1600013. (http://refhub.elsevier.com/S0264-1275(19)30849-4/rf0175)
[36] J. Li, et al., A hybrid three-dimensionally structured electrode for lithium-ion batteries via 3D printing, J Materials Design 119 (2017) 417–424. (http://refhub.elsevier.com/S0264-1275(19)30849-4/rf0180)
[37] K. Ahmed, et al., Soft, conductive nanocomposites based on ionic liquids/carbon nanotubes for 3D printing of flexible electronic devices, J Polymer Journal (2019) 1. (http://refhub.elsevier.com/S0264-1275(19)30849-4/rf0185)
[38] B. Polzinger, et al., Inkjet and aerosol jet® printed sensors on 2D and 3D substrates, Proceedings of the AMA Conferences, 2015. (http://refhub.elsevier.com/S0264-1275(19)30849-4/rf0190)
[39] Z. Zhu, et al., 3D printed functional and biological materials on moving freeform surfaces, J Advanced Materials 30 (23) (2018) 1707495. (http://refhub.elsevier.com/S0264-1275(19)30849-4/rf0195)
[40] E. Macdonald, et al., 3D printing for the rapid prototyping of structural electronics, J IEEE access 2 (2014) 234–242. (http://refhub.elsevier.com/S0264-1275(19)30849-4/rf0200)
[41] M. Borghetti, et al., Mechanical behavior of strain sensors based on PEDOT: PSS and silver nanoparticles inks deposited on polymer substrate by inkjet printing, J Sensors Actuators A: Physical 243 (2016) 71–80. (http://refhub.elsevier.com/S0264-1275(19)30849-4/rf0205)
[42] A. Dijkshoorn, et al., Embedded sensing: integrating sensors in 3-D printed structures, J Journal of Sensors Sensor Systems 7 (1) (2018) 169. (http://refhub.elsevier.com/S0264-1275(19)30849-4/rf0210)
[43] G. Wolterink, et al., 3D-printing soft sEMG sensing structures, SENSORS, 2017 IEEE, IEEE, 2017. (http://refhub.elsevier.com/S0264-1275(19)30849-4/rf0215)
[44] Y. Ni, et al., A review of 3D-printed sensors, J Applied Spectroscopy Reviews 52 (7) (2017) 623–652. (http://refhub.elsevier.com/S0264-1275(19)30849-4/rf0220)
[45] Y. Xu, et al., The boom in 3D-printed sensor technology, J Sensors 17 (5) (2017) 1166. (http://refhub.elsevier.com/S0264-1275(19)30849-4/rf0225)
[46] N. Lu, D.-H. Kim, Flexible and stretchable electronics paving the way for soft robotics, J Soft Robotics 1 (1) (2014) 53–62. (http://refhub.elsevier.com/S0264-1275(19)30849-4/rf0230)
[47] J.T. Muth, et al., Embedded 3D printing of strain sensors within highly stretchable elastomers, J Advanced Materials 26 (36) (2014) 6307–6312. (http://refhub.elsevier.com/S0264-1275(19)30849-4/rf0235)
[48] B. Eijking, R. Sanders, G. Krijnen, Development of whisker inspired 3D multimaterial printed flexible tactile sensors, SENSORS, 2017 IEEE, 2017 , (IEEE). (http://refhub.elsevier.com/S0264-1275(19)30849-4/rf0240)
[49] D. Fitz-Gerald, J. Boothe, Manufacturing and Characterization of Poly (Lactic Acid)/ Carbon Black Conductive Composites for FDM Feedstock: An Exploratory Study, 2016. (http://refhub.elsevier.com/S0264-1275(19)30849-4/rf0245)
[50] P. Huang, Z. Xia, S. Cui, 3D printing of carbon fiber-filled conductive silicon rubber, J Materials Design 142 (2018) 11–21. (http://refhub.elsevier.com/S0264-1275(19)30849-4/rf0250)
[51] J.O. Hardin, et al., All-printed multilayer high voltage capacitors with integrated processing feedback, J Additive Manufacturing 27 (2019) 327–333. (http://refhub.elsevier.com/S0264-1275(19)30849-4/rf0255)
[52] A. Frutiger, et al., Capacitive soft strain sensors via multicore–shell fiber printing, J Advanced Materials 27 (15) (2015) 2440–2446. (http://refhub.elsevier.com/S0264-1275(19)30849-4/rf0260)
[53] Y.J. Fan, et al., Stretchable porous carbon nanotube-elastomer hybrid nanocomposite for harvesting mechanical energy, J Advanced Materials 29 (2) (2017) 1603115. (http://refhub.elsevier.com/S0264-1275(19)30849-4/rf0265)
[54] Q. Chen, et al., 3D printing biocompatible polyurethane/poly (lactic acid)/graphene oxide nanocomposites: anisotropic properties, J ACS applied materials interfaces 9
(4) (2017) 4015–4023. (http://refhub.elsevier.com/S0264-1275(19)30849-4/rf0270)
[55] J.F. Christ, et al., 3D printed highly elastic strain sensors of multiwalled carbon nanotube/thermoplastic polyurethane nanocomposites, J Materials Design 131 (2017) 394–401. (http://refhub.elsevier.com/S0264-1275(19)30849-4/rf0275)
[56] D.J. Lorang, et al., Photocurable liquid core–fugitive shell printing of optical waveguides, J Advanced Materials 23 (43) (2011) 5055–5058. (http://refhub.elsevier.com/S0264-1275(19)30849-4/rf0280)
[57] D.K. Patel, et al., Fully 2D and 3D printed anisotropic mechanoluminescent objects and their application for energy harvesting in the dark, J Materials Horizons 5 (4) (2018) 708–714. (http://refhub.elsevier.com/S0264-1275(19)30849-4/rf0285)
[58] M. Vatani, et al., Combined 3D printing technologies and material for fabrication of tactile sensors, J International Journal of Precision Engineering Manufacturing Chemist 16 (7) (2015) 1375–1383. (http://refhub.elsevier.com/S0264-1275(19)30849-4/rf0290)
[59] C. Shemelya, et al., Encapsulated copper wire and copper mesh capacitive sensing for 3-D printing applications, J IEEE Sensors Journal 15 (2) (2015) 1280–1286. (http://refhub.elsevier.com/S0264-1275(19)30849-4/rf0295)
[60] J. Delamare, R. Sanders, G. Krijnen, 3D printed biomimetic whisker-based sensor with co-planar capacitive sensing, Sensors, 2016 IEEE, IEEE, 2016. (http://refhub.elsevier.com/S0264-1275(19)30849-4/rf0300)
[61] C. Shemelya, et al., 3D printed capacitive sensors, SENSORS, 2013 IEEE, IEEE, 2013. (http://refhub.elsevier.com/S0264-1275(19)30849-4/rf0305)
[62] K. Li, et al., 3D printed stretchable capacitive sensors for highly sensitive tactile and electrochemical sensing, J Nanotechnology 29 (18) (2018) 185501. (http://refhub.elsevier.com/S0264-1275(19)30849-4/rf0310)
[63] S. Mousavi, et al., An Ultrasensitive 3D Printed Tactile Sensor for Soft Robotics, J arXiv preprint arXiv:.09236 2018. (http://refhub.elsevier.com/S0264-1275(19)30849-4/rf0315)
[64] A. Nag, et al., 3D printed mould-based graphite/PDMS sensor for low-force applications, J Sensors Actuators A: Physical 280 (2018) 525–534. (http://refhub.elsevier.com/S0264-1275(19)30849-4/rf0320)
A. Zolfagharian et al. / Materials and Design 188 (2020) 108411 | 13

[65] S.Z. Guo, et al., 3D printed stretchable tactile sensors, J Advanced Materials 29 (27) (2017) 1701218. (http://refhub.elsevier.com/S0264-1275(19)30849-4/rf0325)
[66] J. Ou, et al., Cilllia: 3D printed micro-pillar structures for surface texture, actuation and sensing, Proceedings of the 2016 CHI Conference on Human Factors in Computing Systems, ACM, 2016. (http://refhub.elsevier.com/S0264-1275(19)30849-4/rf0330)
[67] K. Yoshida, et al., 3D printing for gel robotics, Nano-, Bio-, Info-Tech Sensors, and 3D Systems II, International Society for Optics and Photonics, 2018. (http://refhub.elsevier.com/S0264-1275(19)30849-4/rf0335)
[68] P. Laszczak, et al., Development and validation of a 3D-printed interfacial stress sensor for prosthetic applications, J Medical engineering physics 37 (1) (2015) 132–137. (http://refhub.elsevier.com/S0264-1275(19)30849-4/rf0340)
[69] M. Saari, et al., Fabrication and analysis of a composite 3D printed capacitive force sensor, J 3D Printing Additive Manufacturing 3 (3) (2016) 136–141. (http://refhub.elsevier.com/S0264-1275(19)30849-4/rf0345)
[70] C. Shemelya, et al., Multi-functional 3D printed and embedded sensors for satellite qualification structures, 2015 IEEE SENSORS, IEEE, 2015. (http://refhub.elsevier.com/S0264-1275(19)30849-4/rf0350)
[71] A.D. Valentine, et al., Hybrid 3D printing of soft electronics, J advanced Materials 29
(40) (2017) 1703817. (http://refhub.elsevier.com/S0264-1275(19)30849-4/rf0355)
[72] P.P. Regtien, E. Dertien, Sensors for Mechatronics, Elsevier, 2018. (http://refhub.elsevier.com/S0264-1275(19)30849-4/rf0360)
[73] S.N.K. Rajala, M. Mettänen, S. Tuukkanen, Structural and electrical characterization of solution-processed electrodes for piezoelectric polymer film sensors, J IEEE Sensors Journal 16 (6) (2015) 1692–1699. (http://refhub.elsevier.com/S0264-1275(19)30849-4/rf0365)
[74] M.B. Kirkpatrick, et al., Characterization of 3D printed piezoelectric sensors: determiniation of d 33 piezoelectric coefficient for 3D printed polyvinylidene fluoride sensors, SENSORS, 2016 IEEE, IEEE, 2016. (http://refhub.elsevier.com/S0264-1275(19)30849-4/rf0370)
[75] W. Liu, C. Yan, Direct printing of stretchable elastomers for highly sensitive capillary pressure sensors, J Sensors 18 (4) (2018) 1001. (http://refhub.elsevier.com/S0264-1275(19)30849-4/rf0375)
[76] T.-L.B. Tseng, A. Akundi, H. Kim, 4-D printing of pressure sensors and energy harvesting devices for engineering education, 2018 ASEE Annual Conference & Exposition, 2018. (http://refhub.elsevier.com/S0264-1275(19)30849-4/rf0380)
[77] E. Suaste-Gómez, et al., Developing an ear prosthesis fabricated in polyvinylidene fluoride by a 3D printer with sensory intrinsic properties of pressure and temperature, J Sensors 16 (3) (2016) 332. (http://refhub.elsevier.com/S0264-1275(19)30849-4/rf0385)
[78] Y.-K. Lin, et al., Using three-dimensional printing technology to produce a novel optical fiber bragg grating pressure sensor, J Sensors Materials and Corrosion 28
(5) (2016) 389–394. (http://refhub.elsevier.com/S0264-1275(19)30849-4/rf0390)
[79] T. Wolfer, et al., Printing and preparation of integrated optical waveguides for optronic sensor networks, J Mechatronics 34 (2016) 119–127. (http://refhub.elsevier.com/S0264-1275(19)30849-4/rf0395)
[80] B. Igrec, et al., Fiber optic vibration sensor for high-power electric machines realized using 3D printing technology, Photonic Instrumentation Engineering III, International Society for Optics and Photonics, 2016. (http://refhub.elsevier.com/S0264-1275(19)30849-4/rf0400)
[81] K. Willis, et al., Printed optics: 3D printing of embedded optical elements for interactive devices, Proceedings of the 25th Annual ACM Symposium on User Interface Software and Technology, ACM, 2012. (http://refhub.elsevier.com/S0264-1275(19)30849-4/rf0405)
[82] J. van Tiem, et al., 3D printed bio-inspired angular acceleration sensor, Sensors, 2015 IEEE, 2015 , (IEEE). (http://refhub.elsevier.com/S0264-1275(19)30849-4/rf0410)
[83] M. Bodnicki, J. Grzybowski, Miniature transducer of linear displacement based on miniature Hall Effect sensors, Progress in Automation, Robotics and Measuring Techniques, Springer 2015, pp. 21–26. (http://refhub.elsevier.com/S0264-1275(19)30849-4/rf0415)
[84] B. Li, et al., Rapid prototyping eddy current sensors using 3D printing, J Rapid Prototyping Journal 24 (1) (2018) 106–113. (http://refhub.elsevier.com/S0264-1275(19)30849-4/rf0420)
[85] N. Jeranče, N. Bednar, G. Stojanović, An ink-jet printed eddy current position sensor, J Sensors 13 (4) (2013) 5205–5219. (http://refhub.elsevier.com/S0264-1275(19)30849-4/rf0425)
[86] A. Rivadeneyra, et al., Improved manufacturing process for printed cantilevers by using water removable sacrificial substrate, J Sensors Actuators A: Physical 235 (2015) 171–181. (http://refhub.elsevier.com/S0264-1275(19)30849-4/rf0430)
[87] V. Zega, et al., The first 3-D-printed z-axis accelerometers with differential capacitive sensing, J IEEE Sensors Journal 18 (1) (2018) 53–60. (http://refhub.elsevier.com/S0264-1275(19)30849-4/rf0435)
[88] S. Ozel, et al., A composite soft bending actuation module with integrated curvature sensing, 2016 IEEE International Conference on Robotics and Automation (ICRA), IEEE, 2016. (http://refhub.elsevier.com/S0264-1275(19)30849-4/rf0440)
[89] P. Polygerinos, et al., Soft robotics: review of fluid-driven intrinsically soft devices; manufacturing, sensing, control, and applications in human-robot interaction, J Advanced Engineering Materials 19 (12) (2017) 1700016. (http://refhub.elsevier.com/S0264-1275(19)30849-4/rf0445)
[90] C. Credi, et al., 3D printing of cantilever-type microstructures by stereolithography of ferromagnetic photopolymers, J ACS applied materials interfaces 8 (39) (2016) 26332–26342. (http://refhub.elsevier.com/S0264-1275(19)30849-4/rf0450)
[91] B. Sanz-Izquierdo, E.A. Parker, 3-D printing of elements in frequency selective arrays, J IEEE Transactions on Antennas Propagation 62 (12) (2014) 6060–6066. (http://refhub.elsevier.com/S0264-1275(19)30849-4/rf0455)
[92] Y.R. Jeong, et al., A skin-attachable, stretchable integrated system based on liquid GaInSn for wireless human motion monitoring with multi-site sensing capabilities, J NPG Asia Materials 9 (10) (2017) e443. (http://refhub.elsevier.com/S0264-1275(19)30849-4/rf0460)
[93] S.-Y. Wu, et al., RF wireless LC tank sensors fabricated by 3D additive manufacturing, 2015 Transducers-2015 18th International Conference on Solid-State Sensors, Actuators and Microsystems (TRANSDUCERS), IEEE, 2015. (http://refhub.elsevier.com/S0264-1275(19)30849-4/rf0465)
[94] Y. He, et al., Three-dimensional coprinting of liquid metals for directly fabricating stretchable electronics, J 3D Printing Additive Manufacturing 5 (3) (2018) 195–203. (http://refhub.elsevier.com/S0264-1275(19)30849-4/rf0470)
[95] N. Lazarus, S.S. Bedair, G.L. Smith, Creating 3D printed magnetic devices with ferrofluids and liquid metals, J Additive Manufacturing 26 (2019) 15–21. (http://refhub.elsevier.com/S0264-1275(19)30849-4/rf0475)
[96] J.Z. Gul, K.Y. Su, K.H. Choi, Fully 3D printed multi-material soft bio-inspired whisker sensor for underwater-induced vortex detection, J Soft robotics 5 (2) (2018) 122–132. (http://refhub.elsevier.com/S0264-1275(19)30849-4/rf0480)
[97] H. Devaraj, et al., Low velocity digital air flow sensor from 3D printed PEDOT: PSS micro-hair structures, 2015 Transducers-2015 18th International Conference on Solid-State Sensors, Actuators and Microsystems (TRANSDUCERS), IEEE, 2015. (http://refhub.elsevier.com/S0264-1275(19)30849-4/rf0485)
[98] S. Leigh, et al., Using a magnetite/thermoplastic composite in 3D printing of direct replacements for commercially available flow sensors, J Smart Materials Structures 23 (9) (2014) 095039. (http://refhub.elsevier.com/S0264-1275(19)30849-4/rf0490)
[99] X. Li, et al., 3D printing of flexible liquid sensor based on swelling behavior of hydrogel with carbon nanotubes, J Advanced Materials Technologies (2018) 1800476. (http://refhub.elsevier.com/S0264-1275(19)30849-4/rf0495)
[100] N. Maldonado, et al., 3D printing of a thermo-and Solvatochromic composite material based on a cu (II)–thymine coordination polymer with moisture sensing capabilities, J Advanced Functional Materials (2019) 1808424. (http://refhub.elsevier.com/S0264-1275(19)30849-4/rf0500)
[101] S. Ali, et al., All-printed humidity sensor based on graphene/methyl-red composite with high sensitivity, J Carbon 105 (2016) 23–32. (http://refhub.elsevier.com/S0264-1275(19)30849-4/rf0505)
[102] A. Wickberg, et al., Three-dimensional micro-printing of temperature sensors based on up-conversion luminescence, J Applied Physics Letters 106 (13) (2015) 133103. (http://refhub.elsevier.com/S0264-1275(19)30849-4/rf0510)
[103] M.F. Farooqui, A.A. Kishk, Low-cost 3D-printed wireless soil moisture sensor, 2018 IEEE Sensors, IEEE, 2018. (http://refhub.elsevier.com/S0264-1275(19)30849-4/rf0515)
[104] S.L. Marasso, et al., PLA conductive filament for 3D printed smart sensing applications, J Rapid Prototyping Journal 24 (4) (2018) 739–743. (http://refhub.elsevier.com/S0264-1275(19)30849-4/rf0520)
[105] J.F. Rusling, Developing microfluidic sensing devices using 3D printing, J ACS Sensors 3 (3) (2018) 522–526. (http://refhub.elsevier.com/S0264-1275(19)30849-4/rf0525)
[106] Y. Hong, et al., 3D printed microfluidic device with microporous Mn2O3-modified screen printed electrode for real-time determination of heavy metal ions, J ACS applied materials interfaces 8 (48) (2016) 32940–32947. (http://refhub.elsevier.com/S0264-1275(19)30849-4/rf0530)
[107] A. Zolfagharian, et al., Polyelectrolyte soft actuators: 3D printed chitosan and cast gelatin, J 3D Printing Additive Manufacturing 5 (2) (2018) 138–150. (http://refhub.elsevier.com/S0264-1275(19)30849-4/rf0535)
[108] C.L. Manzanares Palenzuela, et al., 3D-printed graphene/polylactic acid electrodes promise high sensitivity in electroanalysis, J Analytical chemistry 90 (9) (2018) 5753–5757. (http://refhub.elsevier.com/S0264-1275(19)30849-4/rf0540)
[109] M.E. Staymates, et al., Biomimetic sniffing improves the detection performance of a 3D printed nose of a dog and a commercial trace vapor detector, J Scientific reports 6 (2016) 36876. (http://refhub.elsevier.com/S0264-1275(19)30849-4/rf0545)
[110] G. Gaál, et al., 3D printed e-tongue, J Frontiers in chemistry 6 (2018) 151. (http://refhub.elsevier.com/S0264-1275(19)30849-4/rf0550)
[111] S. Naficy, et al., Printed, flexible pH sensor hydrogels for wet environments, J Advanced Materials Technologies 3 (11) (2018) 1800137. (http://refhub.elsevier.com/S0264-1275(19)30849-4/rf0555)
[112] T. Kim, et al., 3D printed disposable wireless ion sensors with biocompatible cellulose composites, J Advanced Electronic Materials (2018) 1800778. (http://refhub.elsevier.com/S0264-1275(19)30849-4/rf0560)
[113] S. Hampson, et al., 3D printed microfluidic device with integrated optical sensing for particle analysis, J Sensors Actuators B: Chemical 256 (2018) 1030–1037. (http://refhub.elsevier.com/S0264-1275(19)30849-4/rf0565)
[114] F. Güder, et al., Paper-based electrical respiration sensor, J Angewandte Chemie International Edition 55 (19) (2016) 5727–5732. (http://refhub.elsevier.com/S0264-1275(19)30849-4/rf0570)
[115] E. Michelini, et al., Smartphone-based multicolor bioluminescent 3D spheroid biosensors for monitoring inflammatory activity, J Biosensors Bioelectronics 123 (2019) 269–277. (http://refhub.elsevier.com/S0264-1275(19)30849-4/rf0575)
[116] C.l.A. Mandon, L.J. Blum, C.A. Marquette, Adding biomolecular recognition capability to 3D printed objects, J Analytical chemistry 88 (21) (2016) 10767–10772. (http://refhub.elsevier.com/S0264-1275(19)30849-4/rf0580)
[117] J.U. Lind, et al., Instrumented cardiac microphysiological devices via multimaterial three-dimensional printing, J Nature materials 16 (3) (2017) 303. (http://refhub.elsevier.com/S0264-1275(19)30849-4/rf0585)
[118] G. Scordo, et al., A reagent-free paper-based sensor embedded in a 3D printing device for cholinesterase activity measurement in serum, J Sensors Actuators B: Chemical 258 (2018) 1015–1021. (http://refhub.elsevier.com/S0264-1275(19)30849-4/rf0590)
[119] S. Krachunov, A. Casson, 3D printed dry EEG electrodes, J Sensors 16 (10) (2016) 1635. (http://refhub.elsevier.com/S0264-1275(19)30849-4/rf0595)
[120] A. Adams, A. Malkoc, J.T. La Belle, The development of a glucose dehydrogenase 3D-printed glucose sensor: a proof-of-concept study, J Journal of Diabetes Science Technology and Culture 12 (1) (2018) 176–182. (http://refhub.elsevier.com/S0264-1275(19)30849-4/rf0600)
[121] S. Stassi, et al., Polymeric 3D printed functional microcantilevers for biosensing applications, J ACS applied materials interfaces 9 (22) (2017) 19193–19201. (http://refhub.elsevier.com/S0264-1275(19)30849-4/rf0605)
[122] R. Raman, C. Cvetkovic, R. Bashir, A modular approach to the design, fabrication, and characterization of muscle-powered biological machines, J nature protocols 12 (3) (2017) 519. (http://refhub.elsevier.com/S0264-1275(19)30849-4/rf0610)
[123] T. Wallin, J. Pikul, R. Shepherd, 3D printing of soft robotic systems, J Nature Reviews Materials 3 (6) (2018) 84. (http://refhub.elsevier.com/S0264-1275(19)30849-4/rf0615)
[124] S.S. Robinson, et al., Integrated soft sensors and elastomeric actuators for tactile machines with kinesthetic sense, J Extreme Mechanics Letters 5 (2015) 47–53. (http://refhub.elsevier.com/S0264-1275(19)30849-4/rf0620)
[125] T.G. Thuruthel, et al., A Bistable Soft Gripper With Mechanically Embedded Sensing and Actuation for Fast Closed-Loop Grasping, J arXiv preprint arXiv:.04896 2019. (http://refhub.elsevier.com/S0264-1275(19)30849-4/rf0625)
[126] K. Elgeneidy, et al., Directly printable flexible strain sensors for bending and contact feedback of soft actuators, J Frontiers in Robotics AI Communications 5 (2018) 2. (http://refhub.elsevier.com/S0264-1275(19)30849-4/rf0630)
[127] K. Elgeneidy, N. Lohse, M. Jackson, Bending angle prediction and control of soft pneumatic actuators with embedded flex sensors–a data-driven approach, J Mechatronics 50 (2018) 234–247. (http://refhub.elsevier.com/S0264-1275(19)30849-4/rf0635)
[128] J. Neubauer, T. Stalbaum, K.J. Kim, IPMC embedded in a pneumatic soft robotic actuator: Preliminary experiments in actuation and SensingBehaviors, 2018 15th International Conference on Ubiquitous Robots (UR), 2018 , (IEEE). (http://refhub.elsevier.com/S0264-1275(19)30849-4/rf0640)
[129] J.D. Carrico, K.K. Leang, Fused filament 3D printing of ionic polymer-metal composites for soft robotics, Electroactive Polymer Actuators and Devices (EAPAD) 2017, International Society for Optics and Photonics, , 2017. (http://refhub.elsevier.com/S0264-1275(19)30849-4/rf0645)
[130] J.D. Carrico, et al., Fused filament 3D printing of ionic polymer-metal composites (IPMCs), J Smart Materials Structures 24 (12) (2015) 125021. (http://refhub.elsevier.com/S0264-1275(19)30849-4/rf0650)
[131] A. Rost, S. Schädle, The sls-generated soft robotic hand-an integrated approach using additive manufacturing and reinforcement learning, 2013 12th International Conference on Machine Learning and Applications, IEEE, 2013. (http://refhub.elsevier.com/S0264-1275(19)30849-4/rf0655)
[132] G. Wang, et al., Printed paper actuator: A low-cost reversible actuation and sensing method for shape changing interfaces, Proceedings of the 2018 CHI Conference on Human Factors in Computing Systems, ACM, 2018. (http://refhub.elsevier.com/S0264-1275(19)30849-4/rf0660)
[133] Z. Lei, Q. Wang, P. Wu, A multifunctional skin-like sensor based on a 3D printed thermo-responsive hydrogel, J Materials Horizons 4 (4) (2017) 694–700. (http://refhub.elsevier.com/S0264-1275(19)30849-4/rf0665)
14 | A. Zolfagharian et al. / Materials and Design 188 (2020) 108411

[134] J. Park, et al., Biodegradable polymer material based smart stent: wireless pressure sensor and 3D printed stent, J Microelectronic Engineering 206 (2019) 1–5. (http://refhub.elsevier.com/S0264-1275(19)30849-4/rf0670)
[135] T. Kim, S.J. Yoon, Y.-L. Park, Soft inflatable sensing modules for safe and interactive robots, J IEEE Robotics Automation Letters 3 (4) (2018) 3216–3223. (http://refhub.elsevier.com/S0264-1275(19)30849-4/rf0675)
[136] S. Han, et al., Use of deep learning for characterization of microfluidic soft sensors, J IEEE Robotics Automation Letters 3 (2) (2018) 873–880. (http://refhub.elsevier.com/S0264-1275(19)30849-4/rf0680)
[137] Y. Yang, Y. Chen, Innovative design of embedded pressure and position sensors for soft actuators, J IEEE Robotics Automation Letters 3 (2) (2018) 656–663. (http://refhub.elsevier.com/S0264-1275(19)30849-4/rf0685)
[138] J. Choi, et al., 4D printing technology: a review, J 3D Printing Additive Manufacturing 2 (4) (2015) 159–167. (http://refhub.elsevier.com/S0264-1275(19)30849-4/rf0690)
[139] C. De Marco, S. Pané, B.J. Nelson, 4D printing and robotics, J Sci. Robot. 3 (2018) eaau0449. (http://refhub.elsevier.com/S0264-1275(19)30849-4/rf0695)
[140] M. López-Valdeolivas, et al., 4D printed actuators with soft-robotic functions, J Macromolecular rapid communications 39 (5) (2018) 1700710. (http://refhub.elsevier.com/S0264-1275(19)30849-4/rf0700)
[141] M.O. Saed, et al., Molecularly-engineered, 4D-printed liquid crystal elastomer actuators, J Advanced Functional Materials (2018) 1806412. (http://refhub.elsevier.com/S0264-1275(19)30849-4/rf0705)
[142] P. Rastogi, B. Kandasubramanian, Breakthrough in the printing tactics for stimuli-responsive materials: 4D printing, J Chemical Engineering Journal 366 (2019) 264–304. (http://refhub.elsevier.com/S0264-1275(19)30849-4/rf0710)
[143] A.H. Sakhaei, et al., Design and investigation of a multi-material compliant ratchetlike mechanism, J Mechanism Machine Theory 121 (2018) 184–197. (http://refhub.elsevier.com/S0264-1275(19)30849-4/rf0715)
[144] P. Rothemund, et al., A soft, bistable valve for autonomous control of soft actuators, J Sci Robot 3 (16) (2018) 7986. (http://refhub.elsevier.com/S0264-1275(19)30849-4/rf0720)
[145] T. Chen, et al., Harnessing Bistability for Directional Propulsion of Untethered, Soft Robots, J arXiv preprint arXiv:.04723 2017. (http://refhub.elsevier.com/S0264-1275(19)30849-4/rf0725)
[146] A. Zolfagharian, et al., Pattern-driven 4D printing, J Sensors Actuators A: Physical 274 (2018) 231–243. (http://refhub.elsevier.com/S0264-1275(19)30849-4/rf0730)
[147] M. Bodaghi, A. Damanpack, W. Liao, Triple shape memory polymers by 4D printing, J Smart Materials Structures 27 (6) (2018) 065010. (http://refhub.elsevier.com/S0264-1275(19)30849-4/rf0735)
[148] X. Zhang, G. Wang, Q. Xu, Design, analysis and testing of a new compliant compound constant-force mechanism, Actuators, Multidisciplinary Digital Publishing Institute, 2018. (http://refhub.elsevier.com/S0264-1275(19)30849-4/rf0740)
[149] T. Chen, K. Shea, An autonomous programmable actuator and shape reconfigurable structures using bistability and shape memory polymers, J 3D Printing Additive Manufacturing 5 (2) (2018) 91–101. (http://refhub.elsevier.com/S0264-1275(19)30849-4/rf0745)
[150] H.Y. Jeong, et al., Multistable thermal actuators via multimaterial 4D printing, J Advanced Materials Technologies (2018) 1800495. (http://refhub.elsevier.com/S0264-1275(19)30849-4/rf0750)
[151] Y.F. Zhang, et al., Fast-response, stiffness-tunable soft actuator by hybrid multimaterial 3D printing, J Advanced Functional Materials (2019) 1806698. (http://refhub.elsevier.com/S0264-1275(19)30849-4/rf0755)
[152] M. Taghavi, et al., 3D-printed ready-to-use variable-stiffness structures, J IEEE Robotics Automation Letters 3 (3) (2018) 2402–2407. (http://refhub.elsevier.com/S0264-1275(19)30849-4/rf0760)
[153] Y. Yang, Y. Li, Y. Chen, Principles and methods for stiffness modulation in soft robot design and development, J Bio-Design Manufacturing Chemist (2018) 1–12. (http://refhub.elsevier.com/S0264-1275(19)30849-4/rf0765)
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

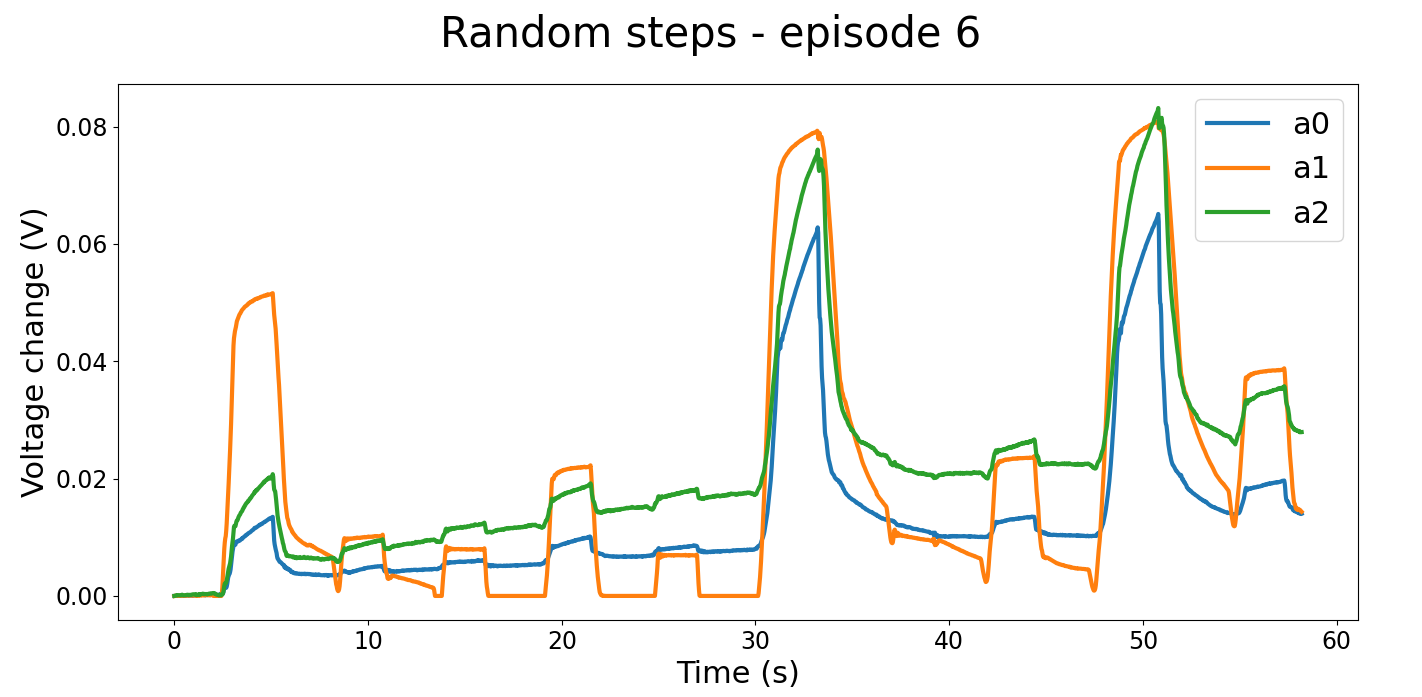
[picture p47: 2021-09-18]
images/random_steps_plots/random_steps_ep6.png

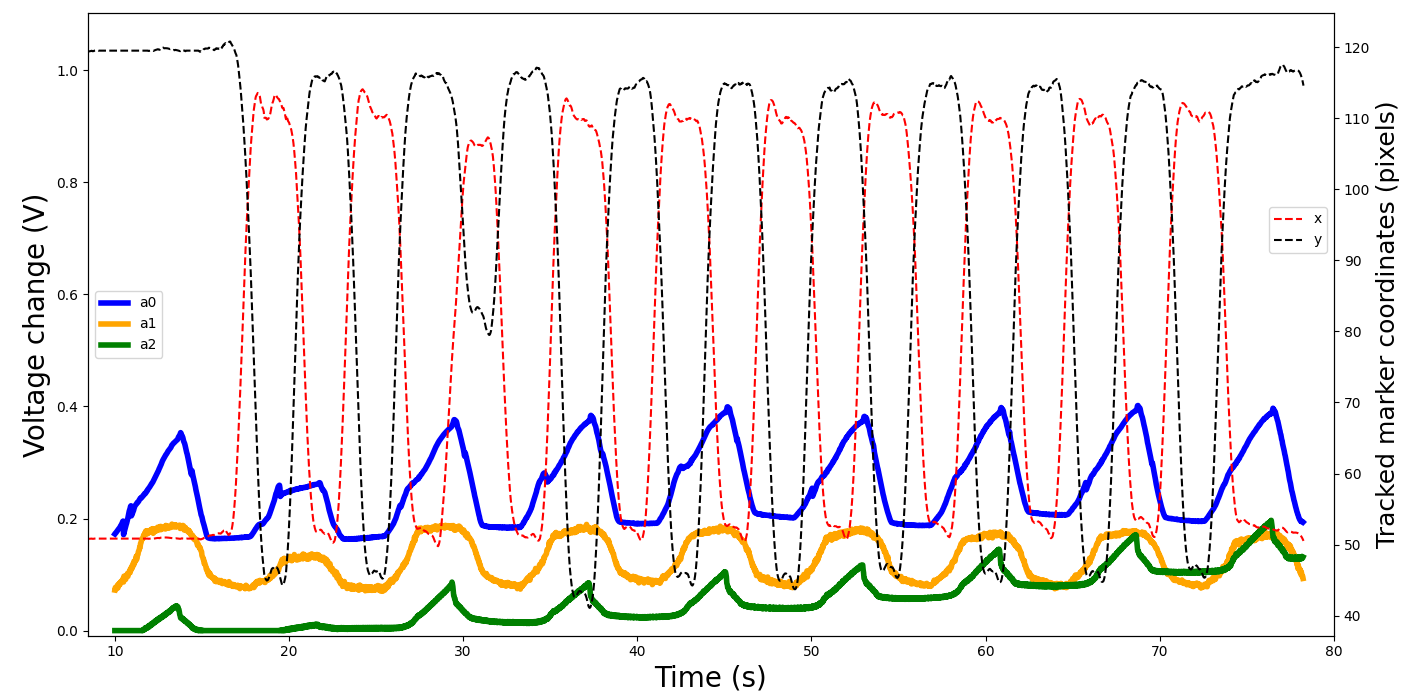
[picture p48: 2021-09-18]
images/35fast_chamber_100g_weight_plots/vertical_noweight_110_steps_EIT_data_w_xy_coord_values.png

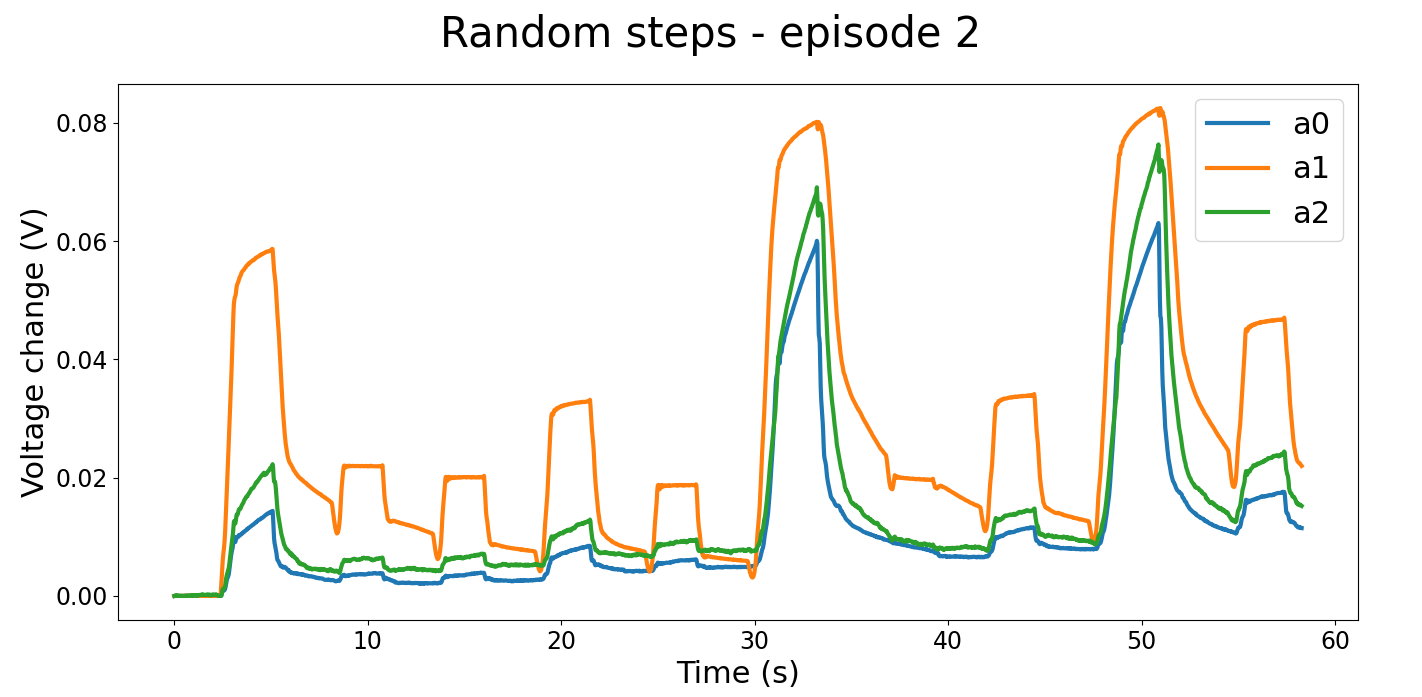
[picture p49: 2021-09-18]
images/random_steps_plots/random_steps_ep2.png

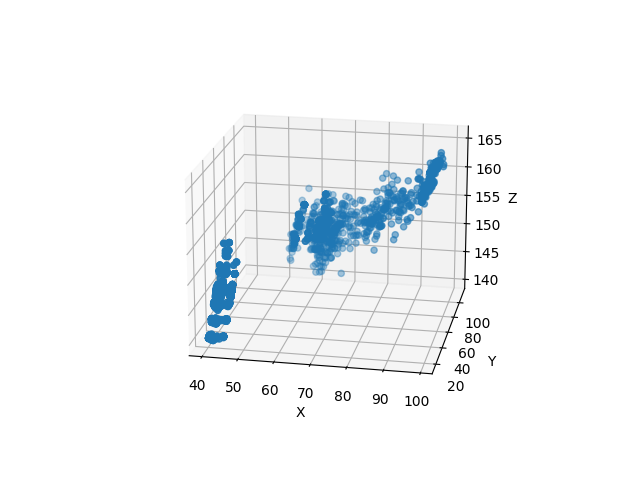
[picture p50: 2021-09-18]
images/copper_wire_actuator_35fast_chamber_100g_weight_lift_110_steps-2021-09-06-aruco_tracking_points.png

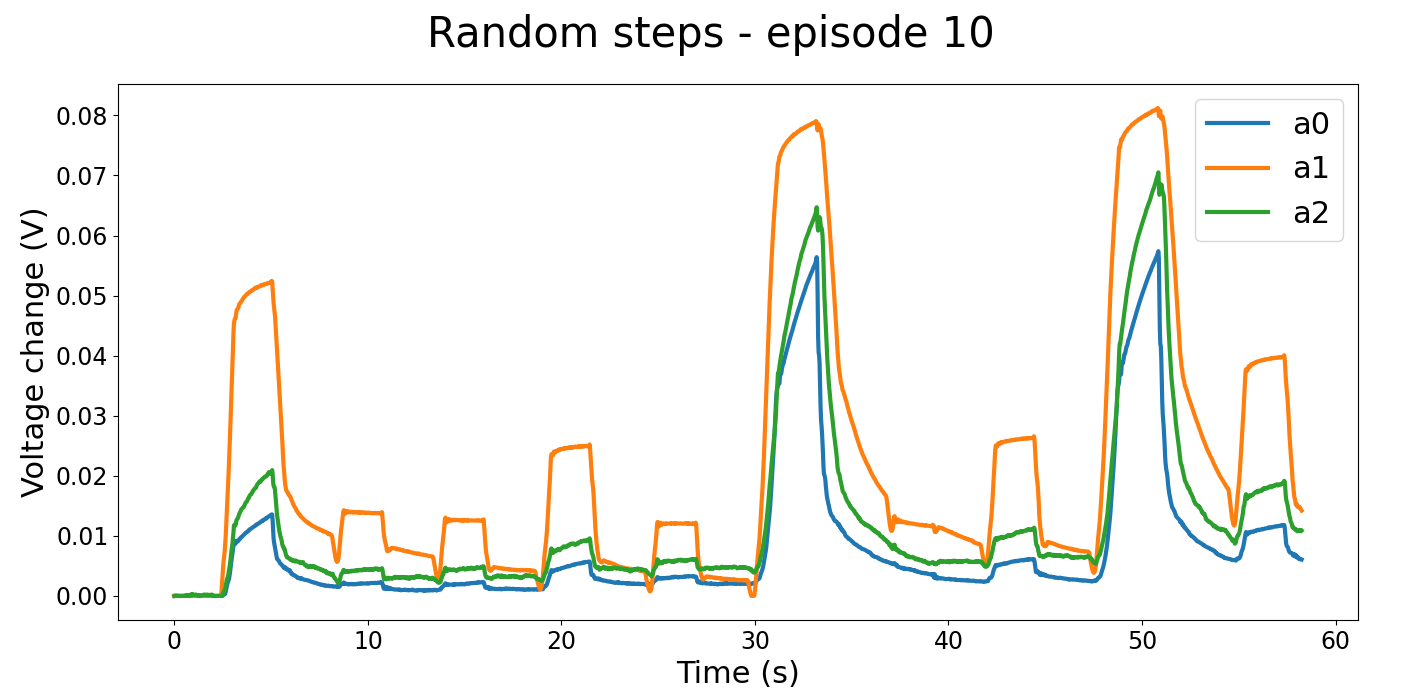
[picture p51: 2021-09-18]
images/random_steps_plots/random_steps_ep10.png

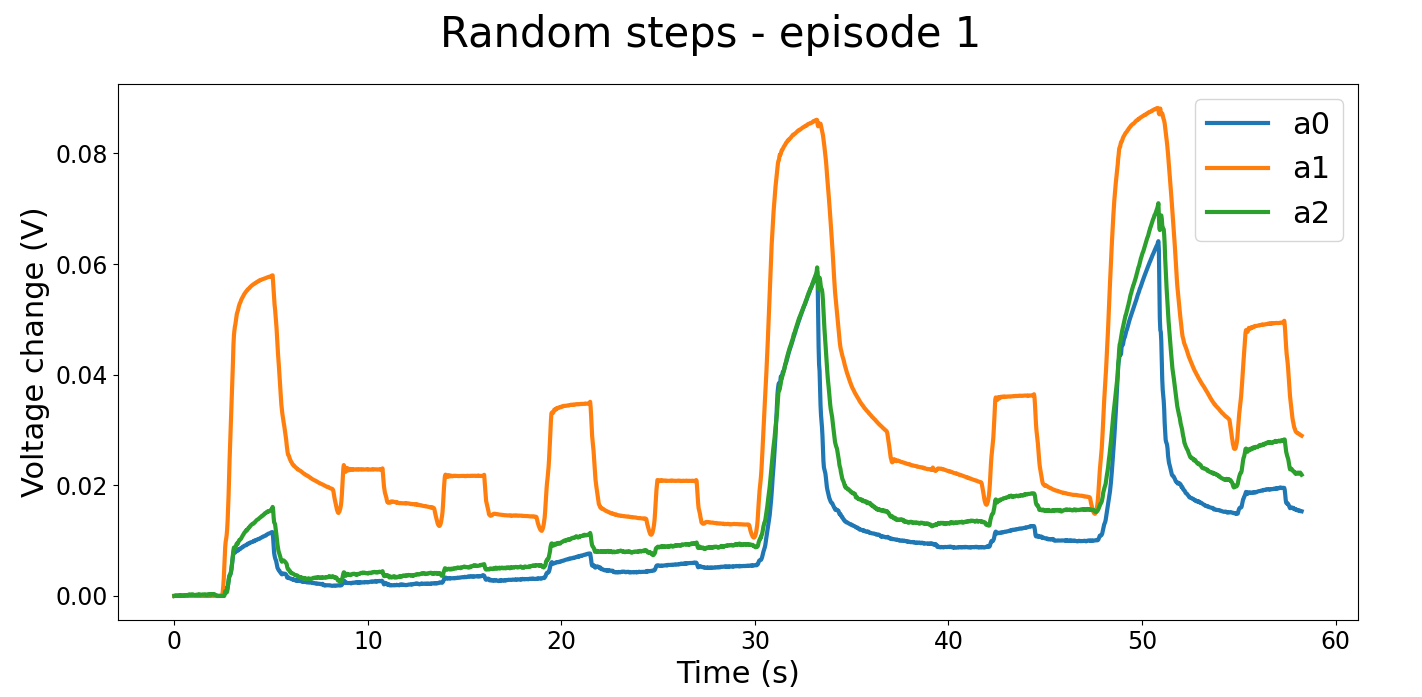
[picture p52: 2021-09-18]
images/random_steps_plots/random_steps_ep1.png

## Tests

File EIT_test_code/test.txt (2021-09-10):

#header text header text texty text text
0.161292	0.001741	0.001277	0.000341	0.723786	0.003754	0.000730	0.001083	0.767060
0.161303	0.001012	0.001359	0.000414	0.723939	0.003541	0.000749	0.001055	0.767181
0.161318	0.001287	0.001604	0.000389	0.723864	0.003594	0.000727	0.001104	0.766948
0.161300	0.001290	0.001245	0.000344	0.724009	0.003426	0.000723	0.001019	0.767022
0.161287	0.001291	0.001563	0.000358	0.723915	0.003484	0.000711	0.001065	0.767328
0.161339	0.000972	0.001519	0.000349	0.723936	0.003790	0.000711	0.001083	0.767091
0.161333	0.001009	0.001253	0.000403	0.724156	0.003577	0.000694	0.001061	0.767381
0.161303	0.000944	0.001256	0.000372	0.723893	0.003484	0.000722	0.001091	0.767467
0.161292	0.001464	0.001360	0.000406	0.723945	0.003747	0.000746	0.001068	0.767600
0.161326	0.001591	0.001363	0.000421	0.724308	0.003513	0.000725	0.001088	0.767660
0.161345	0.001552	0.001355	0.000417	0.724161	0.003424	0.000706	0.001146	0.767691
0.161304	0.000988	0.001548	0.000364	0.724049	0.003620	0.000700	0.001110	0.767665
0.161334	0.001728	0.001575	0.000394	0.723878	0.003463	0.000694	0.001129	0.767636
0.161361	0.001082	0.001536	0.000349	0.724033	0.003805	0.000734	0.001072	0.767484
0.161342	0.000908	0.001311	0.000333	0.724427	0.003574	0.000697	0.001036	0.767562
0.161352	0.000937	0.001449	0.000333	0.724198	0.003480	0.000697	0.001059	0.767608
0.161385	0.000889	0.001211	0.000378	0.724308	0.003450	0.000714	0.001023	0.767460
0.161373	0.001141	0.001220	0.000368	0.723905	0.003468	0.000721	0.001036	0.767632
0.161361	0.001360	0.001390	0.000418	0.723980	0.003428	0.000734	0.001094	0.767821
0.161366	0.002071	0.001350	0.000359	0.723801	0.003453	0.000716	0.001108	0.767902
0.161374	0.001647	0.001460	0.000359	0.724155	0.003488	0.000710	0.001117	0.767903
0.161345	0.000910	0.001545	0.000385	0.724135	0.003409	0.000738	0.000997	0.767968
0.161352	0.000883	0.001180	0.000354	0.724267	0.003497	0.000697	0.000999	0.768209
0.161358	0.001037	0.001497	0.000445	0.724162	0.003647	0.000710	0.001100	0.767978
0.161329	0.001389	0.001483	0.000550	0.724200	0.003815	0.000701	0.001084	0.768073
0.161363	0.001884	0.001273	0.000328	0.724407	0.003641	0.000707	0.001067	0.767865
0.161360	0.001100	0.001246	0.000370	0.724712	0.003434	0.000721	0.001089	0.768047
0.161347	0.002263	0.001328	0.000348	0.723914	0.003530	0.000720	0.001091	0.768015
0.161398	0.000932	0.001578	0.000352	0.724055	0.003487	0.000702	0.001036	0.767932
0.161363	0.002401	0.001311	0.000349	0.724184	0.003505	0.000738	0.001075	0.767780
0.161387	0.001218	0.001265	0.000361	0.724095	0.003521	0.000712	0.001057	0.768038
0.161380	0.000901	0.001540	0.000344	0.724569	0.003559	0.000727	0.001052	0.768225
0.161361	0.000933	0.001404	0.000377	0.724754	0.003424	0.000719	0.001123	0.768026
0.161399	0.001050	0.001487	0.000364	0.724546	0.003508	0.000734	0.001040	0.768394
0.161362	0.001011	0.001332	0.000363	0.724504	0.003705	0.000741	0.001090	0.768640
0.161349	0.000926	0.001540	0.000368	0.724147	0.003759	0.000736	0.001080	0.768210
0.161363	0.000915	0.001474	0.000368	0.724517	0.003701	0.000721	0.001096	0.768204
0.161393	0.001062	0.001273	0.000364	0.724665	0.003545	0.000729	0.001045	0.768680
0.161399	0.001524	0.001431	0.000381	0.724622	0.003543	0.000720	0.001057	0.768433
0.161368	0.000988	0.001311	0.000376	0.724639	0.003410	0.000710	0.001035	0.768501
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

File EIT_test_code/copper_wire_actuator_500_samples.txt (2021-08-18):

#header text header text texty text text
1.062787	0.007725	0.000855	0.002331	0.967712	0.004942	0.005671	0.002102	0.938294
1.062879	0.007746	0.000614	0.002343	0.967639	0.005075	0.005628	0.001942	0.938333
1.062855	0.007877	0.000681	0.002416	0.967625	0.005061	0.005647	0.002004	0.938264
1.063028	0.008062	0.000489	0.002492	0.967636	0.004906	0.005730	0.002092	0.938391
1.063125	0.008182	0.000472	0.002531	0.967585	0.004937	0.005654	0.002199	0.938235
1.063106	0.008225	0.000344	0.002431	0.967574	0.004857	0.005699	0.002255	0.938397
1.063128	0.008081	0.000204	0.002332	0.967553	0.004858	0.005653	0.002153	0.938398
1.063299	0.007966	0.000196	0.002281	0.967439	0.004978	0.005702	0.002032	0.938527
1.063395	0.007750	0.000301	0.002201	0.967543	0.004923	0.005695	0.001883	0.938595
1.063459	0.007798	0.000423	0.002322	0.967430	0.005060	0.005795	0.002054	0.938620
1.063580	0.007627	0.000587	0.002259	0.967414	0.004991	0.005754	0.002141	0.938739
1.063593	0.007676	0.000681	0.002291	0.967391	0.005012	0.005675	0.002167	0.938842
1.063754	0.008163	0.000860	0.002450	0.967450	0.004876	0.005738	0.002142	0.938952
1.063749	0.007952	0.000801	0.002304	0.967387	0.004789	0.005687	0.002038	0.938932
1.063738	0.007912	0.000779	0.002320	0.967431	0.004973	0.005735	0.001964	0.939099
1.063931	0.007771	0.000755	0.002350	0.967315	0.005049	0.005701	0.002088	0.939059
1.064058	0.007631	0.000728	0.002279	0.967282	0.004952	0.005709	0.002193	0.939116
1.064168	0.007726	0.000556	0.002387	0.967307	0.005161	0.005732	0.002125	0.939103
1.064294	0.007742	0.000409	0.002249	0.967240	0.005184	0.005660	0.001951	0.939037
1.064393	0.007729	0.000192	0.002357	0.967234	0.004957	0.005696	0.001952	0.939053
1.064440	0.007974	0.000331	0.002533	0.967284	0.004987	0.005741	0.002104	0.939138
1.064426	0.008185	0.000313	0.002549	0.967223	0.004749	0.005708	0.002179	0.939211
1.064572	0.008350	0.000443	0.002577	0.967331	0.004810	0.005749	0.002231	0.939341
1.064564	0.008179	0.000677	0.002399	0.967251	0.004715	0.005695	0.002162	0.939532
1.064637	0.008075	0.000792	0.002324	0.967167	0.004720	0.005689	0.002081	0.939500
1.064730	0.007897	0.000807	0.002295	0.967260	0.004870	0.005734	0.001937	0.939632
1.065258	0.008031	0.000694	0.002608	0.967085	0.004779	0.005779	0.002158	0.940355
1.065423	0.008192	0.000770	0.002587	0.967025	0.004856	0.005683	0.002156	0.940207
1.065453	0.008235	0.000727	0.002506	0.967115	0.004872	0.005755	0.002189	0.940218
1.065404	0.008170	0.000453	0.002437	0.966962	0.005010	0.005732	0.002106	0.940345
1.065566	0.007935	0.000361	0.002277	0.967072	0.004905	0.005731	0.002013	0.940369
1.065685	0.007825	0.000285	0.002332	0.966984	0.005007	0.005763	0.001925	0.940251
1.065852	0.007732	0.000392	0.002306	0.966900	0.004979	0.005766	0.002187	0.940291
1.065869	0.007642	0.000573	0.002390	0.966945	0.005000	0.005737	0.002248	0.940574
1.065959	0.007592	0.000787	0.002284	0.966918	0.004963	0.005735	0.002101	0.940621
1.065942	0.007740	0.000724	0.002259	0.966904	0.004968	0.005679	0.001944	0.940769
1.065993	0.007901	0.000708	0.002460	0.966799	0.004968	0.005694	0.002018	0.940711
1.066152	0.007966	0.000572	0.002577	0.966866	0.004977	0.005743	0.002151	0.940679
1.066155	0.008147	0.000466	0.002553	0.966760	0.004904	0.005775	0.002203	0.940606
1.066176	0.008227	0.000201	0.002514	0.966749	0.004917	0.005764	0.002202	0.940676
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

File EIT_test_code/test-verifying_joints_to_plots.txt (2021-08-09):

#header text header text texty text text
0.425620	0.000428	5.577856E-5	0.000415	0.218757	0.000309	0.000263	0.000363	0.211930
0.425590	0.000422	5.493880E-5	0.000254	0.218594	0.000303	0.000288	0.000365	0.211948
0.425584	0.000434	2.536871E-5	0.000282	0.218555	0.000314	0.000266	0.000325	0.211975
0.425606	0.000428	1.851787E-5	0.000291	0.218535	0.000321	0.000246	0.000358	0.211969
0.425571	0.000419	5.009509E-5	0.000262	0.218506	0.000316	0.000261	0.000317	0.211982
0.425593	0.000428	5.753980E-5	0.000351	0.218510	0.000309	0.000248	0.000358	0.212019
0.425591	0.000456	6.721716E-5	0.000332	0.218462	0.000281	0.000248	0.000314	0.211997
0.425531	0.000423	5.760812E-5	0.000327	0.218431	0.000311	0.000268	0.000344	0.212033
0.425558	0.000455	3.684850E-5	0.000312	0.218441	0.000314	0.000250	0.000329	0.212036
0.425562	0.000403	5.730850E-5	0.000309	0.218431	0.000318	0.000271	0.000355	0.212026
0.425566	0.000433	3.620204E-5	0.000252	0.218376	0.000332	0.000242	0.000343	0.212044
0.425529	0.000445	2.539201E-5	0.000360	0.218437	0.000267	0.000232	0.000344	0.212028
0.425533	0.000379	2.100529E-5	0.000294	0.218394	0.000323	0.000277	0.000357	0.212067
0.425514	0.000432	5.856207E-5	0.000267	0.218400	0.000326	0.000262	0.000321	0.212041
0.425508	0.000398	2.668689E-5	0.000325	0.218426	0.000311	0.000239	0.000345	0.212022
0.425553	0.000439	4.146523E-5	0.000370	0.218423	0.000290	0.000235	0.000352	0.212063
0.425565	0.000419	4.580220E-5	0.000380	0.218432	0.000275	0.000229	0.000397	0.212062
0.425500	0.000444	4.932573E-5	0.000262	0.218392	0.000296	0.000277	0.000344	0.212089
0.425501	0.000438	1.861225E-5	0.000306	0.218429	0.000289	0.000274	0.000327	0.212121
0.425484	0.000417	4.375101E-5	0.000318	0.218441	0.000324	0.000258	0.000364	0.212098
0.425505	0.000417	3.872029E-5	0.000322	0.218432	0.000278	0.000260	0.000359	0.212111
0.425501	0.000436	2.011316E-5	0.000290	0.218417	0.000280	0.000268	0.000347	0.212115
0.425489	0.000429	7.595871E-5	0.000306	0.218459	0.000296	0.000260	0.000365	0.212096
0.425433	0.000431	3.429121E-5	0.000283	0.218469	0.000296	0.000266	0.000356	0.212087
0.425470	0.000456	6.700578E-5	0.000306	0.218471	0.000298	0.000256	0.000368	0.212124
0.425447	0.000440	3.045781E-5	0.000290	0.218433	0.000313	0.000257	0.000361	0.212121
0.425447	0.000413	4.848336E-5	0.000274	0.218494	0.000292	0.000234	0.000359	0.212152
0.425457	0.000400	2.815167E-5	0.000358	0.218436	0.000279	0.000244	0.000381	0.212118
0.425457	0.000434	6.631780E-5	0.000289	0.218443	0.000329	0.000210	0.000359	0.212155
0.425454	0.000452	5.595905E-5	0.000284	0.218496	0.000338	0.000255	0.000339	0.212164
0.425473	0.000434	5.155992E-5	0.000293	0.218484	0.000294	0.000269	0.000358	0.212144
0.425436	0.000414	3.166264E-5	0.000347	0.218488	0.000298	0.000245	0.000335	0.212174
0.425411	0.000452	5.016226E-5	0.000309	0.218494	0.000286	0.000292	0.000355	0.212201
0.425402	0.000429	4.263814E-5	0.000289	0.218492	0.000319	0.000280	0.000330	0.212181
0.425418	0.000461	7.572522E-5	0.000276	0.218538	0.000263	0.000252	0.000345	0.212175
0.425396	0.000448	1.366905E-5	0.000360	0.218500	0.000289	0.000254	0.000333	0.212170
0.425415	0.000444	6.340637E-5	0.000336	0.218538	0.000321	0.000287	0.000333	0.212190
0.425401	0.000447	3.910714E-5	0.000303	0.218524	0.000324	0.000298	0.000353	0.212158
0.425380	0.000424	5.506430E-5	0.000307	0.218521	0.000271	0.000270	0.000333	0.212162
0.425420	0.000433	3.189304E-5	0.000278	0.218556	0.000279	0.000240	0.000348	0.212164
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

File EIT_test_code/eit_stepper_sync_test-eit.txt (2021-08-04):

#header text header text texty text text
8.612205E-5	2.059804E-5	4.048073E-5	2.943772E-5	4.446812E-5	4.271597E-5	8.416874E-5	2.296080E-5	3.726854E-5
0.000160	1.338303E-5	4.067941E-5	9.062879E-5	3.376638E-5	3.255060E-5	6.835593E-5	1.723161E-5	4.134623E-5
0.000101	4.083960E-5	3.214096E-5	7.327736E-5	3.169999E-5	3.636888E-5	9.299697E-5	3.206813E-5	3.103799E-5
6.767401E-5	4.289988E-5	3.345596E-5	7.794500E-5	3.410046E-5	3.701297E-5	6.497702E-5	2.239341E-5	3.248691E-5
8.948228E-5	3.656017E-5	4.521303E-5	8.112912E-5	1.468347E-5	1.419138E-5	7.514830E-5	2.396474E-5	3.755753E-5
0.000118	2.412323E-5	4.254542E-5	7.048577E-5	2.687823E-5	1.719263E-5	7.797547E-5	4.563901E-5	2.544481E-5
0.000175	2.774351E-5	4.547849E-5	4.725440E-5	2.391867E-5	4.049491E-5	0.000109	3.441211E-5	3.190779E-5
0.000107	5.762008E-5	3.549542E-5	0.000100	4.417286E-5	5.056645E-5	6.450845E-5	2.940716E-5	3.756138E-5
8.929991E-5	3.203174E-5	1.197908E-5	0.000114	1.140240E-5	5.434488E-5	0.000122	4.259724E-5	3.272385E-5
0.000150	5.173349E-5	2.543132E-5	9.780085E-5	4.039814E-5	2.859249E-5	4.169354E-5	2.808322E-5	2.928106E-5
0.000120	4.196078E-5	3.599852E-5	0.000123	3.900714E-5	6.399825E-5	6.262285E-5	3.609914E-5	2.190575E-5
0.000127	2.088088E-5	2.488453E-5	3.707362E-5	2.648482E-5	2.582970E-5	3.087564E-5	2.831922E-5	4.862095E-5
7.548878E-5	5.304548E-5	3.832457E-5	3.557400E-5	2.154248E-5	3.866293E-5	0.000100	3.480535E-5	3.442866E-5
0.000186	5.050986E-5	3.558759E-5	3.375448E-5	2.677700E-5	5.697529E-5	3.367483E-5	3.745153E-5	3.627530E-5
0.000176	4.261724E-5	5.430974E-5	0.000131	2.807496E-5	7.075888E-5	5.335831E-5	1.203506E-5	4.494511E-5
0.000156	3.424920E-5	5.420407E-5	6.914805E-5	2.604042E-5	1.763119E-5	8.070983E-5	2.150724E-5	5.311155E-5
6.274612E-5	2.993079E-5	2.285232E-5	0.000125	4.482730E-5	3.469735E-5	6.622712E-5	1.535256E-5	5.070826E-5
7.294311E-5	3.106768E-5	3.165950E-5	6.336743E-5	2.776271E-5	5.256040E-5	5.002730E-5	4.641745E-5	3.839275E-5
0.000145	2.423860E-5	3.690769E-5	7.570398E-5	4.586342E-5	5.261081E-5	6.004285E-5	5.066580E-5	4.247647E-5
0.000149	2.922419E-5	3.690545E-5	0.000131	4.770924E-5	3.125525E-5	5.338124E-5	1.768193E-5	3.559903E-5
9.389971E-5	3.973458E-5	3.134168E-5	9.119442E-5	3.316260E-5	2.026129E-5	8.776120E-5	4.621543E-5	3.681046E-5
5.947222E-5	2.811485E-5	4.000638E-5	8.175097E-5	2.807921E-5	4.755321E-5	7.532095E-5	3.192539E-5	3.264215E-5
0.000131	5.481164E-5	3.214472E-5	9.982229E-5	3.712249E-5	3.098515E-5	0.000113	2.226575E-5	4.458887E-5
0.000121	2.562011E-5	2.974722E-5	5.393621E-5	2.721320E-5	3.226828E-5	9.397504E-5	5.412533E-5	4.212951E-5
7.342011E-5	2.692785E-5	2.583254E-5	9.939465E-5	1.638306E-5	4.963046E-5	5.888464E-5	4.169265E-5	1.863858E-5
0.000163	6.683766E-5	3.038342E-5	5.521668E-5	2.078082E-5	7.732846E-5	5.732016E-5	3.989668E-5	1.903555E-5
0.000106	1.792437E-5	2.711926E-5	6.913618E-5	2.265930E-5	2.513355E-5	3.552563E-5	2.071423E-5	3.018215E-5
0.000106	1.835401E-5	4.660508E-5	4.382473E-5	5.282312E-5	3.207222E-5	4.073122E-5	3.066391E-5	1.947793E-5
9.263792E-5	3.305103E-5	3.515717E-5	7.154471E-5	3.282837E-5	5.731157E-5	7.065284E-5	3.863416E-5	6.601059E-5
0.000130	4.671109E-5	2.450030E-5	2.913354E-5	3.740819E-5	1.467710E-5	9.809558E-5	2.674631E-5	5.098526E-5
0.000168	1.874887E-5	3.104452E-5	0.000114	2.633374E-5	3.972787E-5	4.196625E-5	5.610758E-5	4.497716E-5
0.000102	3.690205E-5	2.315447E-5	7.494799E-5	3.455854E-5	1.740822E-5	6.131642E-5	2.814057E-5	3.589208E-5
0.000319	2.739340E-5	4.609833E-5	5.285884E-5	1.824415E-5	3.540904E-5	7.148779E-5	3.843757E-5	2.568915E-5
0.000182	1.955355E-5	2.406226E-5	9.391088E-5	5.118062E-5	3.459365E-5	8.532871E-5	1.764781E-5	3.956707E-5
0.000163	3.731388E-5	3.052501E-5	5.937860E-5	2.984173E-5	3.643062E-5	7.242565E-5	2.962177E-5	2.750341E-5
0.000113	1.522926E-5	2.534411E-5	6.694226E-5	2.431312E-5	6.781789E-5	6.888937E-5	2.514907E-5	4.714966E-5
8.103217E-5	2.062944E-5	4.176608E-5	8.503837E-5	2.706171E-5	3.781378E-5	7.691201E-5	3.130707E-5	4.275793E-5
0.000138	2.579659E-5	2.095081E-5	8.676333E-5	3.347378E-5	4.042517E-5	6.244300E-5	3.799737E-5	3.450695E-5
0.000125	2.072980E-5	2.610940E-5	7.731119E-5	4.137959E-5	3.289610E-5	6.977224E-5	2.735335E-5	3.755169E-5
0.000174	3.639889E-5	2.606892E-5	7.891500E-5	6.112480E-5	4.940281E-5	0.000133	1.935987E-5	4.678774E-5
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

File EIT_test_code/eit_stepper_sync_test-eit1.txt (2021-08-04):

#header text header text texty text text
0.000104	3.014328E-5	3.866490E-5	8.016151E-5	5.188383E-5	4.279058E-5	8.745894E-5	4.234647E-5	2.853506E-5
0.000104	2.885377E-5	1.948468E-5	0.000168	4.616630E-5	3.455943E-5	4.545396E-5	2.543258E-5	3.829684E-5
0.000164	5.544064E-5	3.764855E-5	7.571063E-5	6.044624E-5	2.372274E-5	9.448800E-5	4.088899E-5	3.615736E-5
9.255814E-5	3.246174E-5	3.237957E-5	9.447939E-5	4.860216E-5	2.626336E-5	8.395456E-5	5.238274E-5	3.140620E-5
0.000140	4.411644E-5	1.209813E-5	0.000105	2.634511E-5	3.129676E-5	4.134590E-5	5.653107E-5	4.158748E-5
9.828154E-5	3.619186E-5	2.914044E-5	9.532789E-5	2.885740E-5	3.820934E-5	7.900899E-5	5.371326E-5	2.307155E-5
6.530372E-5	3.497898E-5	1.820343E-5	0.000145	3.518331E-5	4.276181E-5	5.284966E-5	5.439474E-5	3.438436E-5
0.000149	5.268869E-5	3.042925E-5	0.000155	4.516680E-5	2.934000E-5	9.938692E-5	4.100149E-5	2.298731E-5
0.000141	0.000100	1.662461E-5	7.901920E-5	7.072156E-5	3.358053E-5	7.462903E-5	3.222871E-5	1.614547E-5
0.000163	5.852234E-5	5.937007E-5	9.573825E-5	4.568577E-5	4.393297E-5	2.040720E-5	3.122432E-5	4.073199E-5
0.000145	4.405692E-5	1.921846E-5	8.237994E-5	6.186622E-5	2.623956E-5	8.107552E-5	3.860441E-5	2.819902E-5
3.785462E-5	2.289198E-5	3.211312E-5	0.001917	0.000205	0.000120	1.609356E-5	3.871850E-5	4.624382E-5
4.614312E-5	2.435082E-5	6.187770E-5	0.002004	0.000269	0.000143	4.393791E-5	3.900886E-5	4.066054E-5
0.000273	5.789579E-5	3.760834E-5	0.000888	0.000121	6.271379E-5	4.727196E-5	7.003387E-5	4.070591E-5
9.726802E-5	4.393278E-5	3.726051E-5	0.000110	2.399610E-5	6.030540E-5	8.400639E-5	5.787467E-5	1.472477E-5
0.000120	4.959403E-5	3.416734E-5	0.000115	4.344165E-5	3.897942E-5	5.873254E-5	3.431356E-5	6.569869E-5
6.098243E-5	5.391668E-5	3.916111E-5	7.472842E-5	5.797745E-5	4.290261E-5	8.559726E-5	6.128565E-5	3.266228E-5
4.462747E-5	3.560010E-5	3.512743E-5	7.355750E-5	3.314724E-5	3.621928E-5	8.102218E-5	2.813742E-5	2.751691E-5
0.000104	3.048696E-5	6.792511E-5	4.825856E-5	2.481988E-5	5.797773E-5	7.899347E-5	3.438284E-5	2.193766E-5
0.000108	4.090466E-5	4.017585E-5	0.000127	2.473734E-5	3.208298E-5	6.800791E-5	2.139226E-5	3.762706E-5
9.419212E-5	1.564279E-5	1.465481E-5	8.762861E-5	6.731444E-5	3.375567E-5	9.375282E-5	4.409322E-5	2.495909E-5
0.000109	2.346112E-5	4.064199E-5	6.433456E-5	3.375604E-5	3.987050E-5	7.827389E-5	3.701444E-5	5.876449E-5
7.645820E-5	3.943420E-5	4.869634E-5	6.705606E-5	2.844841E-5	3.328816E-5	6.024192E-5	2.707743E-5	4.926449E-5
8.482254E-5	7.466902E-5	7.308526E-5	0.000116	7.357244E-5	5.711283E-5	7.978949E-5	2.234663E-5	2.268665E-5
6.306409E-5	4.069591E-5	4.711991E-5	5.793341E-5	1.734065E-5	3.516395E-5	0.000132	6.659812E-5	3.619908E-5
5.916640E-5	4.740188E-5	3.882664E-5	9.304183E-5	5.320540E-5	3.818428E-5	0.000147	5.098096E-5	5.461661E-5
0.000168	2.392445E-5	3.581311E-5	9.601758E-5	2.426198E-5	2.792282E-5	4.711308E-5	6.191127E-5	2.916314E-5
0.000153	4.182242E-5	2.391994E-5	0.000173	3.865135E-5	5.436988E-5	7.945131E-5	7.205775E-5	5.037263E-5
9.930079E-5	2.913928E-5	3.293944E-5	4.133568E-5	5.377876E-5	1.540979E-5	8.249769E-5	4.499836E-5	4.879968E-5
0.000115	3.214190E-5	1.555371E-5	6.321046E-5	1.430844E-5	3.141086E-5	7.686487E-5	2.247359E-5	6.037895E-5
0.000133	2.702831E-5	4.676125E-5	0.000119	6.950008E-5	5.835805E-5	9.871449E-5	6.361035E-5	4.042923E-5
7.975961E-5	4.133123E-5	5.698574E-5	7.252521E-5	4.509903E-5	3.007801E-5	0.000126	3.203540E-5	4.729516E-5
0.000124	4.375227E-5	3.965971E-5	0.000161	2.993351E-5	5.817812E-5	3.855929E-5	2.939324E-5	3.844527E-5
6.286568E-5	1.935945E-5	5.136704E-5	9.222467E-5	5.064508E-5	4.041233E-5	6.467109E-5	3.217139E-5	6.255699E-5
0.000111	3.013286E-5	3.622025E-5	6.447284E-5	4.078916E-5	3.998452E-5	0.000112	2.862528E-5	8.240555E-5
0.000111	6.269240E-5	3.474114E-5	0.000119	4.915934E-5	5.841088E-5	0.000130	2.655692E-5	3.006949E-5
0.000115	1.721532E-5	4.100537E-5	6.700359E-5	3.502601E-5	3.396314E-5	4.273807E-5	4.840654E-5	2.502254E-5
7.120483E-5	4.128142E-5	1.750120E-5	6.029201E-5	3.965096E-5	5.482400E-5	5.893638E-5	5.045666E-5	4.943862E-5
3.694269E-5	4.965050E-5	4.160964E-5	8.191640E-5	6.557544E-5	3.853460E-5	0.000102	3.909525E-5	4.116440E-5
7.177060E-5	3.174330E-5	3.190437E-5	0.000122	9.276573E-5	2.402041E-5	7.924967E-5	5.018276E-5	4.580342E-5
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

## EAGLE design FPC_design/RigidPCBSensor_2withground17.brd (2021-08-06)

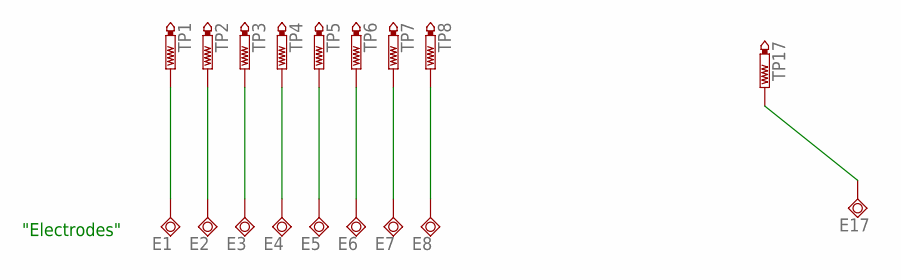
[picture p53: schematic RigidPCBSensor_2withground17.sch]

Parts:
E1, E2, E3, E4, E5, E6, E7, E8, E17: TPSQTP15R; TP15R
TP1, TP2, TP3, TP4, TP5, TP6, TP7, TP8, TP17: PTR1; TP10SQLONG

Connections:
unnamed: E1.TP, TP1.TP
unnamed: E2.TP, TP2.TP
unnamed: E3.TP, TP3.TP
unnamed: E4.TP, TP4.TP
unnamed: E5.TP, TP5.TP
unnamed: E6.TP, TP6.TP
unnamed: E7.TP, TP7.TP
unnamed: E8.TP, TP8.TP
unnamed: E17.TP, TP17.TP

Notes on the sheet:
"Electrodes"

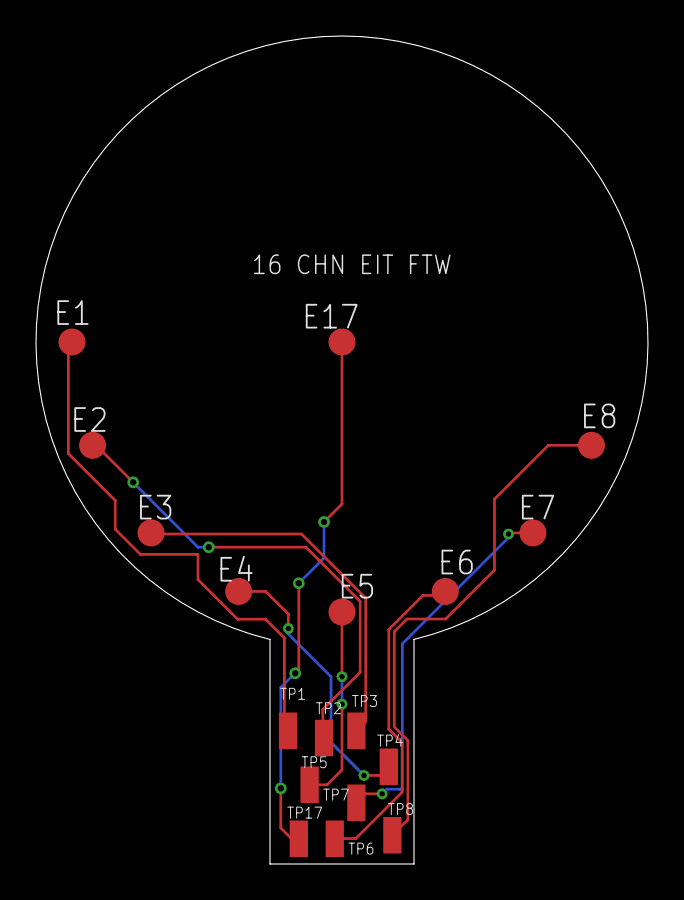
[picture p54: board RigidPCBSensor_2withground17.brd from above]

Board: 2 copper layers, 34.0 x 46.0 mm, 18 parts (0 on the bottom side), 9 nets.

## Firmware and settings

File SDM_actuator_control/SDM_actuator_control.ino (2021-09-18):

/**
 * Author Teemu Mäntykallio
 * Initializes the library and turns the motor in alternating directions.
 * Modified by Charles DeLorey for master's thesis project, Hamlyn Centre ICL 2020-2021
*/

// make sure under Tools > Board it's Board: Arduino Due (Programming Port)

#define EN_PIN      4    // Nano v3:	16 Mega:	38	//enable (CFG6)
#define DIR_PIN     6    //			19			55	//direction
#define STEP_PIN    5    //			18			54	//step
#define CS_PIN      7    //			17			64	//chip select
#define TRIGGER_PIN 22   // pin for activating EIT system
#define CAM_PIN     26   // pin for syncing webcam footage

const int stepsPerRevolution = 200;  // change this to fit 
// the number of steps per revolution for your stepper

int receivedVal         = 0;
boolean newData         = false;
double spool_diam       = 31.4159;
double steps_per_1mm    = 1 / (spool_diam / stepsPerRevolution);
int microstps           = 2;
int iters               = 0;
unsigned int curr_steps = 0;
int trigger_freq        = 40; // Hz

String shakeInput       = "";
char* shakeKey          = "S";
bool shakeFlag          = false;
float timeAtStep        = 0;
String flushInputBuffer = "";
char* data              = "";
int   randStep          = 0;

int loopcount=0;

#include <DueTimer.h>
#include <TMC2130Stepper.h>
TMC2130Stepper driver = TMC2130Stepper(EN_PIN, DIR_PIN, STEP_PIN, CS_PIN);

void setup() {
	Serial.begin(115200);
	while(!Serial);
	SPI.begin();
	pinMode(MISO, INPUT_PULLUP);
	driver.begin(); 			    // Initiate pins and registeries
	driver.rms_current(600); 	// Set stepper current to 600mA. The command is the same as command TMC2130.setCurrent(600, 0.11, 0.5);
	driver.stealthChop(1); 	  // Enable extremely quiet stepping
	
	digitalWrite(EN_PIN, LOW);
  driver.microsteps(microstps);
//  Serial.print("Microsteps: "); Serial.println(driver.microsteps());
  pinMode(TRIGGER_PIN, OUTPUT);
  pinMode(CAM_PIN, OUTPUT);
  Timer3.attachInterrupt(triggerReading).setFrequency(trigger_freq);
//  Serial.print("Trigger freq: "); Serial.print(trigger_freq); Serial.println(" Hz");
//  Serial.print("Curr steps: "); Serial.println(curr_steps);
//  Serial.print("Available bytes: "); Serial.println(Serial.availableForWrite());

  Timer3.start();
  digitalWrite(CAM_PIN, HIGH);
}


void loop() {   // DON'T FORGET SHAFT_DIR

// ** the stepper works better at 256 microsteps
// oneFlex() and oneRelax() only for when microsteps != 0

//  recvOneVal();
//  if(newData == true) {
//    if(receivedVal == -1) {
//      digitalWrite(CAM_PIN, HIGH);
//      delay(2 * 1000);
//      digitalWrite(CAM_PIN, LOW);
//      Serial.println(receivedVal);
//      newData = false;
//      Serial.flush();
//    }
//  } 

//  randStep = random(20, 101);

  if (iters == 10) {
    digitalWrite(CAM_PIN, LOW);
    Timer3.stop();
    loopcount=0;
    Serial.println(-1);
    iters++; //only run it once
  }

  if (iters < 10) {
    delay(2000);
    oneFlex(100,  4000);
    delay(2000);
    oneRelax(100, 4000);
    //delay(1000);
    iters++;
  }


  //recvOneVal();
//  receivedVal = 100;
//  newData = true;

//  if (newData == true) {
    //Serial.print("# iterations: "); Serial.println(receivedVal);
//    Timer3.start();
//    while (true) {
//      Serial.print("Iteration: "); Serial.println(iters+1);
//      actuateInStages(true, 2, 134, 2000, 40);
//      delay(2000);
//      actuateInStages(false, 2, 134, 2000, 40);
//      delay(2000);      
      //delayWithSampling(2000, 40);

//      delay(4000);
//      oneFlex(receivedVal, 1000);
      //Serial.print("ACTUAL curr_steps after Flex: "); Serial.println(curr_steps/2);
//      delay(4000);
//      oneFlex(67, 40);
//      delay(4000);
//      oneRelax(receivedVal, 1000);
    //Serial.print("ACTUAL curr_steps after relax: "); Serial.println(curr_steps/2);

//      oneRelax(67, 40);
//      delay(4000);

//    iters++;
//    }
//    newData = false;
//    Timer3.stop();
//    if (iters == receivedVal) {
//      Timer3.stop();
//    }
//  }
}


void triggerReading(){
  digitalWrite(TRIGGER_PIN, HIGH);
  //loopcount++;

  //if (loopcount % 10 == 0)
  //{
    //Serial.print(loopcount);
    //Serial.print(",");
  Serial.println(curr_steps/2);    // sending step val to pyserial
  //}
  digitalWrite(TRIGGER_PIN, LOW);
}

void recvOneVal() {
  if (Serial.available() > 0) {
    receivedVal = Serial.parseInt();
    newData = true;
  }
}


//* could use another arduino pin to measure/signal the movement/motion of the stepper
//  could setup other program on daq to record voltage on direction pin
//  or record digital pin direction pin
//  do loop multiple times and then calculate functional loop speed

// oneFlex : params: 
// - steps is the number of stepper steps the motor will turn
// - rate is the trigger rate for the DAQ sampling
void oneFlex(int steps, int dly) { //can drop this speed of data collection to make sure it's definitely synchronised with the data collection
  driver.shaft_dir(0);
  for (int i=0; i < steps * microstps; i++) {
    curr_steps++;
    digitalWrite(STEP_PIN, HIGH);
    delayMicroseconds(dly);
    digitalWrite(STEP_PIN, LOW);
    delayMicroseconds(dly); 
  }
}

// oneRelax : params: 
// - steps is the number of stepper steps the motor will turn
// - rate is the trigger rate for the DAQ sampling
void oneRelax(int steps, int dly) {
  driver.shaft_dir(1);
  for (int i=0; i < steps * microstps; i++) {
    curr_steps--;
    digitalWrite(STEP_PIN, HIGH);
    delayMicroseconds(dly);
    digitalWrite(STEP_PIN, LOW);
    delayMicroseconds(dly); 
  }
}

// **the number of stages must be a divisor of steps
void actuateInStages(bool flex, int stages, int steps, int dly, int rate) {
  if (flex) {
    for (int i=0; i < stages; i++) {
      oneFlex(steps/stages, rate);
      delay(dly);
    }
  } else {
    for (int i=0; i < stages; i++) {
      oneRelax(steps/stages, rate);
      delay(dly);      
    }
  }
}

double stepToDist(int steps) {
  // Takes distance in steps and converts it to the
  // corresponding millimeter change given the spool diameter
  return steps / steps_per_1mm;
}

int distToStep(int dist) {
  // Takes distance in mm and converts it to the
  // corresponding number of steps given the spool diameter
  return dist * steps_per_1mm;
}


void handShake() {
  while (Serial.available() > 0) {
    shakeInput = Serial.readStringUntil('\n');
    if (shakeInput != ""){
//      sprintf(data, "%s\n", shakeKey);
      Serial.println(shakeInput);
      Serial.flush();
//        shakeFlag = true;
        // Enable the motor after handshaking
//        digitalWrite(TRIGGER_PIN, HIGH);
//        shakeInput = "";
        // Initialise the time variables
//        timeAtStep = micros();
//        flushInputBuffer = Serial.readStringUntil('\n');
    }
  }
}

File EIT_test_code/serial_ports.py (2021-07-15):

# serial ports getter

import sys
import glob
import serial

def serial_ports():
    """ Lists serial port names

        :raises EnvironmentError:
            On unsupported or unknown platforms
        :returns:
            A list of the serial ports available on the system
    """
    if sys.platform.startswith('win'):
        ports = ['COM%s' % (i + 1) for i in range(256)]
    elif sys.platform.startswith('linux') or sys.platform.startswith('cygwin'):
        # this excludes your current terminal "/dev/tty"
        ports = glob.glob('/dev/tty[A-Za-z]*')
    elif sys.platform.startswith('darwin'):
        ports = glob.glob('/dev/tty.*')
    else:
        raise EnvironmentError('Unsupported platform')

    result = []
    for port in ports:
        try:
            s = serial.Serial(port)
            s.close()
            result.append(port)
        except (OSError, serial.SerialException):
            pass
    return result


if __name__ == '__main__':
    print(serial_ports())

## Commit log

2021-03-11 start dedicated thesis repo
    [SensorAssumpModel-v1.STEP, SensorChamber.STEP, SensorChamberSingle.STEP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]
2021-03-11 simulation work
    [finger_one_bend.STEP, finger_one_bend.ipt, finger_straight.STEP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]
2021-03-16 made hollow version
    [finger_one_bend_hollow.STEP, finger_one_bend_hollow.ipt, finger_straight_hollow.STEP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]
2021-03-19 Fixed electrode assignment and FWD model check errors in bent finger example
2021-03-20 two bend finger model
    [finger_two_bend_hollow.STEP, finger_two_bend_hollow.ipt]
2021-03-25 made simple pneunet mesh
    [pneunet_approximate_test.STEP, pneunet_approximate_test.ipt]
2021-03-26 organize and make bent pneunet actuator sim
    [bent_finger_model.STEP, bent_finger_model.ipt, bent_finger_model.stl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]
2021-03-29 second bend pneunet EIDORS model
    [pneunet_approximate_test_second_bend.STEP, pneunet_approximate_test_second_bend.ipt]
2021-04-06 inflated chambers EIDORS model
    [pneunet_approximate_test_first_bend_INFLATE.STEP, pneunet_approximate_test_first_bend_INFLATED.ipt]
2021-04-14 meeting on 14/04/21
    [3D_print_actuator.0007.ipt, 3D_print_actuator.ipt, 3D_print_actuator.stl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]
2021-04-19 actuator videos
    [3D_print_actuator.0007.ipt, 3D_print_actuator.0016.ipt, 3D_print_actuator.ipt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]
2021-04-21 single chamber EIDORS work
    [3D_print_actuator.ipt, 3D_print_actuator.stl, 3D_print_actuator_cross-section.stl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]
2021-04-22 single chamber stl
    [3D_print_actuator_truncated.0018.ipt, 3D_print_actuator_truncated.ipt, 3D_print_actuator_truncated.stl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]
2021-04-26 plot labview data
    [3D_print_single_chamber.0020.ipt, 3D_print_single_chamber.0021.ipt, 3D_print_single_chamber.ipt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]
2021-05-05 actuator tube eit data
2021-05-05 general update after weekly meeting
    [3D_print_actuator.0018.ipt, 3D_print_actuator.0020.ipt, 3D_print_actuator.ipt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]
2021-05-10 actuator EIT data
2021-05-17 eit chamber test data
2021-05-25 actuator test eit data
2021-05-28 SDM finger development
    [3D_print_actuator_cable_driven.0003.ipt, 3D_print_actuator_cable_driven.ipt, 3D_print_actuator_cable_driven.stl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]
2021-06-03 sdm actuator eit test
2021-06-03 fixed sdm actuator eit data
2021-06-03 sdm actuator eit data better
    [actuator_bone_joint.0004.ipt, actuator_bone_joint.ipt, actuator_bone_joint_cylinder_spine.stl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]
2021-06-07 parsed/trimmed down actuator data
    [actuator_bone_joint.0004.ipt, actuator_bone_joint.0005.ipt, actuator_bone_joint.ipt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]
2021-06-23 actuator stepper control
    [RigidPCBSensor_2withground17.brd, RigidPCBSensor_2withground17.sch, SDM_actuator_mount.0005.ipt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]
2021-06-29 preliminary full stepper tests
2021-07-06 OpenCV red shape tracking work
    [camera_mount.ipt, camera_mount.stl, eit_electrode_board_mounting_base.stl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]
2021-07-09 wire impedance measurements with DAQ
2021-07-15 CV progress
    [SDM_actuator_mount.0005.ipt, SDM_actuator_mount.0007.ipt, SDM_actuator_mount.ipt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]
2021-07-23 finish cv and neaten up
    [SDM_actuator_mount.0007.ipt, SDM_actuator_mount.0008.ipt, SDM_actuator_mount.ipt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]
2021-08-04 comp vision work
    [RigidPCBSensor_2withground17.brd, RigidPCBSensor_2withground17.sch, actuator_bone_joint.0006.ipt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]
2021-08-09 eit data to verify joints
2021-08-17 500 samples test
2021-08-17 pres updates and actuator progress
    [actuator_bone_joint.0007.ipt, actuator_bone_joint.0008.ipt, actuator_bone_joint.ipt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]
2021-08-17 actuator 40Hz eit data
2021-08-18 upload data, fix git access issue
    [SDM_actuator_mount.0008.ipt, SDM_actuator_mount.0010.ipt, SDM_actuator_mount.ipt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]
2021-08-20 camera calib work
    [cameraparams-intrinsic_parameters.csv, cameraparams-rotation_vectors.csv, cameraparams-rotation_vectors.txt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]
2021-08-24 joint-angle measuring w protractor
2021-08-25 aruco work and actuator modeling
    [10mm_square.stl, 7mm_square.stl, SDM_actuator_mount.0010.ipt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]
2021-08-26 redid a0 joint angle acquisition
2021-08-26 actuator iteration experiments
2021-09-02 prelim fixed actuator data
2021-09-02 a2 bend voltages
2021-09-06 vertical actuator experiments
2021-09-06 eit chamber glove experiments
2021-09-08 35fast chamber lookup tbl and experiments
2021-09-10 fixed a0 actuator experiments
2021-09-10 actuator rand step experiments
2021-09-18 thesis submission update
    [LONG-actuator_backbone_fixings_for_measurements.stl, SDM_actuator_mount.0014.ipt, SDM_actuator_mount.0015.ipt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]
